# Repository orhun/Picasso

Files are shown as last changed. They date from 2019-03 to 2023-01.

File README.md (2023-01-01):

# Picasso 
PIC16F877A based 5V/20MHz development board and PIC programmer

**[!] This is a discontinued project. [2016]**
_Documents are published in order to help people that want to create similar projects or think of new ideas._

# Idea

Programming Microchip's PIC (_peripheral interface controller_)'s and preparing 
electronic circuit board takes time and also inconvenient in circuit testing process. 
In other words, using the appropriate PIC programmer and creating the proper circuit board according to
desired PIC's datasheet is not practical for situations that needs quick actions like prototyping.
In addition to that there is platforms like [Arduino](https://www.arduino.cc), so PIC is not preferable
except embedded applications.

Therefore, idea behind this project is creating a development board/prototyping platform using PIC.

# How?

[Sprut](https://www.sprut.de) is a project that aims to produce PIC programmer hardware with 
serial, parallel and USB techniques. 
(see [Brenner](http://www.sprut.de/electronic/pic/brenner/index.htm))
_Sprut Brenner_ is a preferred and common programmer board for universal PIC applications.

_Brenner board that I was using:_

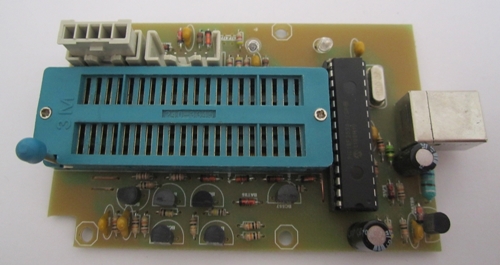
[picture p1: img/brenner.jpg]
sprut brenner


There is a 40 pin programmer on board for supporting most of the PIC's. The board itself uses PIC18F2550
(see [datasheet](http://ww1.microchip.com/downloads/en/DeviceDoc/39632e.pdf)) for communication
with software.

PIC16F877A (see [datasheet](http://ww1.microchip.com/downloads/en/devicedoc/39582b.pdf)) is a 40-pin microcontroller 
which is used frequently on PIC domain. (It has 256 bytes of EEPROM, 2 PWM 10-bit, ICD etc.)
This features of 877A was the main reason for my decision to use this microcontroller in this project.

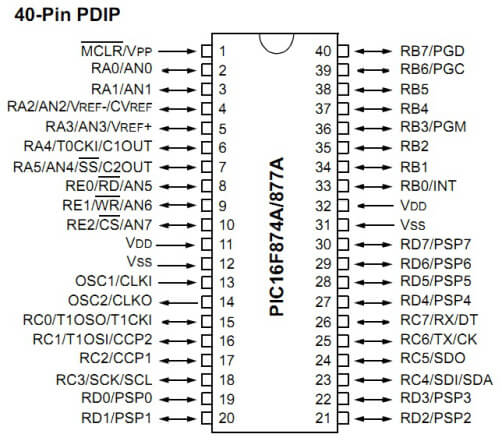
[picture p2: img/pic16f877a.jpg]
pic16f877a


In order to load your program to PIC (which is called _flashing hex file_) you have to use a software called _US-Burn_.
US-Burn also supports various features such as flashing bootloaders, changing PIC configurations and disassembler.
It has Windows and Linux support.

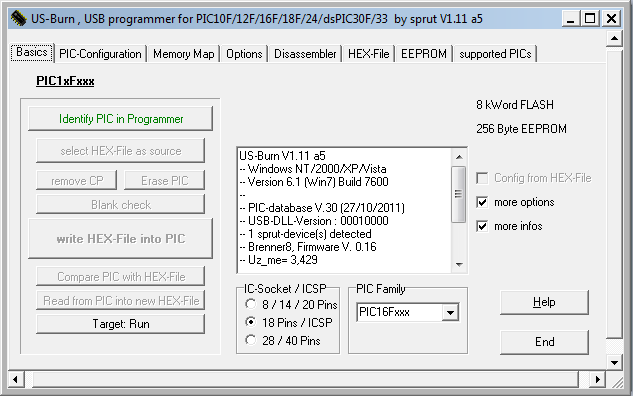
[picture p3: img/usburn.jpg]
usburn

[Get US-Burn here.](https://github.com/orhun/Picasso/raw/master/usburn/usburn.zip)

Basically if we replace the 40 pin programmer with 877A (or another PIC), put pins in order (like Arduino) and 
write a custom IDE with flashing features, we will have a 5V - 20MHz 877A-based development card. I'd like to call
it __PICasso.__

# v0.1

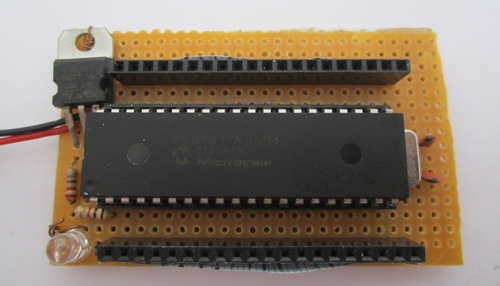
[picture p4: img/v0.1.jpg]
v0.1


Purpose of this version is seeing how easily can I use 877A's pins with the board above.

```
● PIC16F877A
● 7805
● 1K & 220
● LED
● 4MHz crystal osc.
● 2 x 22pF
```

# v0.2

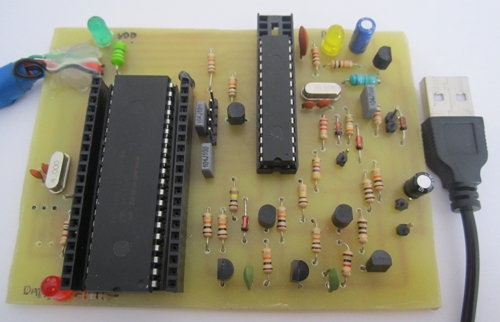
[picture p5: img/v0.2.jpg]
v0.2


This version can be considered as the outline of the Picasso project's main idea. 
18F2550 and 16F877A used together in this board with custom pins next to 877A due to testing our thesis.
Eventually, F2550 which is responsible for USB communication can be used with another microcontroller on the
same board and this version is open to any developments on the electronics (PCB) and the software side.

Here is the steps that followed for preparing this board:

* PCB

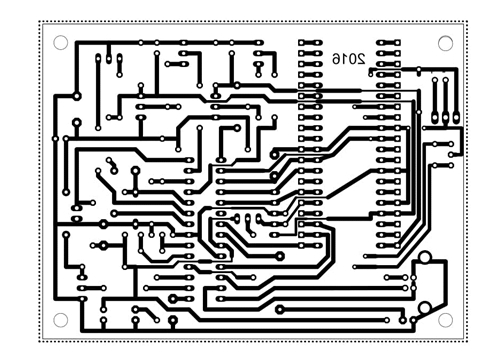
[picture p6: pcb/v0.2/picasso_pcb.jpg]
picasso_pcb_v0.2


[EAGLE Project](https://github.com/orhun/Picasso/blob/master/pcb/v0.2/picasso.brd) | 
[PCB](https://github.com/orhun/Picasso/blob/master/pcb/v0.2/picasso_pcb.pdf) 

* Circuit Part List

_Same as Sprut's Brenner except PIC16F77A, 20MHz osc., 22pF's, pins and couple of LED's. 
So here is the c/p part list:_

```
Part     Value			Reichelt	Conrad
===================================================
C1       220nF                 Z5U-2,5 220n
C2, C3   22p                   Kerko 22p
C4       10µF                  rad10/100
C5       47µF                  rad47/35
C6, C7   10nF                  X7R-2,5 10n
C8       100nF                 Z5U-5 100n
C9, C10  220nF                 Z5U-2,5 220n
D1 D2    BAT43                 BAT 43
D3       BZX97-3,3             ZF 3,3
IC1      PIC18F2550SP          PIC18F2550-I/SP
	 28-polige IC-Fassung  GS 28P-S
IC2      40-poliger Testsockel TEX 40
L1       680µH                 SMCC 680µ
L2       10µH                  SMCC 10µ
LED1     grün                  LED5mm2MAgn
LED2     gelb                  LED5mm2MAge
Q1       20 MHz                20-HC49U-S
Q2,Q3,Q5 BC338-25              BC338-25
Q4,Q6    BC328-25              BC328-25
R1       1k                    1/4W 1K
R2,R3,R6 10 k                  1/4W 10K  
R4       4k7                   1/4W 4,7K
R5       2k2                   1/4W 2,2K
R7,R13   10k                   1/4W 10K
R8,R12   100k                  1/4W 100K
R9..R11  10k                   1/4W 10K
R14      0 (Drahtbrücke)
R15      1 k                   1/4W 1K
R16      330                   1/4W 330
SV1      ICSP                  BL 1X10G 2,54
X2       USB-B-H               USB BW
JP1      Jumper                Jumper 2,54 RT
```
[Brenner Circuit](https://github.com/orhun/Picasso/blob/master/img/b8p5.jpg) and 
[b8p5_partlist.txt](https://github.com/orhun/Picasso/blob/master/doc/b8p5_partlist.txt) might be helpful.

* After preparing the circuit, there is not much left to do. We have to flash the bootloader and firmware to 
PIC18F2550 to use the board with US-Burn software.  
**To achieve this, a PIC programmer is required due to the need of bootloader flashing.**  

* Flash the [boot_0_20mhz.hex](https://github.com/orhun/Picasso/blob/master/bootloader/boot_0_20mhz.hex) to the 18F2550 
after US-Burn detected the PIC.
  
* After flashing the bootloader, put 18F2550 in your circuit and connect it's USB to your computer. Make sure everything is working with USB and circuit. (_Check if any smoke coming out_)  

* Start the US-Burn software. It will redirect you to firmware update section if everything goes right for you.

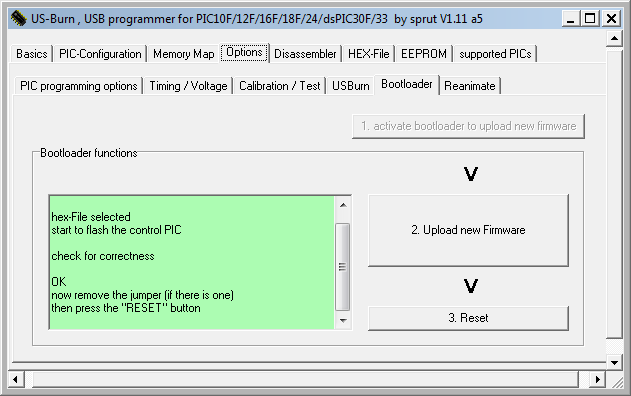
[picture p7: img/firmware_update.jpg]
firmware_update


* Select the [b8_fw16.hex](https://github.com/orhun/Picasso/blob/master/firmware/b8_fw16.hex) and upload new firmware.

* Reset the programmer. In this point you might have to make some calibrations. 
So see [b8_calibration_en.pdf](https://github.com/orhun/Picasso/blob/master/doc/b8_calibration_en.pdf)

* Finally put PIC16F877A in place and you are ready to go. You can flash your program (hex) into PIC and use it's pins
easily just by connecting the USB.

# v0.5

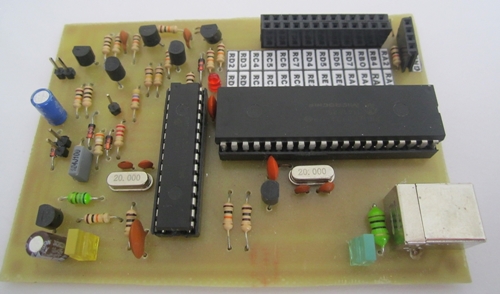
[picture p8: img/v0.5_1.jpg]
v0.5


Some circuit updates were made with this version.
* PIC16F877A placed horizontally.
* All pins gathered in one place. Required labels added.

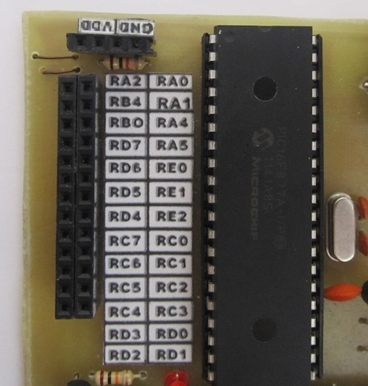
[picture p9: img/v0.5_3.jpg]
v0.5_pins


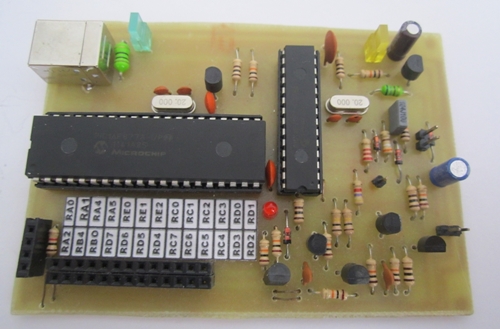
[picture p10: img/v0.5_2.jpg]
v0.5_2


* PCB

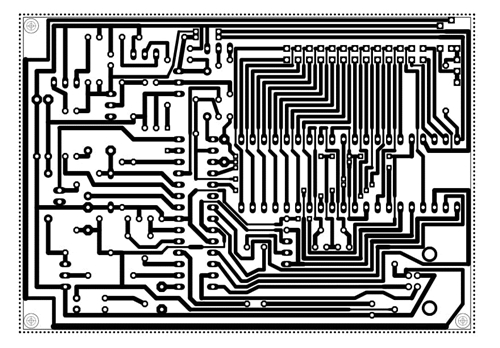
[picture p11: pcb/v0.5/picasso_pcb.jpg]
picasso_pcb_v0.5


[EAGLE Project](https://github.com/orhun/Picasso/blob/master/pcb/v0.5/picasso.brd) | 
[PCB](https://github.com/orhun/Picasso/blob/master/pcb/v0.5/picasso_pcb.pdf) 

* Circuit Part List

_Same components with v0.2_

* Instructions

_Same installation/configuration procedure with v0.2_

# v1.0

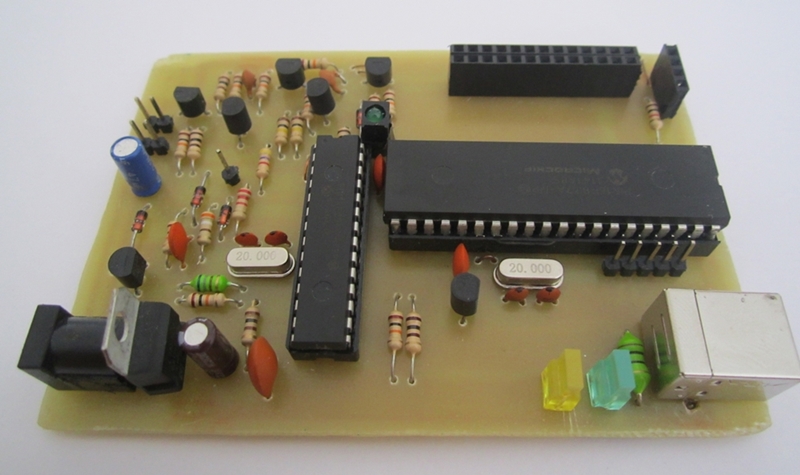
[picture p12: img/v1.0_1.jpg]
v1.0_1


Circuit board improved and new featured added with this version. 

* ICSP (_In-Circuit Serial Programming_) pins added for PIC16F877A.
* 5V input added to circuit with 7805 regulator.
* Some component's including LEDs position changed.

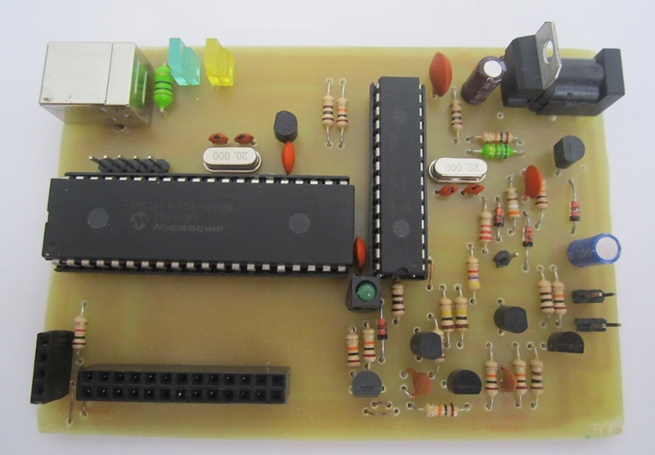
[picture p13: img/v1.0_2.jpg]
v1.0_2


* PCB

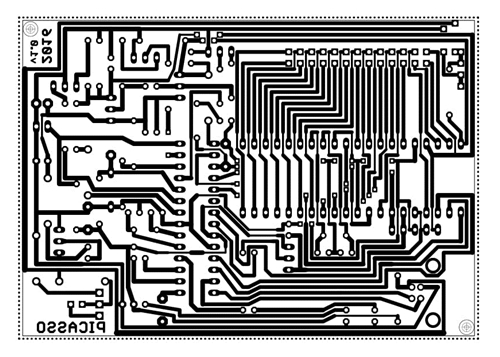
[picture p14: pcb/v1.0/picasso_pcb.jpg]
picasso_pcb_v1.0


[EAGLE Project](https://github.com/orhun/Picasso/blob/master/pcb/v1.0/picasso.brd) | 
[PCB](https://github.com/orhun/Picasso/blob/master/pcb/v1.0/picasso_pcb.pdf) 

_Components and instructions are same with v0.5_

# Missing Features

* There is no custom IDE or flashing software for Picasso. (_yet?_) So you have to use a third-party software
like MikroC to compile your code (create hex) & flash to PIC.

* Picasso uses Sprut Brenner's sources which is an inactive project.

**Demo will be added hopefully.**

## License

GNU General Public License ([v3](https://www.gnu.org/licenses/gpl.txt))

## Copyright

Copyright (c) 2016-2023, [orhun](https://www.github.com/orhun)

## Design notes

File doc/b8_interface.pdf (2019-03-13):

Brenner8 - Softwareinterface

- 1 -

# Das Software-Interface des Brenner8

Firmware V0.8

Autor: sprut (www.sprut.de) Stand: 04.09.2006

- 2 -

## 1 Inhaltsverzeichnis

- 3 -

- 4 -

## 2 NUTZUNGSBEDINGUNGEN:

DIE SOFTWARE DARF OHNE ENTRICHTUNG EINER LIZENZGEBÜHR BENUTZT WERDEN. DAS GILT FÜR DIE PRIVATE UND GEWERBLICHE NUTZUNG.

DIE PUBLIKATION DER SOFTWARE ERFOLGT "AS IS". FÜR DIE EINHALTUNG ZUGESICHERTER EIGENSCHAFTEN ODER FÜR SCHÄDEN, DIE DURCH DEN EINSATZ ENTSTANDEN SEIN KÖNNTEN, ÜBERNIMMT DER AUTOR KEINERLEI HAFTUNG. SIE NUTZEN DIE SOFTWARE AUF EIGENE GEFAHR!

## 3 Einleitung

Dieses Dokument beschreibt das Softwareinterface des Brenner8.

## 4 Das USB-Interface

Der Brenner8 ist ein bus-powered USB-2.0 Gerät.

Interface | | USB2.0 full speed
Stromversorgung | | bus powered
Stromaufnahme | | < 100 mA
VID | | 0x04D8
PID | | 0xFF0B
Anzahl der USB-Konfigurationen | 1
Anzahl der Interfaces | | 1
Anzahl der Endpunkte | 2

Endpunkt1:
Datenrichtung | | OUT
Betriebsart | Bootloader: | BULK
| Firmware: | Interrupt
Puffergröße | | 64 Byte

Endpunkt2:
Datenrichtung | | IN
Betriebsart | Bootloader: | BULK
| Firmware: | Interrupt
Puffergröße | | 64 Byte

USB-Timeouts:
Schreibzugriffe | | 100 ms
Lsezugriffe | | 1000 ms

- 5 -

## 5 Bootloader und Firmware

Der Bootblock des Steuer-PIC (Adressen 0x0000 ... 0x07FF) wird von der Bootloader Software eingenommen. Der restliche Adressbereich des Steuer-PIC-Programmspeichers steht für die Firmware zur Verfügung.

Bootloader und Firmware sind unabhängige und eigenständig lauffähige Programme. Beide initialisieren das USB-Interface auf identische Art und Weise. Unabhängig davon, ob der Bootloader oder die Firmware aktiv ist, identifiziert sich der Brenner8 gegenüber dem PC-Betriebssystem identisch.

Der Bootloader startet nach einem Reset des Steuer-PIC wenn mindestens eine der beiden folgenden Bedingungen erfüllt ist:

1. Das Pin 1 des Steuer-PIC liegt auf low-Pegel
2. Der Inhalt der EEPROM-Zelle ist der Adresse 0xFE ist 0xFF.

Ist keine der beiden Bedingungen erfüllt, startet beim Reset die Firmware des Brenner8.

- 6 -

## 6 Bootloader

### 6.1 Grundlagen

Der Bootloader im Brenner8 basiert auf den Microchip-Bootloader zum „PICDEM USB FS DEMOBOARD“.

Die Kommunikation erfolgt über beide Endpunkte und wird immer vom PC initiiert. Sie läuft immer nach folgendem Schema ab:
1. Der PC schreibt einen Datenblock in den out-Endpunkt.
2. Der Bootloader arbeitet daraufhin eine Aufgabe ab.
3. Der Bootloader schreibt Daten in den in-Endpunkt
4. Der PC list den Datenblock aus dem in-Endpunkt

Auch bei Aufgaben, die eigentlich keinen Datentransport zum PC erfordern, wird wenigstens ein 1 Byte-langer Datenblock als Quittung zum PC zurückgegeben.

Die nachfolgende Tabelle zeigt die Struktur der Datenblöcke, die zwischen PC und Bootloader ausgetauscht werden. Die maximale Länge eines Datenblocks ist auf 64 Byte begrenzt.
Die konkrete Länge hängt vom Kommando ab. Wenn ein Kommando weder eine Adresse noch Nutzdaten benötigt, dann kann ein Datenblock auch aus nur einem Byte (dem Kommando selbst) bestehen.

Wird vom PC ein Datenblock gesendet, der für das konkrete Kommando zu lang ist, dann werden die überflüssigen Bytes am Ende des Datenblocks ignoriert.
War der Datenblock zu kurz, und es fehlen essenzielle Daten am Ende des Datenblocks, dann werden die Daten benutzt, die sich zufällig im USB-Pufferspeicher befinden.

Generelle Datenstruktur :
| Adresse | Bedeutung
Kommando | 0x00 | Beschreibt die Aufgabe
Datenlänge | 0x01 | Anzahl der Datenbytes
Adresse low | 0x02 | Bits 0..7 des Adresse
Adresse high | 0x03 | Bits 8..15 des Adresse
Adresse upper | 0x04 | Bits 16..23 des Adresse
Datenbyte 1 | 0x05
Datenbyte 1 | 0x06
Datenbyte n | 0xFF

Folgende Kommandos werden vom Bootloader unterstützt:

Name des Kommandos | Code im Datenblock
READ_VERSION | 0x00
READ_FLASH | 0x01

- 7 -
WRITE_FLASH | 0x02
ERASE_FLASH | 0x03
READ_EEDATA | 0x04
WRITE_EEDATA | 0x05
READ_CONFIG | 0x06
WRITE_CONFIG | 0x07
RESET | 0xFF

Wird ein Datenblock mit einem anderen (nicht definiertem) Kommando empfangen, so wird der Datenblock vom Bootloader ignoriert. Es erfolgt auch keine Rücksendung eines Antwort-Datenblocks.

### 6.2 Befehle für den Bootloader

### 6.2.1 READ_VERSION

Da ich nur eine feste VID_PID für meine USB-Geräte habe, melden sich alle meine Geräte beim PC mit dieser VID_PID an. Mit dem READ_VERSION-Kommando kann man aus dem Gerät zwei Kennbytes auslesen. Eines identifiziert das Gerät, ein zweites kennzeichnet die Softwareversion/Firmwareversion des Gerätes.

PC -> Bootloader
Adresse | Bedeutung | Inhalt
0x00 | Kommando | 0x00

Der Bootloader sendet den Gerätecode 0x01.

Bootloader -> PC
Adresse | Bedeutung | Inhalt
0x00 | Kommando | 0x00
0x01 | keine | -
0x02 | Version | -
0x03 | Gerät | 0x01

### 6.2.2 READ_FLASH

Mit diesem Befehl kann der Inhalt des Programmspeichers des Steuer-PIC ausgelesen werden. Es können maximal 59 aufeinanderfolgende Bytes auf ein Mal ausgelesen werden. Die Adresse gibt an, ab welcher Adresse im Flash-Programmspeicher mit dem Auslesen begonnen werden soll

PC -> Bootloader
Adresse | Bedeutung | Inhalt
0x00 | Kommando | 0x01
0x01 | Datenlänge | 1 .. 59
0x02 | Adresse low
0x03 | Adresse high
0x04 | Adresse upper

- 8 -

Der Bootloader sendet den gleichen Datenblock zurück, an den aber die gesuchten Bytes angehangen wurden.

PC -> Bootloader
Adresse | Bedeutung | Inhalt
0x00 | Kommando | 0x01
0x01 | Datenlänge | 1 .. 59
0x02 | Adresse low
0x03 | Adresse high
0x04 | Adresse upper
0x05 | Datenbyte 1
0xXX | Datenbyte n

### 6.2.3 WRITE_FLASH

Mit diesem Befehl kann der Programmspeichers des Steuer-PIC beschrieben werden.
Es ist zwingend nötig, vor dem Schreiben den Flash-Speicherbereich mit dem ERASE_FLASH-Kommando zu löschen. Ansonsten werden die neuen Daten mit den alten Speicherinhalten UND-Verknüpft.

Es werden genau 16 aufeinanderfolgende Bytes auf ein Mal geschrieben. Die Adresse gibt an, ab welcher Adresse im Flash-Programmspeicher mit dem Schreiben begonnen werden soll. Die Startadresse muss am Beginn eines 16-Byte-Blocks liegen. Folglich sind die unteren 4 Bits der Adresse „0000“.

Wird eine andere Adresse angegeben, dann schreibt der Bootloader die Daten trotzdem ab dem Block-Anfang in den Flash. Ist die Datenlänge kleiner als 16 Byte, dann wird nichts geschrieben.

PC -> Bootloader
Adresse | Bedeutung | Inhalt
0x00 | Kommando | 0x02
0x01 | Datenlänge | 0x10
0x02 | Adresse low | 0xX0
0x03 | Adresse high
0x04 | Adresse upper
0x05 | Datenbyte 1
0x14 | Datenbyte 16

Der Bootloader sendet als Quittung nur das Kommando zurück.

PC -> Bootloader
Adresse | Bedeutung | Inhalt
0x00 | Kommando | 0x02

- 9 -

### 6.2.4 ERASE_FLASH

Mit diesem Kommando kann Flash-Speicher gelöscht werden. Das Löschen erfolgt immer in 64-Byte großen Speicherblöcken. Es können mit einem Mal mehrere aufeinanderfolgende 64-Byte-Blöcke gelöscht werden.
Der erste gelöschte Block ist derjenige auf den die Adresse verweist. Die niederwertigen 6 Bit der Adresse werden dabei ignoriert.

PC -> Bootloader
Adresse | Bedeutung | Inhalt
0x00 | Kommando | 0x03
0x01 | Anzahl der Blöcke
0x02 | Adresse low
0x03 | Adresse high
0x04 | Adresse upper

Der Bootloader sendet als Quittung nur das Kommando zurück.

PC -> Bootloader
Adresse | Bedeutung | Inhalt
0x00 | Kommando | 0x03

### 6.2.5 RESET

Mit diesem Kommando wird ein Reset des Steuer-PIC ausgelöst. Vorher meldet sich der Bootloader korrekt beim USB-Controller im PC ab.

PC -> Bootloader
Adresse | Bedeutung | Inhalt
0x00 | Kommando | 0xFF

Der Bootloader sendet KEINE Quittung an den PC zurück.

- 10 -

### 6.3 Ein Beispiel für die Nutzung des Bootloaders

Folgender Delphi-Code zeigt die Nutzung des Bootloaders. Sie benutzt die Prozedur Sende_Empfange(NrS, NrE).
Diese Routine sendet NrS Bytes aus dem Byte-Array send_buf zum USB-Device und empfängt anschließend NrE Bytes aus dem USB-Device in das Byte-Array receive_buf.
Beide Byte-Arrays sind je 64 Byte lang.

Der Bootloader wird mit READ_VERSION erkannt.
Anschließend wird der Programmspeicher des Steuer-PIC im Bereich vom 0x0800 bis 0x7FFF mit neuem Code beschrieben. Der neue Code stammt aus dem Array Hexin.Flash.
Danach wird der neu beschriebene Bereich des Steuer-PIC wieder ausgelesen, und mit Hexin.Flash verglichen, um eventuelle Fehler zu erkennen.
War alles fehlerfrei, dann wird die EEPROM-Zelle 0xFE des Steuer-PIC mit 0 beschrieben, und der Steuer-PIC neu „gebootet“.

// ist denn da ein Bootloader ?
send_buf[0]:=READ_VERSION; //0
Sende_Empfange(1, 4);
if (receive_buf[0] <> READ_VERSION) or (receive_buf[3]<>1) then exit;

//brennen
Adresse := $800;
Endadresse :=$7FFF;
while Adresse<Endadresse do begin
//64 byte löschen
send_buf[0]:= ERASE_FLASH;
send_buf[1]:= 1; | // 1 x 64 byte
send_buf[2]:= Adresse and $0000FF; | // low
send_buf[3]:= (Adresse and $00FF00) shr 8; // high send_buf[4]:= (Adresse and $FF0000) shr 16; // upper Sende_Empfange(5,1);
//4 x 16 byte schreiben
for k:=0 to 3 do begin
send_buf[0]:= WRITE_FLASH;
send_buf[1]:= 16; | // länge 16 Byte
send_buf[2]:= Adresse and $0000FF; | // low
send_buf[3]:= (Adresse and $00FF00) shr 8; // high send_buf[4]:= (Adresse and $FF0000) shr 16; // upper
for L:=0 to 15 do send_buf[5+L]:=Hexin.Flash[Adresse+L] and $FF; Sende_Empfange(21,1);
Adresse:=Adresse+16
end;
end;

//prüfen
Fehler:=0;
Adresse := $800;
Endadresse :=$7FFF;
while Adresse<Endadresse do begin

- 11 -

send_buf[0]:= READ_FLASH;

send_buf[1]:= 16; | // länge
send_buf[2]:= Adresse and $0000FF; | // low
send_buf[3]:= (Adresse and $00FF00) shr 8; | // high
send_buf[4]:= (Adresse and $FF0000) shr 16; | // upper
Sende_Empfange(5,send_buf[1]+5);

for k:=0 to receive_buf[1]-1 do begin
if (receive_buf[k+5] and $FF) <> (Hexin.Flash[Adresse+k] and $FF) then begin
inc(Fehler);
end;
end;
Adresse:=Adresse+16
end;

if Fehler=0 then begin
// EEPROM-Zellen 0xFE und 0xFF mit 0 beschreiben send_buf[0]:= WRITE_EEDATA;
send_buf[1]:= 2; | // länge 1 Byte
send_buf[2]:= $FE; | // low
send_buf[3]:= 0; | // high
send_buf[4]:= 0; | // upper
send_buf[5]:= 0;
send_buf[6]:= 0;
Sende_Empfange(7,1);

// neu booten
send_buf[0]:= RESET;
Sende_Empfange(1,0);

end else Memo.lines.add('Flash-Error');

- 12 -

## 7 Firmware

Die Firmware des Brenner8 Nimmt per USB Befehle vom PC entgegen, führ sie aus, und quittiert sie per USB. Sie liegt im Steuer-PIC des Brenner8 ab der Adresse 0x0800.

Die Kommunikation erfolgt über beide Endpunkte und wird immer vom PC initiiert. Sie läuft immer nach folgendem Schema ab:
1. Der PC schreibt einen Datenblock in den out-Endpunkt.
2. Die Firmware arbeitet daraufhin eine Aufgabe ab.
3. Die Firmware schreibt Daten in den in-Endpunkt
4. Der PC list den Datenblock aus dem in-Endpunkt

Auch bei Aufgaben, die eigentlich keinen Datentransport zum PC erfordern, wird wenigstens ein 1 Byte-langer Datenblock als Quittung zum PC zurückgegeben.

In jedem Datenblock ist das erste Byte das Kommando. Es beschreibt die Aufgabe für den Steuer-PIC. Die folgende Tabelle enthält eine Liste aller existierenden Kommandos:

Kommando | Code | Bedeutung
READ_VERSION | 0x00 | Lesen der Gerätekennung und der FW-Version
LED_ONOFF | 0x31 | Ein/Ausschalten von LEDs
RD_ADC | 0x37 | Messen einer Spannung
SET_AN | 0x38 | Auswahl des ADC-Eingangs
SET_PWM | 0x39 | Einstellen eines PWM-Verhältnisses
SET_SOC | 0x3A | Auswahl-PIC-Sockel
SET_SIGNAL | 0x3B | ICSP-Leitungen einzeln ein/aus-Schalten
SET_DIR | 0x3C | ICSP-Datenleitung auf lesen/schreiben schalten
READ_DATA | 0x3D | Lesen der ICSP-Datenleitung
ICSP_WRITE | 0x3E
ICSP_READ | 0x3F
SET_KERN | 0x40 | Auswahl der PIC-Familie
SET_PICTYPE | 0x41 | Alle nötigen Informationen über den PIC liefern
SET_ADRESS | 0x42 | Einstellen eines Adressbereichs
SET_VPP | 0x43 | Einstellen der Vpp-Spannung und der Stabilisierung
READ_EDATA | 0x44 | EEPROM des Steuer-PIC auslesen
WRITE_EDATA | 0x45 | EEPROM des Steuer-PIC beschreiben
READ_CHIPID | 0x50 | Aus dem Target die Chip-ID-Auslesen
READ_FLASH | 0x51 | Programmspeicher des Target lesen
READ_EEPROM | 0x52 | EEPROM des Target lesen
READ_IDDATA | 0x53 | ID-Daten des Target lesen
READ_CONFIG | 0x54 | Configuration des Target lesen

- 13 -
WRITE_FLASH | 0x60 | Programmspeicher des Target beschreiben
WRITE_EEPROM | 0x61 | EEPROM des Target beschreiben
WRITE_IDDATA | 0x62 | ID-Daten des Target beschreiben
WRITE_CONFIG | 0x63 | Konfiguration des Target beschreiben
ERASE | 0x70 | Target löschen
REMOVECP | 0x71 | Codeprotection des Target löschen (Bulk Erase)
RESET | 0xFF | Einen Reset des Steuer-PIC auslösen

### 7.1 Ablauf

Die Brennsoftware geht mit dem Brenner8 wie folgt um:

- Mit READ_VERSION wird überprüft, ob überhaupt ein Brenner8 vorhanden ist.
- Mit SET_AN und READ_ADC wird die Spannung der Z-Diode gemessen, und daraus die Betriebsspannung errechnet, die auch ADC-Referenzspannung ist. Ein ADC Korrekturwert für spätere ADC-Messungen wird errechnet.
- Danach wird mit SET_SOC die elektrische Verbindung zum Target festgelegt.
- Mit SET_KERN wird die PIC-Familie festgelegt.
- Nun wird mit SET_PWM eine Standard-Programmierspannung (12..13V) eingestellt und mit SET_AN und READ_ADC überprüft.
- Mit READ_CHIPID wird der Typ des Target identifiziert.
- Für das identifizierte Target werden alle nötigen Daten aus der PIC-Database ausgelesen, und an den Brenner8 mit SET_PICTYPE übertragen.
- Mit SET_PWM wird die korrekte Programmierspannung eingestellt und mit SET_AN und READ_ADC überprüft.
- Mit ERASE und/oder REMOVECP wird das Target gelöscht.
- Mit SET_ADRESS und vielen WRITE_FLASH wird der Programmspeicher des Target beschrieben.
- Mit SET_ADRESS und vielen READ_FLASH wird der Programmspeicher des Target ausgelesen, und mit dem Sollinhalt verglichen.
- Sinngemäß passiert das gleiche mit EEPROM, ID und CONFIG.
- fertig

### 7.2 Allgemeine Kommandos

### 7.2.1 READ_VERSION

Da ich nur eine feste VID_PID für meine USB-Geräte habe, melden sich alle meine Geräte beim PC mit dieser VID_PID an. Mit dem READ_VERSION-Kommando kann man aus dem Gerät zwei Kennbytes auslesen. Eines identifiziert das Gerät, ein zweites kennzeichnet die Softwareversion/Firmwareversion des Gerätes.

- 14 -

PC -> Brenner8
Adresse | Bedeutung | Inhalt
0x00 | Kommando | 0x00

Der Brenner8 sendet den Gerätecode 0x00. Als Version wird die Firmwareversion gesendet (0x06 entspricht V 0.6).

Brenner8 -> PC
Adresse | Bedeutung | Inhalt
0x00 | Kommando | 0x00
0x01 | keine | -
0x02 | Version | -
0x03 | Gerät | 0x00

### 7.2.2 LED_ONOFF

Mit diesem Kommando können die beiden LED des Brenner8 ein- und ausgeschaltet werden.

PC -> Brenner8
Adresse | Bedeutung | Inhalt
0x00 | Kommando | 0x31
0x01 | Status | 0, 1, 4, oder 5

Für das Status-Byte sind folgende Werte definiert:

Status-Wert | Wirkung
0 | LED1 einschalten
1 | LED2 einschalten
4 | LED1 ausschalten
5 | LED2 ausschalten

Bei einem gültigen Status-Wert liefert der Brenner8 nur das Kommando als Quittung. Ein ungültiger Status-Wert wird nicht quittiert.

Brenner8 -> PC
Adresse | Bedeutung | Inhalt
0x00 | Kommando | 0x31

### 7.2.3 RD_ADC

Es wird die Spannung am gerade selektierten Eingang (siehe SET_AN) des ADC gemessen.

PC -> Brenner8
Adresse | Bedeutung | Inhalt
0x00 | Kommando | 0x37

- 15 -

Der Brenner8 sendet das 10-Bit Resultat des ADC. ADRESL sind die unteren 8 Bit des Ergebnisses und ADRESH die beiden oberen Bits.

Brenner8 -> PC
Adresse | Bedeutung | Inhalt
0x00 | Kommando | 0x37
0x01 | ADRESL | -
0x02 | ADRESH | -

Als positive Referenzspannung für den ADC dient die Betriebsspannung, die bei etwa 4,7V liegt. Ihr präziser Wert lässt sich bestimmen, wenn man zum Vergleich die (bekannte) Z.-Dioden-Spannung misst.
Die Vpp-Spannung wird dem ADC-Pin über einen Spannungsteiler mit einem Teilverhältnis von ca. 3.14:1 zugeführt.
Der genaue Wert der Z-Spannung sowie des Spannungsteilerverhältnisses wird durch Kalibrierung ermittelt, und im EEPROM des Steuer-PIC abgespeichert.

### 7.2.4 SET_AN

Der ADC kann wahlweise benutzt werden die Programmierspannung Vpp oder die Z-Diodenspannung Uz zu messen. Bevor die eigentliche Messung mit RD_ADC vorgenommen wird, muß mit SET_AN der richtige ADC-Eingang ausgewählt werden.

PC -> Brenner8
Adresse | Bedeutung | Inhalt
0x00 | Kommando | 0x38
0x01 | ADC-Eingang | 0 – Vpp 1 - Uz

Ist „ADC-Eingang = 0“, dann wird der Vpp-Eingang (RA1/AN1) ausgewählt. Ansonsten wird der Zu-Eingang (RA3/AN3) selektiert.

Der Brenner8 sendet nur das Kommando als Quittung.

Brenner8 -> PC
Adresse | Bedeutung | Inhalt
0x00 | Kommando | 0x38

### 7.2.5 SET_PWM

Die Programmierspannung wird im Brenner8 mit einem Boost-Konverter erzeugt, der vom PWM-Kanal 1 „gepumpt“ wird.
Die erzeugte Ausgangsspannung hängt vom Taktverhältnis der PWM-Kanals sowie von der Last an der Vpp-Leitung ab. Mit SET_PWM wird das Taktverhältnis eingestellt, wobei gilt DC = 120/pwm_off. Die erzeugte Spannung steigt mit dem pwm_off Wert an.
- bei pwm_off=0 beträgt sie ca. 4,5V.
- bei pwm_off=70 erreicht sie ihr Maximum (25 .. 30V).

- 16 -

pwm_off ist der primär verwendete PWM-Wert. Je nach Betriebsart der Vpp-Erzeugung (siehe SET_VPP) kann beim Zuschalten von Vpp zum Target auf pwm_on umgeschaltet werden:

In der Theorie beträgt die erzeugte Spannung:

Vpp = 4,7V * 120 /(120-pwm_off)

In der Praxis werden die für eine bestimmte Spannung (VppSoll) nötigen pwm-Werte wie folgt ermittelt:

pwm_off:= VppSoll * gain_off - pwm0V_off
pwm_on := VppSoll * gain_on - pwm0V_on;

Die Werte gain_off, gain_on, pwm0V_off und pwm0V_on werden durch Kalibrierung ermittelt, und im EEPROM des Steuer-PIC abgespeichert.

Beim Reset wird ein Default-Wert von pwm_off=12 benutzt, um eine ungefährliche Vpp von deutlich unter 13V zu erzeugen.

PC -> Brenner8
Adresse | Bedeutung | Inhalt
0x00 | Kommando | 0x39
0x01 | pwm_off | 0 70
0x02 | pwm_on | 0..70

Der Brenner8 sendet nur das Kommando als Quittung.

Brenner8 -> PC
Adresse | Bedeutung | Inhalt
0x00 | Kommando | 0x39

### 7.3 Kommandos für Testfunktionen

### 7.3.1 SET_SIGNAL

Zum Programmieren des Target ist dieser Befehl nicht nötig. Er dient nur zum Test der Hardware bei der Fehlersuche, sowie zur Kalibrierung.

Mit diesem Kommando können die 5 Signale des ICSP-Anschlusses am Testsockel bzw. am ICSP-Steckverbinder einzeln ein- und ausgeschaltet werden.

PC -> Brenner8
Adresse | Bedeutung | Inhalt
0x00 | Kommando | 0x3B
0x01 | Befehl | 0x01, 0x02, 0x04, 0x08 0x10, 0x20, 0x40, 0x80

Für das Befehl-Byte sind folgende Werte definiert:

- 17 -
Befehl-Wert | Wirkung
0x01 | Vdd (&Vss) einschalten
0x10 | Vdd (&Vss)ausschalten
0x02 | Vpp einschalten
0x20 | Vpp ausschalten
0x04 | PGD high
0x40 | PGD low
0x08 | PGC high
0x80 | PGC low

Trotz der bitweisen Codierung kann immer nur ein Pin geschaltet werden. Welche Pins genau geschaltet werden hängt von der mit SET_SOC gemachten Einstellung ab. Wurde mit SET_SOC die Einstellung „8/14-Pin“ gemacht, dann wird mit Vdd (+5V) auch Vss (0V) geschaltet.
Bei einem gültigen Befehl-Wert liefert der Brenner8 nur das Kommando als Quittung. Ein ungültiger Befehl-Wert wird nicht quittiert.

Brenner8 -> PC
Adresse | Bedeutung | Inhalt
0x00 | Kommando | 0x3B

### 7.3.2 SET_DIR

Zum Programmieren des Target ist dieser Befehl nicht nötig. Er dient nur zum Test der Hardware bei der Fehlersuche.

Mit diesem Kommando kann die Datenleitung des ICSP-Anschlusses als Eingang oder Ausgang eingestellt werden. Benutzt wird der Befehl ausschließlich zu Test der Datenleitung im Rahmen der Fehlersuche. Soll mit dem READ_DATA Kommando der Pegel des PGD-Pins gelesen werden, dann ist das Pin des Steuer-PIC vorher mit dem Befehl 0x00 zum Eingang zu machen. Soll der Steuer-PIC aber mit
SET_SIGNAL das PGD-Pin auf high oder low setzen, dann muss zuvor z.B. mit dem Befehl 0x01 das PGD-Pin des Steuer-PIC zum Ausgang gemacht werden. Welches Pin das PGD-Pin ist, dass hängt von der mit SET_SOC gemachten Einstellung ab.

PC -> Brenner8
Adresse | Bedeutung | Inhalt
0x00 | Kommando | 0x3C
0x01 | Befehl | 0, other

Für das Befehl-Byte sind folgende Werte definiert:

Befehl-Wert | Wirkung
0x00 | PGD wird Eingang des Steuer-PIC und Ausgang des Target
0x01 .. 0xFF | PGD wird Ausgang des Steuer-PIC und Eingang des Target

- 18 -

Bei einem gültigen Befehl-Wert liefert der Brenner8 nur das Kommando als Quittung. Ein ungültiger Befehl-Wert wird nicht quittiert.

Brenner8 -> PC
Adresse | Bedeutung | Inhalt
0x00 | Kommando | 0x3C

### 7.3.3 READ_DATA

Zum Programmieren des Target ist dieser Befehl nicht nötig. Er dient nur zum Test der Hardware bei der Fehlersuche.

Mit diesem Kommando der Pegel der Datenleitung des ICSP-Anschlusses abgefragt werden:

PC -> Brenner8
Adresse | Bedeutung | Inhalt
0x00 | Kommando | 0x3D

Der Brenner8 antwortet mit dem Kommando gefolgt von einem Byte. Falls am PGD-Pin low-Pegel anliegt ist dieses Byte=0, ansonsten ist es 1.

Brenner8 -> PC
Adresse | Bedeutung | Inhalt
0x00 | Kommando | 0x3B
0x01 | PGD-Wert | 0,1

### 7.4 Kommandos für den Steuer-PIC

### 7.4.1 SET_SOC

Je nach Gehäusebauform des Target muss der Steuer-PIC das ICSP-Protokoll mit anderen Pins erzeugen. Deshalb muss dem Brenner8 vor dem ersten Zugriff auf ein Target die Gehäusegröße des Target im IC-Sockel mitgeteilt werden.

Die für Sockel zulässigen Werte sind 0, 1 und 2. Falls der ICSP-Steckverbinder benutzt werden soll, dann ist Sockel=1 zu wählen.
Beim Reset wird ein Default-Wert von Sockel=1 benutzt.

Wird ein ungültiger Sockel-Wert verwendet, dann erzeugt der Steuer-PIC keine ICSP-Signale. Die Pins 2, 4 und 5 des ICSP-Steckers sind hochohmig. Ab der Brenner-Revision 3 liegt am Pin 1 in diesem Fall 5V (hochohmig).

Falls beim Empfang des Kommandos Vpp zum Target zugeschaltet war, so wird die Spannung deaktiviert.

PC -> Brenner8
Adresse | Bedeutung | Inhalt
0x00 | Kommando | 0x3A

- 19 -
0x01 | Sockel | 0 – 8 / 14 Pin 1 – 18Pin / ICSP 2 – 28 / 40 Pins

Der Brenner8 sendet nur das Kommando als Quittung.

Brenner8 -> PC
Adresse | Bedeutung | Inhalt
0x00 | Kommando | 0x3A

### 7.4.2 SET_KERN

Je nach PIC-Familie müssen völlig unterschiedliche Verfahren bei der Kommunikation mit dem Target verwendet werden. Deshalb muss dem Brenner8 vor dem ersten Zugriff auf ein Target die Befehlsbreite des PIC-Kerns des Target mitgeteilt werden.

Die für Kern zulässigen Werte sind 12, 14 und 16. Die Routinen für Kern=12 sind aber noch nicht vollständig fertig. Zukünftig wird für dsPICs der Kern-Wert 30 eingeführt werden.
Beim Reset wird ein Default-Wert von Kern=14 benutzt.

PC -> Brenner8
Adresse | Bedeutung | Inhalt
0x00 | Kommando | 0x40
0x01 | Kern | 12 – ~PIC12Fxxx 14 – ~PIC16Fxxx 16 – PIC18Fxxxx 30 – dsPIC30Fxxxx

Der Brenner8 sendet nur das Kommando als Quittung.

Brenner8 -> PC
Adresse | Bedeutung | Inhalt
0x00 | Kommando | 0x40

### 7.4.3 SET_PICTYPE

Für das korrekte Flashen des Target benötigt der Brenner8 eine große Anzahl von Informationen. Diese werden dem Brenner8 mit dem Kommando SET_PICTYPE übertragen. Ab dem 2. Byte des Datensatzes (Adresse 0x01) steht eine 34 Byte lange Datenstruktur, deren Definition im grauen Feld unten beschrieben ist.

Die Daten stammen aus der PIC-Database.
Beim Reset werden alle Werte von taktik auf 0 gesetzt, und power mit 40 beschrieben.

PC -> Brenner8
Adresse | Bedeutung | Inhalt

- 20 -
0x00 | Kommando | 0x41
0x01 ... 0x22 | PICtype

Der Brenner8 sendet nur das Kommando als Quittung.

Brenner8 -> PC
Adresse | Bedeutung | Inhalt
0x00 | Kommando | 0x41
typedef struct T_taktik | // 7 Byte
{
byte | flash;
byte | eeprom;
byte | id;
byte | config;
byte | erase;
byte | cp;
byte | read_eeprom;
} T_taktik;
typedef struct T_latches | // Schreibpuffergrößen in Byte
// 5 Byte
{
byte | pgm ;
byte | eedata;
byte | userid;
byte | cfg;
byte | rowerase; | // Löschbereich
| | // in Byte
} T_latches;
typedef struct T_wait | // alle Brenn-Zeiten in Mikrosekunden
// 14 Byte
{
word | pgm;
word | lvpgm;
word | eedata;
word | cfg;
word | userid;
word | erase;
word | lverase;
} T_wait;
typedef struct T_PICtype | // 8 + 7 + 5 + 14 = 34 Byte
{
byte | kommando;
byte | cpu;
byte | power;
unsigned int blocksize;
byte | pins;
byte | vpp;
word | panelsize;

- 21 -
T_taktik | taktik;
T_latches | latches;
T_wait | wait;
} T_PICtype;

### 7.4.4 SET_ADRESS

Mit diesem Befehl wird festgelegt, auf welchen Adressbereich sich die nächsten Schrei- und Leseoperationen zum und vom Target beziehen. Deshalb ist SET_ADRESS vor dem Zugriff auf den Flash-Programmspeicher, EEPROM, ID-Bereich und Config anzuwenden.

Anfang: Adresse der ersten Zelle die gebrannt oder gelesen werden soll
Ende: Adresse der letzten Zelle die gebrannt oder gelesen werden soll

Anfang und Ende sind 24-Bit lange Werte, die in jeweils 3 Byte übertragen werden.

PC -> Brenner8
Adresse | Bedeutung | Inhalt
0x00 | Kommando | 0x42
0x01 | Anfang_low | Bit 0..7
0x02 | Anfang_high | Bit 8..15
0x03 | Anfang_upper | Bit 16..23
0x04 | Ende_low | Bit 0..7
0x05 | Ende_high | Bit 8..15
0x06 | Ende_upper | Bit 16..23

Der Brenner8 sendet nur das Kommando als Quittung.

Brenner8 -> PC
Adresse | Bedeutung | Inhalt
0x00 | Kommando | 0x42

### 7.4.5 SET_VPP

Dieser Befehl steuert die Stabilisierung der Programmierspannung, und ist momentan noch eine Baustelle.
Prinzipiell wird ein 10-Bit-Wert übergeben. Er entspricht Messergebnis, das der ADC beim Messen von Vpp liefern sollte. Die niederwertigen 8 Bit sind VppL und die oberen 2 Bit VppH. Die 6 höherwertigen Bits in VppH stehen für Steuerzwecke zur Verfügung.

Es gibt 4 Modes, von denen aber z.Z. nur 2 Modes zur Verwendung zugelassen sind:
- Mode0: | keine Regelung
- Mode 3: | Begrenzung

Keine Regelung
Wird VppL=VppH=0 übergeben, wird jegliche Regelung und Überwachung von Vpp deaktiviert. Die mit SET_PWM eingestellten Werte werden unverändert benutzt. Das ist z.B. zu Testzwecken oder zur Kalibrierung nötig.

- 22 -

Begrenzung
Die einzige von mir z.Z. zur Nutzung freigegebene und empfohlene Stabilisierungsmethode ist der Begrenzungsbetrieb (Mode 3). Er wird aktiviert, wenn in VppH Das Bit 6 auf 1 gesetzt wird.
Der Brenner8 benutzt nun die bei SET_PWM übergebenen Werte für den Boost-Konverter zur Vpp Erzeugung. Solange Vpp nicht zum Target zugeschaltet ist wird vpp_off verwendet. Wird Vpp zum Target geschaltet wird vpp_on verwendet. Regelmäßig wird die Vpp-Spannung mit dem ADC gemessen, und der Messwert mit VppH_VppL verglichen. Ist die Spannung zu hoch, wird sie durch Verringerung von vpp_on bzw. vpp_off verkleinert. Eine Heraufsetzung der Vpp-Spannung erfolgt dagegen nicht.
Falls Vpp über ca.14V (ADC-Wert>1000) ansteigen sollte, erfolgt eine Notabschaltung von Vpp und die grüne LED wird dauerhaft eingeschaltet.

PC -> Brenner8
Adresse | Bedeutung | Inhalt
0x00 | Kommando | 0x43
0x01 | VppL | 0xXX
0x02 | VppH | 0x4X

Die Verwendung eines nicht zugelassenen Modes kann zur Zerstörung des Target führen!

Mode | Regelverfahren | Aktivieren durch | zugelassen
Mode 0 | Keine Regelung | VppL=VppH=0 | Ja
Mode 1 | Kontinuierliche Regelung | VppH & 0xFC=0 | Nein
Mode 2 | Regelung nur nach Vpp-Schaltung | VppH & 0x80=0x80 | Nein
Mode 3 | Begrenzung | VppH & 0x40=0x40 | ja

Der Brenner8 sendet nur das Kommando als Quittung.

Brenner8 -> PC
Adresse | Bedeutung | Inhalt
0x00 | Kommando | 0x43

### 7.4.6 READ_EDATA

Mit diesem Befehl kann der EEPROM des Steuer-PIC ausgelesen werden. Das ist z.B. nötig, wenn man die im Brenner abgelegten Kalibrierdaten auslesen muss. Übertragen wird mit dem Kommando die Startadresse im EEPROM als 16-Bit-Wert. Da der Steuer-PIC PIC18F2550 nur die EEPROM-Adressen 0x00 bis 0xFF kennt, bleibt in der Praxis der High-Teil der Adresse unbenutzt. Es können mit einem Befehl maximal 59 Bytes ausgelesen werden.

PC -> Brenner8
Adresse | Bedeutung | Inhalt
0x00 | Kommando | 0x44
0x01 | Anfang _low | Bit 0..7
0x02 | Anfang_high | 0x00

- 23 -
0x03 | Zahl der Bytes | 0x01 ..0x3B

Der Brenner8 die vom PC empfangenen 4 Byte, ergänzt um die gewünschten Datenbytes aus dem EEPROM. Der Antwortblock ist im Übrigen immer 63 Bytes lang. In den von den Daten nicht benötigten Zellen stehen Zufallswerte.

Brenner8 -> PC
Adresse | Bedeutung | Inhalt
0x00 | Kommando | 0x44
0x01 | Anfang _low | Bit 0..7
0x02 | Anfang_high | 0x00
0x03 | Zahl der Bytes | 0x01 ..0x3B
0x04 | Datenbyte 1
0xXX | Letztes Datenbyte
0x3E | - | -

### 7.4.7 WRITE_EDATA

Mit diesem Befehl können Daten in den EEPROM des Steuer-PIC geschrieben werden. Das ist z.B. nötig, wenn man Kalibrierdaten im Brenner ablegen möchte, oder um den Bootloader zu aktivieren.
Übertragen wird mit dem Kommando die Startadresse im EEPROM als 16-Bit-Wert. Da der Steuer-PIC PIC18F2550 nur die EEPROM-Adressen 0x00 bis 0xFF kennt, bleibt in der Praxis der High-Teil der Adresse unbenutzt.

Es können mit einem Befehl maximal 59 Bytes geschrieben.

PC -> Brenner8
Adresse | Bedeutung | Inhalt
0x00 | Kommando | 0x45
0x01 | Anfang _low | Bit 0..7
0x02 | Anfang_high | 0x00
0x03 | Zahl der Bytes | 0x01 ..0x3B
0x04 | Datenbyte 1
0xXX | Letztes Datenbyte
0x3E | - | -

Der Brenner8 sendet nur das Kommando als Quittung.

Brenner8 -> PC
Adresse | Bedeutung | Inhalt
0x00 | Kommando | 0x45

- 24 -

### 7.4.8 RESET

Mit diesem Kommando wird ein Reset des Steuer-PIC ausgelöst. Vorher meldet sich der Brenner8 korrekt beim USB-Controller im PC ab.

PC -> Bootloader
Adresse | Bedeutung | Inhalt
0x00 | Kommando | 0xFF

Der Brenner8 sendet KEINE Quittung an den PC zurück.

### 7.5 Kommandos zum Programmieren des Target

### 7.5.1 READ_CHIPID

Jeder moderne Flash-PIC (alle außer PIC16F84/83) besitzt einen Identifizierungscode, den man auslesen kann. Damit lässt sich der PIC-Typ identifizieren.
Die Brennersoftware liest die ChipID aus, und entnimmt auf Grundlage der ChipID aus der PIC-Database alle nötigen Informationen über den PIC. Diese werden dann mit SET_PICTYPE an den Brenner8 übertragen.

Vor diesem Kommando müssen sowohl Sockel (SET_SOC) als auch Kern (SET_KERN) korrekt eingestellt sein.

PC -> Brenner8
Adresse | Bedeutung | Inhalt
0x00 | Kommando | 0x50

Der Brenner8 sendet nur das Kommando als Quittung.

Brenner8 -> PC
Adresse | Bedeutung | Inhalt
0x00 | Kommando | 0x50
0x01 | ChipID_low
0x02 | ChipID_high

### 7.5.2 READ_FLASH

Mit diesem Kommando lässt sich ein beliebiger Teil des Flash-Programmspeicher des Targets in kurzer Zeit auslesen.
Bevor man den Programmspeicher mit READ_FLASH auslesen kann, muss man den interessierenden Speicherbereich mit SET_ADRESS festgelegt haben. Danach startet man die Leseprozedur mit dem Aufruf von READ_FLASH

PC -> Brenner8
Adresse | Bedeutung | Inhalt
0x00 | Kommando | 0x51

- 25 -

Der Brenner8 sendet daraufhin einen Datenblock mit zurück. Er besteht aus einem 3 Bytes langem Kopf und einem angehängten Datenblock. Die Länge des übertragenen Datenblocks (in Byte ) steht an der Adresse 0x01.

Da der Programmspeicher eines 14-Bit-PIC breiter als 1 Byte ist, belegt eine Flash-Zelle mehrere Bytes. Die Übertragung erfolgt little endian (Low-Byte zuerst).

Der Programmspeicher eines 16-Bit-PIC ist im Grunde byteweise aufgebaut, so dass jedes Byte einer Flash-Adresse entspricht, es aber auch ungerade Flash-Adressen gibt.

Die Adresse 0x02 ist nur dann „Null“, wenn der mit dem aktuellen Datenblock das Ende des mit SET_ADRESS festgelegten Adressbereichs erreicht wurde. Ist das Endekennzeichen aber nicht „Null“, dann können mit weiteren READ_FLASH-Befehlen weitere Datenblöcke ausgelesen werden Ein weiteres SET_ADRESS ist nicht nötig.

Brenner8 -> PC
Adresse | Bedeutung | Inhalt
0x00 | Kommando | 0x51
0x01 | Anzahl der Bytes
0x02 | Ende-Kennzeichen | 0 – Ende
0x03 | Byte Nr1
0xXX | letztes Byte

### 7.5.3 READ_EEPROM

Dieser Befehl funktioniert analog zum READ_FLASH-Befehl. Es wird aber der EEPROM des Target ausgelesen. Der EEPROM-Adressbereich beginnt an der Adresse 0x00.

PC -> Brenner8
Adresse | Bedeutung | Inhalt
0x00 | Kommando | 0x52

Brenner8 -> PC
Adresse | Bedeutung | Inhalt
0x00 | Kommando | 0x52
0x01 | Anzahl der Bytes
0x02 | Ende-Kennzeichen | 0 – Ende
0x03 | Byte Nr1
0xXX | letztes Byte

- 26 -

### 7.5.4 READ_IDDATA

Dieser Befehl funktioniert analog zum READ_FLASH-Befehl. Es wird aber der ID-Bereich des Target ausgelesen.
Als Adressen sind die echten ID-Adresssen des PIC zu verwenden (stehen in der Database). Das sind :
- für PIC16Fxxx: | 0x2000 ... 0x2003
- für PIC18Fxxxx: | 0x200000 ... 0x200007

PC -> Brenner8
Adresse | Bedeutung | Inhalt
0x00 | Kommando | 0x53

Da die ID immer in einem Block übertragen werden kann, ist das Endekennzeichen eigentlich überflüssig. Es ist aus Gründen der Vereinheitlichung aber vorhanden.

Wie beim Flash erfolgt für 14-Bit-PICs die Übertragung einer ID-Zelle mit 2 Bytes (low-Byte zuerst), auch wenn von den übertragenen 2 Bytes in Wirklichkeit nur die untersten 4 Bit für die ID nutzbar sind.

Brenner8 -> PC
Adresse | Bedeutung | Inhalt
0x00 | Kommando | 0x53
0x01 | Anzahl der Bytes
0x02 | Ende-Kennzeichen | 0 – Ende
0x03 | Byte Nr1
0xXX | letztes Byte

### 7.5.5 READ_CONFIG

Dieser Befehl funktioniert analog zum READ_FLASH-Befehl. Es wird aber der Config-Bereich des Target ausgelesen.
Als Adressen sind die echten Config-Adresssen des PIC zu verwenden (stehen in der Database). Das sind :
- für PIC16Fxxx: | 0x2007 ... 0x2007
- für PIC18Fxxxx: | 0x300000 ... 0x30000D

PC -> Brenner8
Adresse | Bedeutung | Inhalt
0x00 | Kommando | 0x54

Da die Config immer in einem Block übertragen werden kann, ist das Endekennzeichen eigentlich überflüssig. Es ist aus Gründen der Vereinheitlichung aber vorhanden.

- 27 -

Wie beim Flash erfolgt für 14-Bit-PICs die Übertragung einer Config-Zelle mit 2 Bytes (low-Byte zuerst).

Brenner8 -> PC
Adresse | Bedeutung | Inhalt
0x00 | Kommando | 0x54
0x01 | Anzahl der Bytes
0x02 | Ende-Kennzeichen | 0 – Ende
0x03 | Byte Nr1
0xXX | letztes Byte

### 7.5.6 WRITE_FLASH

Mit diesem Kommando lässt sich ein beliebiger Teil des Flash-Programmspeicher des Targets in kurzer Zeit beschreiben.
Bevor man den Programmspeicher mit WRITE_FLASH beschreiben kann, muss man den interessierenden Speicherbereich mit SET_ADRESS festgelegt haben. Danach startet man die Schreibprozedur mit dem Aufruf von WRITE_FLASH.
Wurde mit SET_ADRESS versehentlich eine Start-Adresse hinter der End-Adresse festgelegt, dann verweigert WRITE_FLASH die Arbeit.
Bei der Festlegung des Adressbereichs muss nicht auf eventuelle Block- oder Flash-Zeilengrenzen Rücksicht genommen werden. (im Gegensatz zum Bootloader)

Das an den Brenner8 übertragene Packet besteht aus einem 3 Byte langem Kopf und angehängtem Datenblock. An der Adresse 0x01 steht die Länge dieses Datenblocks in Byte.
An der Adresse 0x02 steht das Endekennzeichen. Dieses ist nötig, da sich mit einem USB-Transfer nur ein Bruchteil der Flash-Daten übertragen lässt. Solange das Endekennzeichen „1“ ist, beendet der Brenner das Brennen nicht, sondern wartet auf weitere WRITE_FLASH-Befehle mit weiteren Datenblöcken. Ist das Endekennzeichen aber „0“, dann beendet der Brenner nach dem Brennen dieses Datenblocks die Brennfunktion.
Sollte das Ende des mit SET_ADRESS definierten Speicherbereichs erreicht sein, ohne dass das Endekennzeichen gesetzt ist, wird das Brennen ebenfalls abgebrochen.

Die Flash-Worte von 14-Bit-PICs werden immer in 2 Bytes übertragen (low Byte zuerst). Folglich ist dann die Byteanzahl (Adresse 0x01) das Doppelte der Flash-Zellenzahl im Datenblock). US-Burn überträgt pro USB-Transfer jeweils 60 Datenbyte.

PC -> Brenner8
Adresse | Bedeutung | Inhalt
0x00 | Kommando | 0x60
0x01 | Zahl der Bytes
0x02 | Endekennzeichen | 0 – letztes Packet

- 28 -
0x03 | Byte N. 1
0xXX | letztes Byte

Der Brenner8 sendet nach dem Brennen des Blocks nur das Kommando als Quittung.

Brenner8 -> PC
Adresse | Bedeutung | Inhalt
0x00 | Kommando | 0x60

### 7.5.7 WRITE_EEPROM

Dieser Befehl funktioniert analog zum Befehl WRITE_FLASH.

PC -> Brenner8
Adresse | Bedeutung | Inhalt
0x00 | Kommando | 0x61
0x01 | Zahl der Bytes
0x02 | Endekennzeichen | 0 – letztes Packet
0x03 | Byte N. 1
0xXX | letztes Byte

Der Brenner8 sendet nach dem Brennen des Blocks nur das Kommando als Quittung.

Brenner8 -> PC
Adresse | Bedeutung | Inhalt
0x00 | Kommando | 0x61

### 7.5.8 WRITE_IDDATA

Dieser Befehl funktioniert analog zum Befehl WRITE_FLASH.

PC -> Brenner8
Adresse | Bedeutung | Inhalt
0x00 | Kommando | 0x62
0x01 | Zahl der Bytes
0x02 | Endekennzeichen | 0
0x03 | Byte N. 1
0xXX | letztes Byte

Der Brenner8 sendet nach dem Brennen des Blocks nur das Kommando als Quittung.

Brenner8 -> PC

- 29 -
Adresse | Bedeutung | Inhalt
0x00 | Kommando | 0x62

### 7.5.9 WRITE_CONFIG

Dieser Befehl funktioniert analog zum Befehl WRITE_FLASH.

PC -> Brenner8
Adresse | Bedeutung | Inhalt
0x00 | Kommando | 0x63
0x01 | Zahl der Bytes
0x02 | Endekennzeichen | 0
0x03 | Byte N. 1
0xXX | letztes Byte

Der Brenner8 sendet nach dem Brennen des Blocks nur das Kommando als Quittung.

Brenner8 -> PC
Adresse | Bedeutung | Inhalt
0x00 | Kommando | 0x63

### 7.5.10 ERASE

Dieser Befehl löst ein Erase des Target aus. Dabei wird der Programmspeicher und EEPROM (und je nach Typ auch Config und ID) gelöscht.

PC -> Brenner8
Adresse | Bedeutung | Inhalt
0x00 | Kommando | 0x70

Der Brenner8 sendet nur das Kommando als Quittung.

Brenner8 -> PC
Adresse | Bedeutung | Inhalt
0x00 | Kommando | 0x70

### 7.5.11 REMOVECP

Dieser Befehl löst ein Bulk-Erase des Target aus. Dabei wird der Programmspeicher und der EEPROM (je nach Typ auch Config und ID) gelöscht, und ein eventuell aktives Codeprotection aufgehoben.

PC -> Brenner8
Adresse | Bedeutung | Inhalt
0x00 | Kommando | 0x71

- 30 -

Der Brenner8 sendet nur das Kommando als Quittung.

Brenner8 -> PC
Adresse | Bedeutung | Inhalt
0x00 | Kommando | 0x71

- 31 -

## 8 EEPROM des Steuer-PIC

Im EEPROM des Steuer-PIC werden eine Reihe Kalibrierwerte gespeichert.

Außerdem steuert die Zelle 0xFE den Bootloader. Ist ihr Wert 0xFF, das startet beim Reset der Bootloader.

von | bis | Zahl der Bytes | Datentyp | Wert | Standardwerer
0x00 | 0x07 | 8 | Real | Referenzspannung (Z-Diode) | 3,3
0x08 | 0x0F | 8 | Real | VppSpannungsteilerverhältnis | 3,14
0x10 | 0x17 | 8 | Real | gain_off | 2,6
0x18 | 0x1F | 8 | Real | pwm0V_off | 16
0x20 | 0x27 | 8 | Real | gain_on | 5,6
0x28 | 0x2F | 8 | Real | pwm0V_on | 35
0x30 | 0x30 | 1 | Byte | Prüfsumme von 0x00 bis 0x2F | -
0xFE | 0xFE | 1 | Byte | Bootloaderkennzeichen | 0

Die Prüfsumme in Zelle 0x30 sind die unteren 8 Bit der Summe aller Werte aus den Zellen 0x00 bis 0x2F plus die Zahl dieser Zellen (also 0x30).

- 32 -

## 9 Database-Struktur

### 9.1 Aufbau der picdef03.dat

Die für den Brenner8 relevanten Daten stehen im File picdef03.dat der PIC-Database. Diese File besteht aus Datenblöcken vom Typ TPicDef. Die Struktur dieses Typs ist nachfolgend aufgelistet.:

TPicDef = record
name | : string[20]; // z.B. 'PIC18F8722A '
cpu | : byte; | // 12, 14, 16, 24 Bit
power | : byte; | // vdd-vpp-Einschaltreihenfolge
config | : integer; | // eintrag in der config-Datei für erste Config
software : byte; | // 1-Flashover, 2-PBrenner, 4-P18, 5-dsProg
blocksize : integer; | // größe der CP-Blöcke im flash
pins | : byte; | //Zahl der Anschluß-Pins
ExtraStr : string[16];
ExtraInt : integer;
Extrabool : boolean;
interfaces : record
io | : byte;
adc | : byte;
adctyp | : byte;
uart | : byte;
spi | : byte;
i2c | : byte;
can | : byte;
usb | : byte;
timer | : byte;
compare : byte;
capture : byte;
pwm | : byte;
ccp | : byte;
eccp | : byte;
ssp | : byte;
ex2 | : byte;
end;
vpp : record | // Programmierspannung in Volt
min | : real;
max | : real;
deflt : real;
end;
vdd : record | // Betriebsspannung in Volt
min | : real;
max | : real;
dfltmin : real;
dfltmax : real;
nominal : real;
end;
pgming : record
memtech : byte; | // ee=1 oder eprom=2
ovrpgm : byte; | // nur für Eprom ansonsten Pin-Zahl
tries | : byte; | // Zyklenzahl für eine Zelle (bei Flash=1)
lvpthresh : real;
panelsize : word; // panel size of zero means single panel

- 33 -

end;

wait : record | // alle Brenn-Zeiten in Mikrosekunden
pgm | : word;
lvpgm | : word;
eedata : word;
cfg : word;
userid : word;
erase : word;
lverase : word;
end;
latches : record | // Schreibpuffergrößen in Byte
pgm | : byte;
eedata | : byte;
userid | : byte;
cfg | : byte;
rowerase : byte; | // Löschbereich in Byte
end;
pgmmem : record | // Flash-Adressen
min : longint;
max : longint;
end;
eedata : record | // EEPROM-Adressen
min : longint;
max : longint;
end;
extpgm : record | // externer Speicherschaltkreis
min : longint;
max : longint;
modeaddr : longint;
end;
cfgmem : record
min : longint;
max : longint;
end;
calmem : record
min : longint;
max : longint;
end;
userid : record
min : longint;
max : longint;
end;
devid : record
min | : longint;
max | : longint;
idmask : word;
id : word;
end;
taktik : record
flash : byte;
eeprom : byte;
id : byte;
config : byte;
erase : byte;
cp : byte;
read_eeprom : byte;
end;
end;

- 34 -

### 9.2 Auswahl des richtigen Datensatzes

Für jeden unterstützten PIC gibt es in der Database genau einen solchen Datensatz. Der für das Target relevante Datensatz kann auf zwei Wegen in der Database gefunden werden.

- Der Name des PICs ist im String name abgelegt. Im name-String werden generell Großbuchstaben verwendet.
- Die Chip-ID des PIC steht in jedem Datensatz im Record devid:

Hier noch einmal die Struktur von devid aus TPicDef.

devid : record
min | : longint;
max | : longint;
idmask : word;
id : word;
end;
- devid.min und devid.max geben den Adressbereich im PIC an, in dem die ID steht.
- devid.idmask gibt an, welche Bits der ID für die Identifikation relevant sind Unwichtige Bits stehen in devid.idmask auf „0“.
- devid.id ist der identifikatioscode.

Beispiel: PIC18F2220
- Devid.min : | 0x3FFFFE
- Devid.max: | 0x3FFFFF
- Devid.idmask | 0xFFE0
- Devid.id | 0x0580)

Man liest den relevanten Speicherbereich aus:
- 0x3FFFFE = 0x83
- 0x3FFFFF = 0x05
Und erhält als ID
- ID = 0x0583
Diese Arbeit wird vom Befehl READ_CHIPID erledigt.

Der ermittelte Wert muss nun mit der devid.mask UND-Verknüpft werden. Das Ergebnis ist identisch mit devid.id. Folglich ist der PIC ein PIC18F220.

- 35 -

### 9.3 Datenauswahl

Nicht alle Werte aus der TPicDef-Struktur sind für die Firmware des Brenner8 relevant, und so müssen die wichtigen Werte in die typedef-Struktur des
Kommandos 0x41 kopiert werden. Im folgenden Codebeispiel werden die Daten aus einer Variablen mit Namen PICdata vom Typ TPicDEF in eine Variable vom Typ PICdata2 vom Typ typedef übertragen. Letztere wird dann mit Kommando 0x41 der Firmware des Brenner8 übermittelt.:

with PICdata2 do begin
kommando := SET_PICTYPE;
cpu | := PICdata.cpu;
power | := PICdata.power;
blocksize := PICdata.blocksize;
pins | := PICdata.pins;
vpp | := round(PICdata.vpp.deflt*10); // 130; | //13,0V
if (PICdata.pgming.panelsize<PICdata.pgmmem.max)
then panelsize := PICdata.pgming.panelsize | //multipanel ?
else panelsize := 0; | //singelpanel!!

with taktik do begin
flash := PICdata.taktik.flash;
eeprom := PICdata.taktik.eeprom;
id := PICdata.taktik.id;
config := PICdata.taktik.config;
erase := PICdata.taktik.erase;
cp := PICdata.taktik.cp;
read_eeprom :=PICdata.taktik.read_eeprom;
end;
with latches do begin | // Schreibpuffergrößen in Byte
pgm | := PICdata.latches.pgm;
eedata | := PICdata.latches.eedata;
userid | := PICdata.latches.userid;
cfg | := PICdata.latches.cfg;
rowerase := PICdata.latches.rowerase
end;
with wait do begin | // alle Brenn-Zeiten in Mikrosekunden
pgm | := PICdata.wait.pgm;
lvpgm | := PICdata.wait.lvpgm;
eedata := PICdata.wait.eedata;
cfg := PICdata.wait.cfg;
userid := PICdata.wait.userid; erase := PICdata.wait.erase; lverase := PICdata.wait.lverase; end;
end;
// PATCH für DB10
if PICdata.name='PIC18F1320' then PICdata2.wait.eedata:=6000;
if PICdata.name='PIC18F1220' then PICdata2.wait.eedata:=6000;

Die letzten beiden Zeilen dienen nur der Korrektur zweier Fehler in der Database 10 und sind zukünftig nicht mehr relevant.

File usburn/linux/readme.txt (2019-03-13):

usburn (fuer USB-Portbrenner Brenner8/9) V0.4 (16.05.2010)
=========================================================

Das ist die vierte Version von usburn fuer Linux.
Sie unterstuetzt den Brenner8 und den Brenner9.

Allgemeines
===========

Dies ist ein Linuxprogramms zur Ansteuerung meines Brenners8/9.

Mit einem Brenner 8 werden 14- und 16-Bit-Kern-PICs sowie einige 24-Bit Signalcontroller unterstuetzt.
Das sind die Serien PIC18Fxxxx, PIC16Fxxx, dsPIC30Fxxxx und viele PIC12Fxxx. Die PIC18FxxKxx werden mit dem Brenner8 und einem speziellen Adapter unterstuetzt.
Das Programm benoetigt dafuer einen Brenner8 mit Firmware 0.15 und die Database 24 oder neuer. All das befindet sich in dieser TAR-Datei

Mit einem Brenner 9 werden 3,3V-PICs der Serien PIC24F, PIC24H, dsPIC33 sowie PIC18FxxJxx unterstuetzt.
Das Programm benoetigt dafuer einen Brenner9 mit Firmware 3.12 und der Database 19 oder neuer. All das befindet sich in dieser TAR-Datei

Das Programm ist noch recht frisch, und wird noch viele Bugs enthalten. Ausserdem stellt es meinen ersten Gehversuch unter Linux und mit C++ dar.
Grosse Teile des Codes entstanden durch Umschreiben des Pascal-Codes meiner Windowssoftware, die ueber Jahre gewachsen ist.

Installation:
=============
Libusb installieren (z.B. mit dem Paketmanager der jeweiligen Linuxdistribution)
Das TAR-File in einen Ordner entpacken.
Eventuell das make-File anpassen.
make ausfuehren.

Nutzung:
========
Da der Zugriff auf den Brenner8&9 nicht über Kernelmodule, sondern direkt über libusb erfolgt,
sind eigentlich root-Rechte erforderlich. Damit alle User Zugriff bekommen, legt man eine
Datei "/etc/udev/rules.d/99-sprutbrenner" an und schreibt in diese Datei:

SUBSYSTEM=="usb", SYSFS{idProduct}=="ff0b", SYSFS{idVendor}=="04d8",
GROUP = "plugdev"

Damit sollte der Brenner ab dem nächsten Einstecken für alle User der plugdev-Gruppe (in der man
ja grundsätzlich sein muss, wenn man usb-Geräte benutzen möchte) verfügbar sein. Getested unter
Gentoo und Debian 4.0 & 5.0. (Danke Marcel)

Aenderungen zur Version 0.3
===========================
- Unterstuetzung der PIC18FxxKxx und PIX18LFxxKxx mit Brenner8+Adapter
- Unterstuetzung fuer PIC16LF7xx, PIC16LF1xxx (alles 3,3V-Typen) mit Brenner8+Adapter

Aenderungen zur Version 0.2
===========================
- automatische Umschaltung auf ICSP-Anschluss bei Nutzung der dsPIC30, dsPIC33, PIC24, PIC18FxxJxx, PIC10F und PIC1xF5xx
- fuer PIC24 gilt nun die Familie "24"
- BG (bandgap) -Einstellung des Herstellers bleiben erhalten
- OSCCAL bleibt erhalten
- OSCCAL kann auch manuell gesetzt werden (Option "-L" )

Aenderungen zur Version 0.1
===========================
- Problem mit der Falschen Erkennung einiger Typen behoben
- Optionen "-I" und "-O" ergänzt

Bekannte Probleme:
==================
- ich rate noch davon ab, PICs zu brennen, die einen OSCCAL-Wert im Flash oder in der Config enthalten. (ungetestet)
- ich rate dringend davon ab, PICs zu brennen, die einen BG (Bandgap)-Wert in der Config enthalten. (geht verloren!!)

- 16F639 wird als 16F636 behandelt (kein wirkliches Problem)
- 16F83 muss als 16F84 gebrannt werden
- 60- & 80-polige PICs muessen ueber die ICSP-Verbindung gebrannt werden.
- dsPIC30F-Typen muessen ueber die ICSP-Verbindung gebrannt werden.
- alle 3,3V-Typen muessen ueber die ICSP-Verbindung gebrannt werden.

Weitere Informationen und ein ausfuehrlichjes Handbuch findet man auf www.sprut.de

www.sprut.de/electronic/soft/usburn/linux/usburn_linux.htm

Ueber positive und negative Erfahrungen berichtet bitte an:
mailto: sprut@sprut.de

sprut 16.05.2010
http://www.sprut.de

//////////////////////////////////////////////////////////////////////////////////////////

Informationen fuer das Compilieren:
==================================

Folgende Biblitheken werden benoetigt:
-------------------------------------

LSB 3.2				(standardmaessig vorhanden)
libnsl.so.1
libusb-0.1.so.4			(libusb)

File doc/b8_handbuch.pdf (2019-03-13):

Brenner8 Handbuch

- 1 -

# Handbuch für den Brenner8

Autor: sprut
Stand: 05.03.2008

- 2 -

## 1 Inhaltsverzeichnis

- 3 -

10.12.5 Was bewirken alle diese Einstellungen im PIC-Setup-Bereich des

- 4 -

- 5 -

## 2 Abbildungsverzeichnis

Abbildung 31 grafische Speicheranzeige - Programm und EEPROM-Daten zu groß

- 6 -

Abbildung 46 Layout der Brenner8P-Platine, 75mm x 100mm (nicht

Abbildung 48 Bestückungsplan des Brenner8mini-P (Silviu)......Error! Bookmark not defined.
Abbildung 49 Layout des Brenner8mini-P, 83mm x 43mm (nicht maßstabsgetreu)72

- 7 -

## 3 Tabellenverzeichnis

- 8 -

## 4 NUTZUNGSBEDINGUNGEN:

DIE SOFTWARE DARF OHNE ENTRICHTUNG EINER LIZENZGEBÜHR BENUTZT WERDEN. DAS GILT FÜR DIE PRIVATE UND GEWERBLICHE NUTZUNG.

DIE PUBLIKATION DER SOFTWARE ERFOLGT "AS IS". FÜR DIE EINHALTUNG ZUGESICHERTER EIGENSCHAFTEN ODER FÜR SCHÄDEN, DIE DURCH DEN EINSATZ ENTSTANDEN SEIN KÖNNTEN, ÜBERNIMMT DER AUTOR KEINERLEI HAFTUNG. SIE NUTZEN DIE SOFTWARE AUF EIGENE GEFAHR!

## 5 Einleitung

Der Brenner8 dient zum komfortablen Programmieren von PIC-Microchip-Prozessoren mit Flash-Programmspeicher.

Es liest Intel-Hex-Dateien wie sie z.B. vom Programm MPLAB erzeugt werden, und brennt diese in den Flash-Speicher des PICs. Im Hex-File enthaltene EEPROM-Daten und Konfigurationseinstellungen werden ebenfalls in den PIC gebrannt.

Zum Betrieb des Brenner8 benötigt man:
- den Brenner8 selbst
- die Firmware für den Steuer-PIC im Brenner8
- einen PC mit USB-Anschluss und USB-Kabel
- das Windows-Programm: US-Burn

Der Brenner8 und die dazugehörige Siftware werden ständig weiterenwickelt. Dieses Handbuch basiert auf:
- Brenner8 Rev.5
- Firmware Fw 0.11
- USBurn V1.8
- Database16

### 5.1 Unterstützte PIC-Typen

Der Brenner8 wurde entworfen, um alle PIC-Microcontroller mit Flash-Programmspeicher und 5V Betriebsspannung programmieren zu können. Das sind:
- alle PIC18Fxxx und PIC18Fxxxx (keine PIC18FxxJxx)
- alle PIC16Fxx und PIC16Fxxx
- alle PIC12Fxxx
- alle PIC10Fxxx
- alle dsPIC30Fxxxx

Im Folgenden sind alle Typen aufgelistet:

- 9 -

supported members of PIC/dsPIC -series
-- PIC-database V.15 (11/01/2008)
Name | Pins Prog EEPRM TMR ECCP PWM UART SSP CAN USB ADC IO-
[kB] | [B] | /CCP mot /SPI I2C | Pins
10F200 | 6 | - | - 1 -/- | - -/- -/- | - | - | - | 4
10F202 | 6 | - | - 1 -/- | - -/- -/- | - | - | - | 4
10F204 | 6 | - | - 1 -/- | - -/- -/- | - | - | - | 4
10F206 | 6 | - | - 1 -/- | - -/- -/- | - | - | - | 4
10F220 | 6 | - | - 1 -/- | - -/- -/- | - | - | 2 | 4
10F222 | 6 | - | - 1 -/- | - -/- -/- | - | - | 2 | 4
12F508 | 8 | - | - 1 -/- | - -/- -/- | - | - | - | 6
12F509 | 8 | 1 | - 1 -/- | - -/- -/- | - | - | - | 6
12F510 | 8 | 1 | - 1 -/- | - -/- -/- | - | - | 3 | 6
12F519 | 8 | 1 | 64 1 -/- | - -/- -/- | - | - | - | 6
12F609 | 8 | 1 | - 2 -/- | - -/- -/- | - | - | - | 6
12F615 | 8 | 1 | - 3 1/- | - -/- -/- | - | - | 4 | 6
12F629 | 8 | 1 | 128 2 -/- | - -/- -/- | - | - | - | 6
12F635 | 8 | 1 | 128 2 -/- | - -/- -/- | - | - | - | 6
12F675 | 8 | 1 | 128 2 -/- | - -/- -/- | - | - | 4 | 6
12F683 | 8 | 3 | 256 3 -/1 | - -/- -/- | - | - | 4 | 6
16F54 | 18 | - | - 1 -/- | - -/- -/- | - | - | - | 13
16F57 | 28 | 2 | - 1 -/- | - -/- -/- | - | - | - | 21
16F59 | 40 | 2 | - 1 -/- | - -/- -/- | - | - | - | 33
16F72 | 28 | 3 | - 3 -/1 | - -/- -/1 | - | - | 5 | 22
16F73 | 28 | 6 | - 3 -/2 | - 1/- -/1 | - | - | 5 | 22
16F74 | 40 | 6 | - 3 -/2 | - 1/- -/1 | - | - | 5 | 33
16F76 | 28 | 11 | - 3 -/2 | - 1/- -/1 | - | - | 5 | 22
16F77 | 40 | 11 | - 3 -/2 | - 1/- -/1 | - | - | 5 | 33
16F84 | 18 | 1 | 64 1 -/- | - -/- -/- | - | - | - | 13
16F87 | 18 | 6 | 256 3 -/1 | - 1/- -/1 | - | - | - | 16
16F88 | 18 | 6 | 256 3 -/1 | - 1/- -/1 | - | - | 7 | 16
16F505 | 14 | 1 | - 1 -/- | - -/- -/- | - | - | - | 12
16F506 | 14 | 1 | - 1 -/- | - -/- -/- | - | - | 3 | 12
16F526 | 14 | 1 | 64 1 -/- | - -/- -/- | - | - | 3 | 12
16F610 | 14 | 1 | - 2 -/- | - -/- -/- | - | - | - | 12
16F616 | 14 | 3 | - 3 1/- | - -/- -/- | - | - | 8 | 12
16F627 | 18 | 1 | 128 3 -/1 | - 1/- -/- | - | - | - | 16
16F628 | 18 | 3 | 128 3 -/1 | - 1/- -/- | - | - | - | 16
16F630 | 14 | 1 | 128 2 -/- | - -/- -/- | - | - | - | 12
16F631 | 20 | 1 | 128 2 -/- | - -/- -/- | - | - | - | 18
16F636 | 14 | 3 | 256 2 -/- | - -/- -/- | - | - | - | 12
16F676 | 14 | 1 | 128 2 -/- | - -/- -/- | - | - | 8 | 12
16F677 | 20 | 3 | 256 2 -/- | - -/- -/- | - | - 12 | 18
16F684 | 14 | 3 | 256 3 1/- | - -/- -/- | - | - | 8 | 12
16F685 | 20 | 6 | 256 3 1/- | - -/- -/- | - | - 12 | 18
16F687 | 20 | 3 | 256 2 -/- | - 1/- -/- | - | - 12 | 18
16F688 | 14 | 6 | 256 2 -/- | - 1/- -/- | - | - | 8 | 12
16F689 | 20 | 6 | 256 2 -/- | - 1/- -/- | - | - 12 | 18
16F690 | 20 | 6 | 256 3 1/- | - 1/- -/- | - | - 12 | 18
16F716 | 18 | 3 | - 3 1/- | - -/- -/- | - | - | 4 | 13
16F737 | 28 | 6 | - 3 -/3 | - 1/- -/1 | - | - 11 | 25
16F747 | 40 | 6 | - 3 -/3 | - 1/- -/1 | - | - 11 | 36
16F767 | 28 | 11 | - 3 -/3 | - 1/- -/1 | - | - 11 | 25

- 10 -
16F777 | 40 | 11 | - 3 -/3 | - 1/- -/1 | - | - 11 | 36
16F785 | 20 | 3 | 256 3 -/1 | - -/- -/- | - | - 12 | 18
16F818 | 18 | 1 | 128 3 -/1 | - -/- -/1 | - | - | 5 | 16
16F819 | 18 | 3 | 256 3 -/1 | - -/- -/1 | - | - | 5 | 16
16F870 | 28 | 3 | 64 3 -/1 | - 1/- -/- | - | - | 5 | 22
16F871 | 40 | 3 | 64 3 -/1 | - 1/- -/- | - | - | 8 | 33
16F872 | 28 | 3 | 64 3 -/1 | - -/- -/1 | - | - | 5 | 22
16F873 | 28 | 6 | 128 3 -/2 | - 1/- -/1 | - | - | 5 | 22
16F874 | 40 | 6 | 128 3 -/2 | - 1/- -/1 | - | - | 8 | 33
16F876 | 28 | 11 | 256 3 -/2 | - 1/- -/1 | - | - | 5 | 22
16F877 | 40 | 11 | 256 3 -/2 | - 1/- -/1 | - | - | 8 | 33
16F882 | 28 | 3 | 128 3 1/1 | - 1/- -/1 | - | - 11 | 25
16F883 | 28 | 6 | 256 3 1/1 | - 1/- -/1 | - | - 11 | 25
16F884 | 40 | 6 | 256 3 1/1 | - 1/- -/1 | - | - 14 | 36
16F886 | 28 | 11 | 256 3 1/1 | - 1/- -/1 | - | - 11 | 25
16F887 | 40 | 11 | 256 3 1/1 | - 1/- -/1 | - | - 14 | 36
16F913 | 28 | 6 | 256 3 -/1 | - 1/- -/1 | - | - | 5 | 25
16F914 | 40 | 6 | 256 3 -/2 | - 1/- -/1 | - | - | 8 | 36
16F916 | 28 | 11 | 256 3 -/1 | - 1/- -/1 | - | - | 5 | 25
16F917 | 40 | 11 | 256 3 -/2 | - 1/- -/1 | - | - | 8 | 36
16F946 | 64 | 11 | 256 3 -/2 | - 1/- -/1 | - | - | 8 | 54
16F84A | 18 | 1 | 64 1 -/- | - -/- -/- | - | - | - | 13
16F627A | 18 | 1 | 128 3 -/1 | - 1/- -/- | - | - | - | 16
16F628A | 18 | 3 | 128 3 -/1 | - 1/- -/- | - | - | - | 16
16F648A | 18 | 6 | 256 3 -/1 | - 1/- -/- | - | - | - | 16
16F873A | 28 | 6 | 128 3 -/2 | - 1/- -/1 | - | - | 5 | 22
16F874A | 40 | 6 | 128 3 -/2 | - 1/- -/1 | - | - | 8 | 33
16F876A | 28 | 11 | 256 3 -/2 | - 1/- -/1 | - | - | 5 | 22
16F877A | 40 | 11 | 256 3 -/2 | - 1/- -/1 | - | - | 8 | 33
18F242 | 28 | 16 | 256 4 -/2 | - 1/- 1/- | - | - | 5 | 23
18F248 | 28 | 16 | 256 4 -/1 | - 1/- 1/- | 1 | - | 5 | 23
18F252 | 28 | 32 | 256 4 -/2 | - 1/- 1/- | - | - | 5 | 23
18F258 | 28 | 32 | 256 4 -/1 | - 1/- 1/- | 1 | - | 5 | 23
18F442 | 40 | 16 | 256 4 -/2 | - 1/- 1/- | - | - | 8 | 34
18F448 | 40 | 16 | 256 4 1/1 | - 1/- 1/- | 1 | - | 8 | 34
18F452 | 40 | 32 | 256 4 -/2 | - 1/- 1/- | - | - | 8 | 34
18F458 | 40 | 32 | 256 4 1/1 | - 1/- 1/- | 1 | - | 8 | 34
18F1220 | 18 | 4 | 256 4 1/- | - 1/- -/- | - | - | 7 | 16
18F1230 | 18 | 4 | 128 2 -/- | 1 1/- -/- | - | - | 4 | 16
18F1320 | 18 | 8 | 256 4 1/- | - 1/- -/- | - | - | 7 | 16
18F1330 | 18 | 8 | 128 2 -/- | 1 1/- -/- | - | - | 4 | 16
18F2220 | 28 | 4 | 256 4 -/2 | - 1/- 1/- | - | - 10 | 24
18F2221 | 28 | 4 | 256 4 -/1 | - 1/- -/- | - | - 10 | 24
18F2320 | 28 | 8 | 256 4 -/2 | - 1/- 1/- | - | - 10 | 24
18F2321 | 28 | 8 | 256 4 -/1 | - 1/- -/- | - | - 10 | 24
18F2331 | 28 | 8 | 256 4 -/2 | 1 1/- 1/- | - | - | 5 | 24
18F2410 | 28 | 16 | - 4 -/1 | - 1/- 1/- | - | - 10 | 25
18F2420 | 28 | 16 | 256 4 -/1 | - 1/- 1/- | - | - 10 | 25
18F2423 | 28 | 16 | 256 4 -/1 | - 1/- 1/- | - | - 10 | 25
18F2431 | 28 | 16 | 256 4 -/2 | 1 1/- 1/- | - | - | 5 | 24
18F2450 | 28 | 16 | - 3 -/1 | - 1/- -/- | - | - 10 | 22
18F2455 | 28 | 24 | 256 4 -/2 | - 1/- 1/- | - | 1 10 | 23
18F2458 | 28 | 24 | 256 4 -/2 | - 1/- 1/- | - | 1 10 | 24
18F2480 | 28 | 16 | 256 4 -/1 | - 1/- 1/- | 1 | - | 8 | 24
18F2510 | 28 | 32 | - 4 -/1 | - 1/- 1/- | - | - 10 | 25
18F2515 | 28 | 48 | - 4 -/2 | - 1/- 1/- | - | - 10 | 25

- 11 -
18F2520 | 28 | 32 | 256 4 -/1 | - 1/- 1/- | - | - 10 | 25
18F2523 | 28 | 32 | 256 4 -/1 | - 1/- 1/- | - | - 10 | 25
18F2525 | 28 | 48 1024 4 -/2 | - 1/- 1/- | - | - 10 | 25
18F2550 | 28 | 32 | 256 4 -/1 | - 1/- 1/- | - | 1 10 | 23
18F2553 | 28 | 32 | 256 4 -/1 | - 1/- 1/- | - | 1 10 | 23
18F2580 | 28 | 32 | 256 4 -/1 | - 1/- 1/- | 1 | - | 8 | 24
18F2585 | 28 | 48 1024 4 -/1 | - 1/- 1/- | 1 | - | 8 | 25
18F2610 | 28 | 64 | - 4 -/2 | - 1/- 1/- | - | - 10 | 25
18F2620 | 28 | 64 1024 4 -/2 | - 1/- 1/- | - | - 10 | 25
18F2680 | 28 | 64 1024 4 -/1 | - 1/- 1/- | 1 | - | 8 | 25
18F2682 | 28 | 80 1024 4 -/1 | - 1/- 1/- | 1 | - | 8 | 25
18F2685 | 28 | 96 1024 4 -/1 | - 1/- 1/- | 1 | - | 8 | 25
18F4220 | 40 | 4 | 256 4 1/1 | - 1/- 1/- | - | - 13 | 36
18F4221 | 40 | 4 | 256 4 -/1 | - 1/- 1/- | - | - 13 | 36
18F4320 | 40 | 8 | 256 4 1/1 | - 1/- 1/- | - | - 13 | 36
18F4321 | 40 | 8 | 256 4 1/1 | - 1/- 1/- | - | - 13 | 36
18F4331 | 40 | 8 | 256 4 -/2 | 1 1/- 1/- | - | - | 9 | 36
18F4410 | 40 | 16 | - 4 1/1 | - 1/- 1/- | - | - 13 | 36
18F4420 | 40 | 16 | 256 4 1/1 | - 1/- 1/- | - | - 13 | 36
18F4423 | 40 | 16 | 256 4 1/1 | - 1/- 1/- | - | - 13 | 36
18F4431 | 40 | 16 | 256 4 -/2 | 1 1/- 1/- | - | - | 9 | 36
18F4450 | 40 | 16 | - 3 -/1 | - 1/- -/- | - | - 13 | 34
18F4455 | 40 | 24 | 256 4 -/1 | - 1/- 1/- | - | 1 13 | 34
18F4458 | 40 | 24 | 256 4 -/1 | - 1/- 1/- | - | 1 13 | 34
18F4480 | 40 | 16 | 256 4 1/1 | - 1/- 1/- | 1 | - 11 | 36
18F4510 | 40 | 32 | - 4 1/1 | - 1/- 1/- | - | - 13 | 36
18F4515 | 40 | 48 | - 4 1/1 | - 1/- 1/- | - | - 13 | 36
18F4520 | 40 | 32 | 256 4 1/1 | - 1/- 1/- | - | - 13 | 36
18F4523 | 40 | 32 | 256 4 1/1 | - 1/- 1/- | - | - 13 | 36
18F4525 | 40 | 48 1024 4 1/1 | - 1/- 1/- | - | - 13 | 35
18F4550 | 40 | 32 | 256 4 1/1 | - 1/- 1/- | - | 1 13 | 34
18F4553 | 40 | 32 | 256 4 1/1 | - 1/- 1/- | - | 1 13 | 34
18F4580 | 40 | 32 | 256 4 1/1 | - 1/- 1/- | 1 | - 11 | 36
18F4585 | 40 | 48 1024 4 1/1 | - 1/- 1/- | 1 | - 11 | 36
18F4610 | 40 | 64 | - 4 -/1 | - 1/- 1/- | - | - 13 | 36
18F4620 | 40 | 64 1024 4 1/1 | - 1/- 1/- | - | - 13 | 36
18F4680 | 40 | 64 1024 4 1/1 | - 1/- 1/- | 1 | - 11 | 36
18F4682 | 40 | 80 1024 4 1/1 | - 1/- 1/- | 1 | - 11 | 36
18F4685 | 40 | 96 1024 4 1/1 | - 1/- 1/- | 1 | - 11 | 36
18F6310 | 64 | 8 | - 4 -/3 | - 2/- 1/- | - | - 12 | 54
18F6390 | 64 | 8 | - 4 -/2 | - 2/- 1/- | - | - 12 | 54
18F6393 | 64 | 8 | - 4 -/2 | - 2/- 1/- | - | - 12 | 50
18F6410 | 64 | 16 | - 4 -/3 | - 2/- 1/- | - | - 12 | 54
18F6490 | 64 | 16 | - 4 -/2 | - 2/- 1/- | - | - 12 | 54
18F6493 | 64 | 16 | - 4 -/2 | - 2/- 1/- | - | - 12 | 50
18F6520 | 64 | 32 1024 5 -/5 | - 2/- 1/- | - | - 12 | 52
18F6525 | 64 | 48 1024 5 3/2 | - 2/- 1/- | - | - 12 | 53
18F6527 | 64 | 48 1024 5 3/2 | - 2/- 2/- | - | - 12 | 54
18F6585 | 64 | 48 1024 4 1/1 | - 1/- 1/- | 1 | - 12 | 53
18F6620 | 64 | 64 1024 5 -/5 | - 2/- 1/- | - | - 12 | 52
18F6621 | 64 | 64 1024 5 3/2 | - 2/- 1/- | - | - 12 | 53
18F6622 | 64 | 64 1024 5 3/2 | - 2/- 2/- | - | - 12 | 54
18F6627 | 64 | 96 1024 5 3/2 | - 2/- 2/- | - | - 12 | 54
18F6680 | 64 | 64 1024 4 1/1 | - 1/- 1/- | 1 | - 12 | 53
18F6720 | 64 128 1024 5 -/5 | - 2/- 1/- | - | - 12 | 52
18F6722 | 64 128 1024 5 3/2 | - 2/- 2/- | - | - 12 | 54
18F8310 | 80 | 8 | - 4 -/3 | - 2/- 1/- | - | - 12 | 70

- 12 -
18F8390 | 80 | 8 | - 4 -/2 | - 2/- 1/- | - | - 12 | 70
18F8393 | 80 | 8 | - 4 -/2 | - 2/- 1/- | - | - 12 | 66
18F8410 | 80 | 16 | - 4 -/3 | - 2/- 1/- | - | - 12 | 70
18F8490 | 80 | 16 | - 4 -/2 | - 2/- 1/- | - | - 12 | 70
18F8493 | 80 | 16 | - 4 -/2 | - 2/- 1/- | - | - 12 | 66
18F8520 | 80 | 32 1024 5 -/5 | - 2/- 1/- | - | - 16 | 68
18F8525 | 80 | 48 1024 5 3/2 | - 2/- 1/- | - | - 16 | 69
18F8527 | 80 | 48 1024 5 3/2 | - 2/- 2/- | - | - 16 | 70
18F8585 | 80 | 48 1024 4 1/1 | - 1/- 1/- | 1 | - 16 | 69
18F8620 | 80 | 64 1024 5 -/5 | - 2/- 1/- | - | - 16 | 68
18F8621 | 80 | 64 1024 5 3/2 | - 2/- 1/- | - | - 16 | 69
18F8622 | 80 | 64 1024 5 3/2 | - 2/- 2/- | - | - 16 | 70
18F8627 | 80 | 96 1024 5 3/2 | - 2/- 2/- | - | - 16 | 70
18F8680 | 80 | 64 1024 4 1/1 | - 1/- 1/- | 1 | - 16 | 69
18F8720 | 80 128 1024 5 -/5 | - 2/- 1/- | - | - 16 | 68
18F8722 | 80 128 1024 5 3/2 | - 2/- 2/- | - | - 16 | 70
30F2010 | 28 | 12 1024 3 -/2 | 1 1/1 -/1 | - | - | 6 | 20
30F2011 | 14 | 12 | - 3 -/2 | - 1/1 -/1 | - | - | 8 | 12
30F2012 | 28 | 12 | - 3 -/2 | - 1/1 -/1 | - | - 10 | 20
30F3010 | 28 | 24 1024 5 -/2 | 1 1/1 -/1 | - | - | 6 | 20
30F3011 | 40 | 24 1024 5 -/4 | 1 2/1 -/1 | - | - | 9 | 30
30F3012 | 14 | 24 1024 3 -/2 | - 1/1 -/1 | - | - | 8 | 12
30F3013 | 28 | 24 1024 3 -/2 | - 2/1 -/1 | - | - 10 | 20
30F3014 | 40 | 24 1024 3 -/2 | - 2/1 -/1 | - | - 13 | 30
30F4011 | 40 | 48 1024 5 -/4 | 1 2/1 -/1 | 1 | - | 9 | 30
30F4012 | 28 | 48 1024 5 -/2 | 1 1/1 -/1 | 1 | - | 6 | 20
30F4013 | 40 | 48 1024 5 -/4 | - 2/1 -/1 | 1 | - 13 | 30
30F5011 | 64 | 66 1024 5 -/8 | - 2/2 -/1 | 2 | - 16 | 52
30F5013 | 80 | 66 1024 5 -/8 | - 2/2 -/1 | 2 | - 16 | 68
30F5015 | 64 | 66 1024 5 -/4 | 1 1/2 -/1 | 1 | - 16 | 52
30F5016 | 80 | 66 1024 5 -/4 | 1 1/2 -/1 | 1 | - 16 | 68
30F6010 | 80 144 4096 5 -/8 | 1 2/2 -/1 | 2 | - 16 | 68
30F6011 | 64 132 2048 5 -/8 | - 2/2 -/1 | 2 | - 16 | 52
30F6012 | 64 144 4096 5 -/8 | - 2/2 -/1 | 2 | - 16 | 52
30F6013 | 80 132 2048 5 -/8 | - 2/2 -/1 | 2 | - 16 | 68
30F6014 | 80 144 4096 5 -/8 | - 2/2 -/1 | 2 | - 16 | 68
30F6015 | 64 144 4096 5 -/8 | 1 2/2 -/1 | 1 | - 16 | 52
30F6010A | 80 144 4096 5 -/8 | 1 2/2 -/1 | 2 | - 16 | 66
30F6011A | 64 132 2048 5 -/8 | - 2/2 -/1 | 2 | - 16 | 52
30F6012A | 64 144 4096 5 -/8 | - 2/2 -/1 | 2 | - 16 | 52
30F6013A | 80 132 2048 5 -/8 | - 2/2 -/1 | 2 | - 16 | 68
30F6014A | 80 144 4096 5 -/8 | - 2/2 -/1 | 2 | - 16 | 68
30F2011es | 14 | 12 | - 3 -/2 | - 1/1 -/1 | - | - | 8 | 12
30F2012es | 28 | 12 | - 3 -/2 | - 1/1 -/1 | - | - 10 | 20
30F6010es | - 144 4096 - -/- | - -/- -/- | - | - | - | -
207 PIC-Types

Durch Aktualisierung der Firmware und der Windows-Software kann die vom Brenner8 unterstützte Typenpalette immer aktuell gehalten werden.

Durch einen Adapter und kleinere Hardwaremodifikationen kann der Brenner8 zum Brenner9 umgebaut werden, der 3,3V-PICs folgender Serien brennen kann:
- PIC18FxxJxx
- PIC24xxxx
- dsPIC33Fxxxx

- 13 -

Alle 14&16-Bit-Kern-PICs (PIC16Fxxxx/PIC18Fxxxx) mit DIL-Gehäuse (8 / 14 / 18 / 28 / 40 Pin-DIL-Gehäuse) können im 40-poligen Testsockel des Brenner8 programmiert werden. Alle anderen Typen sind mit einem geeigneten Adapter am ICSP-Steckverbinder anzuschließen.

Alle dsPIC30Fxxxx, PIC1xF5x, PIC1xF5xx und PIC10Fxxx müssen auch am ICSP-Steckverbinder adaptiert werden. Sie passen elektrisch nicht in den Testsockel des Brenner8.
Die dsPIC30F-Typen können nur vom Brenner8P/Brenner8miniP programmiert werden.

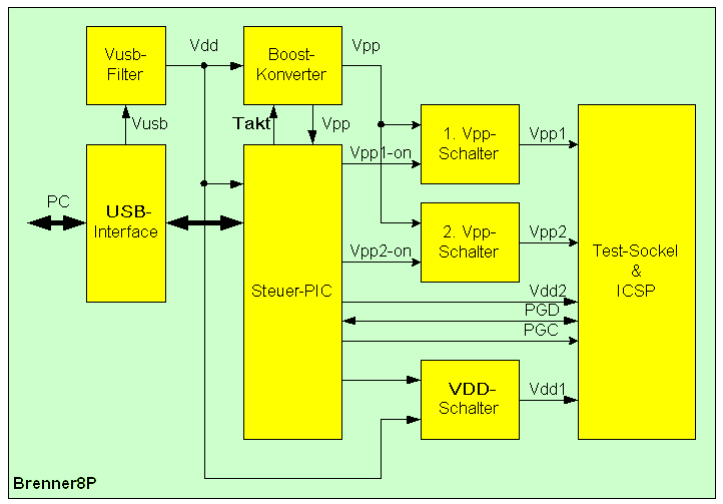
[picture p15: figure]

- 14 -

## 6 Aufbau der Hardware

### 6.1 Die Hardware des Brenner8

Dieser Abschnitt ist nur für interessierte Nutzer des Brenner8. alle anderen Leser können zum nächste Punkt dieses dokuments übergehen.

Es folgt eine kurze Beschreibung der Brenner8-Hardware:

Der Brenner8 besteht aus folgenden Baugruppen:
- USB-Interface
- Takterzeugung
- Referenzspannungsquelle
- Programmierspannungserzeugung
- 2 Programmierspannungsschaltern
- Testsockel

Abbildung 1 Blockschaltbild des Brenner8

### 6.1.1 USB-Interface

Das USB-Interface dient der Kommunikation mit dem PC wie auch der Stromversorgung des Brenners. Die USB-Buchse dient dem Anschluß an den PC. Der Kondensator am Vusb-Pin des Steuer-PIC ist Bestandteil der 3,3V-Erzeugung im PIC18F2550. Diese 3,3V werden als Signalpegel auf den USB-Leitungen verwendet.

- 15 -

Mit einer Spule und zwei Kondensatoren wird die VBUS-Spannung des USB-Interfaces gefiltert, und steht dann als Betriebsspannung des Brenners zur Verfügung (4.5 .. 5 V)

### 6.1.2 Takterzeugung

Mit einem Rsonator bzw. Einem quarz und 2 Kondensatoren wird ein 20 MHz-Takt erzeugt, aus dem im PIC18F2550 sowohl der Arbeitstakt des PIC-Kerns wie auch der USB-Takt abgeleitet werden.

### 6.1.3 Referenzspannung

Eine 3,3V-Z-Diode mit einem Vorwiderstand erzeugen eine stabile Spannung (ca. 3,3V) die vom Betriebsspannungspegel (und damit vom VBUS-Pegel) unabhängig ist. Sie dient als Referenz für die Messung (und damit für die korrekte Einstellung) der Programmierspannung.

### 6.1.4 Programmierspannungserzeugung

Die PICs benötigen zur Programmierung eine Programmierspannung von 10 .. 13V (je nach Typ). Sie wird aus der Betriebsspannung durch einen Boost-Konverter erzeugt. Der PIC18F2550 gibt am Pin 13 ein 100kHz-Rechtecksignal aus, dessen Pulsweitenverhältnis einstellbar ist.
Die an mit dem Boost-Converter erzeugte Spannung beträgt theoretisch

Vpp = 4,7V * Periode / off-zeit

wobei "Periode" die Dauer eine Rechteckschwingung ist, wärend "off-zeit" der low-Teil dieser Periode ist. Durch Änderung von "off-zeit" kann die Vpp-Spannung eingestellt werden.
In der Praxis gibt einige Seiteneffekte, die durch eine Kalibrierung kompensiert werden müssen.

Zwei widerstände bilden einen Spannungsteiler über den der PIC18F2550 die erzeugte Vpp-Spannung messen kann (Pin 3).

6.1.5 2 Programmierspannungsschalter
Es gibt 2 Schalter, die Vpp zum Testsockel zuschalten können. (Der Brenner8mini(P) hat nur einen Vp-Schalter.) Da verschiedene PICs die Programmierspannung an verschiedenen Pins erwarten, muß je nach PIC-Typ der eine oder der andere Schalter aktiviert werden.
Jeder Schalter besteht aus einem npn- und einem pnp-Transistor.

### 6.1.6 Testsockel

Am Testsockel bzw. am ICSP-Verbinder müssen die 5 Signale Vpp, Vdd, Vss, Data, Clk angelegt werden. Mit Ausnahme von Vpp werden alle Signale direkt von Port-Pins des 18F2550 erzeugt. Je nach Gehäuse des Target-PICs werden die Signale an andere Pins gelegt.
Eine Diode ist nötig, da Pin 1 des Testsockels manchmal Vpp und manchmal Vss ist (je nach PIC). RB7 erzeugt bei Bedarf Vss-Pegel.

- 16 -

### 6.1.7 Rest

Ein pull-up-Widerstand und ein Jumper erzeugen am Pin 1 des 18F2550 high- oder low-Pegel. Erkennt der 18F2550 beim Einschalten dort low-Pegel, dann startet er den Bootloader, ansonsen startet er die Brenner8-Firmware.

- 17 -

### 6.2 Varianten

Es existieren mehrere Varianten des Brenner8, die aber alle mit der gleichen Software/Firmware betrieben werden.
Je nach Brennertyp eignet sich der Brenner für verschiedene Aufgaben:

Tabelle 1 Brenner8-Versionen
Typ \ brennt | PIC im Testsockel | PICs via ICSP-Adapter | PICs via ICSP in der Schaltung | dsPIC30F
Brenner8 | X | X | - | -
Brenner8-P | X | X | X | X
Brenner8mini | - | X | - | -
Brenner8mini-P | - | X | X | X

Der Brenner8P und der Brenner8miniP (Silviu-Layout) lassen sich mit einem zusätzlichen Adapter zum Brennen von 3,3V-PICs verwenden (Brenner9).

Wenn nicht ausdrücklich erwähnt, dann beziehe ich mich im Text immer auf den Brenner8.

### 6.2.1 Brenner8

Der klassische Brenner8 hat einen 40-poligen Testfassung und einen 5-poligen ICSP-Verbinder. Er ist in erster Linie dafür gedacht PICs im Testsockel zu Brennen Am ICSP-Anschluss können über Adapter auch PICs angeschlossen und gebrannt werden.

Der klassische Brenner8 ist nicht dafür ausgelegt, PICs in einer fertig aufgebauten Schaltung via ICSP-Kabel zu brennen. Sein Vdd-Ausgang (im ICSP-Anschluss) ist nicht in der Lage, neben dem zu brennenden PIC noch weitere Baugruppen mit Spannung zu versorgen. Lediglich Kondensatoren von bis zu 100µF dürfen am zu brennenden PIC angeschlossen sein.

### 6.2.2 Brenner8-P

Der Brenner8-P weist alle positiven Eigenschaften des Brenner8 auf. Er hat aber einen Treibertransistor für die Vdd-Leitung im ICSP-Verbinder. Deshalb kann er auch PICs in der fertig aufgebauten Schaltung problemlos brennen, sofern die Schaltung für ICSP ausgelegt wurde.

### 6.2.3 Brenner8mini

Der Brenner8mini ist ein auf die ICSP-Funktion reduzierter Brenner8. Er hat keinen Testsockel. Nur am ICSP-Anschluss können über Adapter PICs angeschlossen und gebrannt werden.

Wie der klassische Brenner8 ist auch der Brenner8mini nicht dafür ausgelegt, PICs in einer fertig aufgebauten Schaltung via ICSP-Kabel zu brennen. Sein Vdd-Ausgang (im ICSP-Anschluss) ist nicht in der Lage, neben dem zu brennenden PIC noch

- 18 -

weitere Baugruppen mit Spannung zu versorgen. Lediglich Kondensatoren von bis zu 100µF dürfen am zu brennenden PIC angeschlossen sein.

### 6.2.4 Brenner8mini-P

Der Brenner8mini-P ist ein Brenner8mini mit Vdd-Treibertransistor. Deshalb kann er auch PICs in der fertig aufgebauten Schaltung problemlos brennen, sofern die Schaltung für ICSP ausgelegt wurde.

### 6.3 Revisionen

Der Brenner8 wird kontinuierlich weiterentwickelt, um seine Eigenschaften zu verbessern. Bei jeder Hardwareänderung, vergebe ich eine neue Revisionsnummer. Neue Revisionen benötigen zur Nutzung der verbesserten Fähigkeiten manchmal auch eine neuere Firmware. Aber umgekehrt funktioniert auch eine neue Firmware stets in einer alten Hardware-Revision.

### 6.3.1 Revision 0

Das war die Urversion des Brenner8. Er hatte noch einige ernsthafte Probleme. So war der Betrieb von 8/14-Pin-PICs im Testsockel nicht möglich, die Vpp-Spannung war manchmal zu niedrig, die Z-Diodenspannung hatte große Toleranzen und die Vpp-Spannungsmessung hatte einen zu eingeschränkten Messbereich. Eine Rev. 0 lässt sich einfach auf eine Rev. 1 umbauen, und das sollte man auch tun.

### 6.3.2 Revision 1

In der Rev. 1 wurden die wesentlichen Mängel der Rev. 0 beseitigt.
- Durch den Tausch von D2 gegen eine Shottky-Diode wurde der Betrieb von 8/14-Pin-PICs im Testsockel möglich.
- Durch Änderung von R16 wird die Z-Spannung verbessert.
- Durch Änderung von R5 wird der Vpp-Messbereich erweitert
- Durch den Tausch von D1 gegen eine Shottky-Diode wird die Vpp-Erzeugung leistungsfähiger.
Der Brenner8-P, Brenner8mini und Brenner8mini-P wurden zu dieser Zeit aus der Taufe gehoben. Sie trugen also gleich die Revisionsnummer 1.
Die Revision 1benötigte mindestens die Firmware 0.5. Die beiden P-Versionen benötigen wenigstens die Firmware V. 0.5a.

### 6.3.3 Revision 2

Mit der Einführung des Bootloaders kam auch die Revision 2.
Die einzige Hardwareänderung ist ein Jumper, mit dem sich der Bootloader aktivieren lässt. Da diese Aktivierung normalerweise auch via Software erfolgen kann, und im Notfall ein Stück Draht den Jumper ersetzen kann, ist ein Umbau von Rev. 1 auf Rev. 2 nicht nötig. Beim Brenner8mini und Brenner8mini-P verzichtete ich gleich auf die Revision 2.
Zur Revision 2 gehört eine Firmware ab V. 0.6 und der Bootloader 1, die aber auch für die Rev. 1 zu empfehlen sind.

- 19 -

### 6.3.4 Revision 3

Diese Revision soll vor allem dem Brenner8P eine vollwertige ICSP-Unterstützung bescheren. Dafür waren eine zusätzlicher Reset-Transistor (Q8) und eine MCLR pullup-Diode (D4) nötig. Der normale Brenner8 erhält nur die Diode D4.
Mit dem Reset-Transistor können PICs auch in Schaltungen gebrannt werden, in denen ein niederohmiger (wenige Kiloohm) pull-up-Widerstand am MCLR-Pin sitzt. Die Diode D4 ermöglicht es einen PIC in einer Testplatine oder in einer fertigen Schaltung „laufen“ zu lassen. Das erleichtert deutlich die Softwareentwicklung, da der Brenner zum Test der Software nicht mehr von der Testplatine getrennt werden muss.
Für das Brennen von PICs im Testsockel oder einem einfachen ICSP-Adapter bringt die Revision 3 keine Veränderungen.
Die Revision 3 benötigt die Firmware V 0.8.

### 6.3.5 Revision 4

Es gab einige Probleme beim Löschen von einigen wenigen PIC-Typen mit großem Flash-Speicher wie z.B. PIC18F4682. Als Ursache stellte sich heraus, dass diese PICs während des Brennens/Löschens kurzfristig deutlich mehr als die spezifizierten 10 mA aus der Versorgungsspannung Vdd aufnahmen. Pufferkondensatoren an allen unverstärkten Vdd-Ausgängen beheben dieses Problem. Der Brenner8 erhält zwei Pufferkondensatoren, während der Brenner8P und der Brenner8mini jeweils einen Kondensator erhalten. Der Brenner8miniP benötigt keine Modifikation.

Brenner der Revisionen 2 und 3 lassen sich mit den Kondensatoren leicht nachrüsten. Ich empfehle Keramikkondensatoren von 47 .. 220 nF, die sich leicht auf der Unterseite der Platine anlöten lassen. (Meistens genügen 47 nF) Der Brenner8 und der Brenner8P erhalten einen Kondensator zwischen den Pins 31 und 32 der 40-poligen Testfassung. Der Brenner8 und der Brenner8mini erhalten einen Kondensator zwischen den Pins 2 und 3 der 5-poligen ICSP-Buchse.
Das Bild zeigt einen entsprechend modifizierten Brenner8.

Abbildung 2 Leiterseite eines entsprechend Rev. 4 modifizierten Brenner8
Brenner8 der Revision 4 benötigen die Firmware 0.8a, um alle PIC im on-board-Sockel problemlos erkennen zu können. Wird nur ICSP verwendet (Brenner8mini) kann weiterhin die Firmware 0.8 verwendet werden.

- 20 -

### 6.3.6 Revision 5

Es stellte sich heraus, dass auch der Brenner8P/Brenner8miniP von einem Vpp-Kondensator zwischen Pin2 und Pin 3 der ICSP-Buchse profitieren kann, also bekommt er ihn in der Revision 5. Die Einrüstung dieses Kondensators empfehle ich dringend.

Weitere Änderungen zielen lediglich auf eine leichte Umrüstbarkeit des Brenner8P/Brenner8miniP-Silviu zum Brenner9.

Der Brenner8P rev4 (und der Brenner8miniP-Silviu) hat einen Resettransistor Q8, der im Original ein BC338 war. Dieser Typ ist durch einen Transistor mit kleiner Basis-Kollector-Kapazität zu ersetzen. Gut geeignet ist der HF-Typ BF959. Beim Tausch des Transistors ist darauf zu achten, dass der BF959 (B-E-C) eine andere Anschlussbelegung hat als der BC338 (E-B-C) !

Der Brenner8P rev4 hat einen Widerstand R19 mit dem Wert von 330 Ohm (beim Brenner8miniP-Silviu ist das R13). Dieser Widerstand ist durch einen 100-Ohm-Widerstand zu ersetzen.

Die 10nF-Kondensatoren C6 und C7 des Brenner8P sind durch 1nF-Typen zu ersetzen. (Beim Brenner8miniP-Silviu betrifft das nur C6.)

### 6.4 Platine

Obwohl es sicherlich möglich ist, den Brenner8 auf einer Lochrasterplatine aufzubauen, empfehle ich doch die fotochemische Herstellung einer Leiterplatte. Das von mir bereitgestellte Layout (siehe Anlage) stellt keine allzu hohen Anforderungen. Das Layout ist nicht sehr filigran, und es wird nur eine einseitige Platine benötigt.

Das Layout ist etwa 75mm x 100mm groß. Platinenmaterial dieser Größe ist handelsüblich. Damit entfällt das lästige Zuschneiden des Leiterplattenmaterials.

Das Layout des Brenner8mini-P ist auch einseitig, aber etwas filigraner. Das Platinenmaß ist 83mm x 43mm.

Für den Notfall liegt auf der Brenner8-Homepage auch ein Layoutvorschlag für einen Brenner8 auf einer Lochrasterplatine.

### 6.5 Bestückung

Nach dem Ätzen und Bohren wird die Platine wie üblich bestückt. Dabei startet man mit den Drahtbrücken, es folgen die flachen Bauteile (Widerstände, Dioden), dann die 28-polige Fassung, und zum Schluss alles „sperrige“.

Die Werte der Widerstände und Kondensatoren sind unkritisch. Die Werte dürfen um 25% von den im Stromlaufplan angegebenen Werten abweichen. Eine Ausnahme bilden die Vpp-Spannungsteilerwiderstände R4 & R5. Um die spätere Kalibrierung des Brenners zu vereinfachen, sollte hier nicht von den Werten des Stromlaufplans abgewichen werden.

- 21 -

Beim Einlöten der Testfassung sollte der Arretierheben der Fassung auf „offen“ stehen, um ein Verkannten der Fassungskontakte zu vermeiden.

Wer andere Transistortypen einsetzt, muss auf die Pinbelegung dieser Typen achten. Alle von mir vorgesehenen Typen mit Ausnahme des BF959 haben die Anschlussreihenfolge E-B-C. Beim BF959 lautet sie dagegen B-E-C.

Als Dioden eignen sich alle Shottky-Dioden mit einer Spannungsfestigkeit von mindestens 30V und einer Strombelastbarkeit von mindestens 100 mA. Ich empfehle die BAT43.

### 6.6 Firmware & Bootloader brennen

Im Brenner8 arbeitet ein Steuer-PIC vom Typ PIC18F2550. Der benötigt für seine Arbeit natürlich Software. Die besteht aus
- einem Bootloader und
- der eigentlichen Firmware.

Im Normalfall wird beim Einschalten des Brenner8 die Firmware aktiviert. Sie ist für alle Brennaufgeben des Brenner8 zuständig. Der Bootloader hat nur eine Aufgabe: Er kann bei Bedarf einen neue Firmware in den Brenner8 laden. Das ist natürlich bei der Erstinbetriebnahme nötig, kann aber auch nötig sein, wenn eine verbesserte Firmware für den Brenner8 veröffentlicht wird.

Um zunächst den Bootloader in den Steuer-PIC zu bekommen wird ein Brenner benötigt, der den PIC18F2550 brennen kann. Das kann z.B. ein Brenner5 sein, oder irgendein anderer PIC-Brenner, der den PIC18F2550 unterstützt.

Der Bootloader ermöglicht es später unproblematisch die Firmware zu aktualisieren, und er übernimmt auch die Kontrolle über den Taktgenerator des Steuer-PIC. Der Bootloader liegt in verschiedenen Varianten für verschiedene Quarzfrequenzen vor (4, 8, 20 MHz). Man wählt einfach den passenden Bootloader aus, und brennt ihn mit einem Programmiergerät in den PIC.

Damit wird automatisch auch die Taktfrequenz für die Firmware festgelegt. Wenn man z.B. einen 8-MHz-Resonator verwenden will, dann brennt man einen 8-MHz-Bootloader in den PIC. Wird dann später die (eigentlich für 20 MHz ausgelegte) Firmware mit Hilfe des Bootloaders in den PIC geladen, dann funktioniert diese auch mit dem 8 MHz-Resonator.
Da der Bootloader sehr klein ist, kann er auch mit weniger zuverlässigen Programmiergeräten in den PIC18F2550 gebrannt werden.

Der PIC18F2550, der bisher nur den Bootloader enthält, wird nun als Steuer-PIC in den Brenner8 eingesetzt. Nun kann die eigentliche Firmware mit Hilfe des Bootloaders in den PIC nachgeladen werden. Die Details sind im Kapitel „Bootloader“ beschrieben.

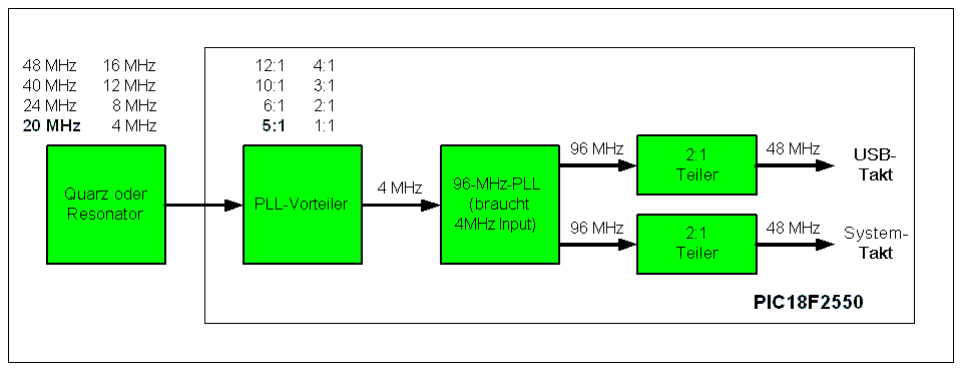
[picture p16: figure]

- 22 -

### 6.7 Taktquelle

Der Brenner kann sowohl mit einem Keramikresonator wie auch mit einem Quarz betrieben werden. Wird ein Quarz verwendet, dann sind auch die beiden Lastkondensatoren für den Quarz (C2 & C3) einzusetzen. Wird dagegen ein Keramikresonator eingesetzt, dann entfallen die beiden Kondensatoren. Der Resonator wird in der Platine am Einbauort der beiden Kondensatoren eingebaut.

Im Brenner8 passt der Mittelanschluss des Resonators in den zusätzlichen Masseanschluss zwischen den Kondensatoreinbauorten.
Im Brenner8mini-Simon-Layout wird der Resonator in die beiden Lötaugen für C2 und das untere Lötauge von C3 eingesetzt. Das Brenner8miniP-Silviu-Layout sieht keinen Resonator vor, der Bastler ist hier etwas mehr gefordert.

Als Frequenz für den Resonator/Quarz ist 20 MHz vorgesehen. Leider sind 20MHz-Resonatoren nicht leicht zu beschaffen. Weiter oben wurde beschrieben, wie man mit Hilfe des Bootloaders einen anderen Takt verwenden kann. Es gibt aber auch noch einen zweiten Weg, den Brenner8 mit einem anderen Takt als 20MHz zu betreiben. Der Einsatz anderer Resonator/Quarz-Typen ist möglich, wenn folgendes beachtet wird:

Abbildung 3 Takterzeugung im Steuer-PIC
Standardmäßig wird die Quarzfrequenz im PIC zunächst mit einem 5:1 Frequenzteiler auf 4 MHz heruntergeteilt. Aus diesen 4 MHz werden anschließend mit einer PLL 96 MHz erzeugt. Diese wiederum dient als Basis für den USB-Takt (2:1 Teilung) und den PIC-Takt (ebenfalls 2:1 Teilung).

Die 4 MHz für die PLL lassen sich natürlich nicht nur aus 20 MHz erzeugen. Da der Eingangsteiler neben dem Teilverhältnis 5:1 auch die Teilverhältnisse 12:1, 10:1, 6:1, 4:1, 3:2, 2:1 und 1:1 beherrscht, kommen auch Resonatoren/Quarze mit 48 MHz, 40 MHz, 24 MHz, 16 MHz, 12 MHz, 8 MHz und 4 MHz in Frage. Man muss nur die Vorteilereinstellung ändern.

- 23 -

Abbildung 4 Resonator/Quarz-Einstellung für den Steuer-PIC
Die Vorteilereinstellung ist in der PIC-Konfiguration festgelegt, die im Firmware-HEX-File abgelegt ist. Mit einer geeigneten Brennsoftware, wie P18 oder US-Burn, lässt sich diese Konfigurationseinstellung vor dem Brennen des Steuer-PICs manipulieren. Dazu wird nach dem Laden des HEX-Files in der „Basics“ -Karteikarte von P18 oder US-Burn die Option „Config from HEX-File“ deaktiviert. Danach wechselt man auf die Karteikarte „PIC Configuration“. Dort wählt man die Unterkarteikarte „CONFIG1L“.
Hier nun findet man alle Takteinstellungen des PIC. Wichtig ist die Option „96 MHz PLL Prescaler“, die standardmäßig auf „Divide by 5 (20MHz input)“ steht. Diese Option passt man einfach der gewünschten Resonator/Quarz-Frequenz an. Die Einstellung „Divide by 2 (8MHz input)“ erlaubt z.B. den Einsatz eines 8 MHz Keramikresonators.

- 24 -

### 6.8 Funktionstest

Nach dem Zusammenbau des Brenners und dem Einsetzen des Steuer-PICs wird er im laufenden Betrieb an einen PC angeschlossen. Unmittelbar darauf leuchtet die grüne LED auf, gefolgt von der gelben LED. In der gleichen Reihenfolge verlöschen beide LEDs auch wieder nach jeweils 0,5 Sekunden Leuchtzeit.
An der Kathode der Diode D1 kann man eine Spannung zwischen 10 V und 20 V messen. Fehlt das Aufblinken der LEDs und ist die Spannung an der Kathode von D1 < 6V, dann ist die Firmware nicht korrekt in den Steuer-PIC gebrannt, oder der Quarz schwingt nicht.

Ist der USB-Treiber noch nicht installiert, dann meldet sich Windows, und verlangt die Installation des Treibers, die in einem anderen Kapitel beschrieben ist. Sollte
Windows melden, dass sich ein USB-Device nicht korrekt angemeldet hat, und deshalb nicht benutzt werden kann, so könnte z.B. ein Quarz mit falscher Frequenz eingesetzt worden sein.

In der Brennersoftware US-Burn gibt es die Möglichkeit, zu Testzwecken die Betriebsspannung Vdd, die Programmierspannung Vpp sowie die Daten- und die Takt-Leitung einzeln ein- und auszuschalten („Options – Hardware“). Zur besseren Orientierung wird dabei die grüne LED zusammen mit Vdd und die gelbe LED zusammen mit Vpp geschaltet.
Je nach gewähltem IC-Sockel („Basic“) werden die Spannungen auf andere Pins des 40-poligen IC-Sockels geschaltet:

Tabelle 2 Signale am Testsockel

Signal | Vdd (5V) | Vpp (13V) | SCLK (5V) | SDATA (5V)
8-/ 14-Pin | 1 | 4 | 38 | 39
18-Pin / ICSP | 36 | 4 | 34 | 35
28- /40-Pin | 11&32 | 1 | 39 | 40

Bei ausgewähltem 8-/14-Pin-Sockel, liegt am Pin 40 eine Spannung von unter 0,25V an.
Am 5-poligen ICSP-Anschluss liegen die Spannungen gemäß meinem Standard an, wenn als IC-Sockel „18 Pins / ICSP“ gewählt wurde:

Tabelle 3 Signale am ICSP-Anschluss

Signal | Vdd (5V) | Vpp (13V) | SCLK (5V) | SDATA (5V) | Vss (0V)
ICSP-Pin | 2 | 1 | 5 | 4 | 3

Vdd sollte einen Pegel von mindestens 4,5 V erreichen, SDATA und SCLK sollten über 4V liegen. Diese Pegel hängen von der Spannung im USB-Bus ab.

Der Pegel von Vpp liegt zwischen 10V und 20V. Er wird später noch durch eine Kalibrierung auf einen bestimmten Sollwert justiert. Diese Kalibrierung ist in einem späteren Kapitel beschrieben, und sollte unbedingt vor den ersten Brennversuchen durchgeführt werden.

- 25 -

Bevor die Kalibrierung abgeschlossen ist, darf kein PIC in den Testsockel oder an den ICSP-Verbinder angeschlossen werden. Er könnte durch Überspannung zerstört werden.

### 6.9 ICSP-Adapter

Alle 14-Bit- und 16-Bit-Kern PICs (PIC12F6xx, PIC16Fxxx, PIC18Fxxxx) mit DIL-Gehäuse lassen sich im Testsockel des Brenner8 programmieren. 8-/14-/18-/28- und 40-Pin DIL-Typen sind dabei so in den Testsockel einzusetzen, dass Pin 1 des Chips in Pin 1 der Fassung steckt.

PICs in anderen Gehäusebauformen wie auch dsPIC30Fxxx-, PIC1xF5x und PIC10Fxxx-Typen müssen über einen Adapter an den 5-poligen ICSP-Steckverbinder angeschlossen werden.
Der Brenner8mini hat keinen Testsockel. Somit werden für ihn auch bei DIL-PICs ICSP-Adapter benötigt.

Auch wenn der PIC beim Brennen mit allen Pins in der Fassung des Brenners steckt, elektrisch sind mit dem Brenner nur 5 Leitungen verbunden. Das ist möglich, da der PIC mit Hilfe einer seriellen Datenübertragung programmiert wird - dem In Circuit Serial Programming (ICSP).

Dazu benötigt man:

1. eine Leitung für die ca. +12V-Programmierspannung
2. eine Leitung für die +5V-Betriebsspannung
3. eine Masseleitung
4. eine Datenleitung
5. eine Taktleitung

Diese 5 Leitungen des Brenners werden an folgende Pins des PIC angeschlossen:

Tabelle 4 Der ICSP-Anschluss
Nr. | Leitung des Brenners | Signalbezeichnung | Pin des PIC
1 | Leitung für die +12V-Programmierspannung | Vpp | MCLR/Vpp (der Reset-Anschluss)
2 | Leitung für die +5V-Betriebsspannung | Vdd | Vdd
3 | Masseleitung | Vss | Vss
4 | Datenleitung | Data | PGD (meist RB7)
5 | Taktleitung | Clk | PGC (meist RB6)

Größere PICs haben mehrere Pins für Vdd und Vss. Der Hersteller empfiehlt, alle Pins zusammen zu verwenden. Oft (aber leider nicht immer) genügt aber auch die Verwendung von jeweils einem Vss und einem Vdd-Pin.

An der ICPS-Buchse stehen also alle Signale zur Verfügung, um einen PIC zum Programmieren an den Brenner anzuschließen. Ein Beispiel für die Nutzung der ICSP-Buchse sind Adapter, mit dem eine zusätzliche Schaltkreis-Fassung an einen

- 26 -

beliebigen Brenner angeschlossen werden kann, wenn dieser über die ICPS-Buchse verfügt.

### 6.9.1 Grundregeln für ICSP-Adapter

Ist es wirklich nötig, über ein einfaches Kabel Worte zu verlieren? JA ES IST NÖTIG.

CLK-Schirmung
In der Belegung des Kabels gibt es eine Schwachstelle. Die für störende Einstreuungen sehr empfängliche Takt-Leitung (CLK, PGC) muss dringend von den anderen Leitungen abgeschirmt werden. Dazu ist nun keine komplette Schirmung nötig, aber eine separate Masseleitung zwischen CLK und DATA ist wenigstens erforderlich. Aus diesem Grunde verwende ich stets 6-poliges Hosenträgerkabel mit 2 Masseleitungen: eine zwischen Vdd und DATA und eine weitere zwischen DATA und CLK. Das ist in den untenstehenden Stromlaufplänen deutlich zu sehen.

Natürlich gibt es auch andere Lösungen, um ein Übersprechen auf die CLK-Leitung zu vermeiden, z.B. kann man die CLK-Leitung vom restlichen Kabel getrennt verlegen. Man kann auf die Masseleitung zwischen Vdd und DATA auch verzichten, ihre Funktion erfüllt ja auch die Masse zwischen DATA und CLK.
Da will ich keine weiteren Vorschriften machen. Hauptsache CLK ist vor Einstreuungen geschützt.

Wer diese einfache Regel missachtet, wird feststellen, dass schon die Autodetect-Funktion der Brennersoftware nicht funktioniert. Vom Brennen ganz zu schweigen.

Wie lang darf ein ICSP-Kabel eigentlich sein?
Es sollte so lang wie nötig und so kurz wie möglich sein. Wer nur einen zusätzlichen Sockel adaptieren will, kommt mit 10 cm aus. Für das programmieren eines PIC in der fertig aufgebauten Anwendungsschaltung sollten 20 cm auch genügen. Wenn CLK ordentlich geschirmt ist, sollte aber auch 1/2 Meter kein Problem sein. Zu lange Kabel und Kabel ohne jede CLK-Schirmung führen immer wieder zu Brennproblemen.

Nachfolgend einige Beispiele für ICSP-Adapter.

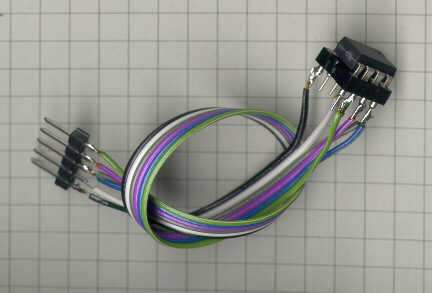
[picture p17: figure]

- 27 -

### 6.9.2 ICSP-Adapter für PIC12F6xx

Abbildung 5 ICSP-Adapter für PIC12F6xx
Das obige Foto zeigt einen ICSP-Adapter für PIC12F6xx wie er für den Brenner8mini benötigt wird. (Der Brenner8 kann den PIC12F6xx im Testsockel brennen.) Er besteht nur aus einer 5-poligen Stiftleiste, die in die ICSP-Buchse des Brenners gesteckt wird, einer DIL-Fassung für den PIC und einem 6-adrigen Flachbandkabel. Die nachfolgende Abbildung zeigt den Stromlaufplan:

Abbildung 6 ICSP-Adapter für PIC12F6xx - Stromlaufplan
Es wird ein 6-adriges Kabel verwendet, da ich im Kabel zwei Masseleitungen (Vss) vorgesehen habe. Wichtig ist dabei vor allem die blaue Leitung. Sie schirmt die Taktleitung (Clk, PGC) von den anderen Leitungen. Das ist kein Luxus, sondern für die sichere Arbeit des Brenners nötig.

Dieser Adapter eignet sich NICHT für PIC10F2xx im 8-poligen DIL-Gehäuse, da diese eine andere Pinbelegung haben.

- 28 -

### 6.9.3 ICSP-Adapter für PIC im PLCC-Gehäuse

Abbildung 7 Adapter für PLCC-44
Das obige Foto zeigt einen ICSP-Adapter für PICs im PLCC-44-Gehäuse. Im konkreten Fall ist es ein PIC16F87xA-Typ.
Der Adapter besteht nur aus einer 5-poligen Stiftleiste, die in die ICSP-Buchse des Brenners gesteckt wird, einer Lochrasterplatine mit einer PLCC-44-Fassung für den PIC und einem 6-adrigen Flachbandkabel. Die nachfolgende Abbildung zeigt den Stromlaufplan:

Abbildung 8 Adapter für PLCC-44 - Stromlaufplan
Die zum PIC12F6xx-Adapter gemachten Aussagen gelten auch hier.

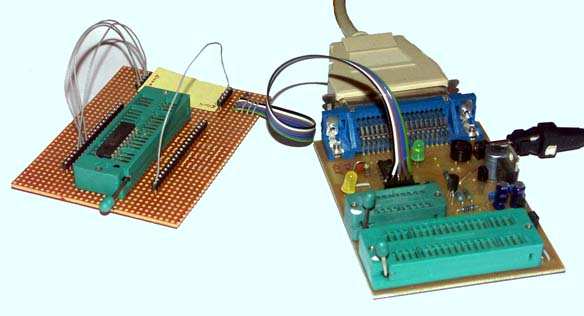
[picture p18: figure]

- 29 -

Microchip empfiehlt generell alle Vss-Pins und alle Vdd-Pins anzuschließen. Bei vielen (aber nicht bei allen) PICs geht es auch mit nur je einem Pin. Wer aber einen Adapter neu baut, kann es ja gleich richtig machen, und der Microchip-Empfehlung folgen.

### 6.9.4 Universeller Programmieradapter für DIL-PICs

Dieser Adapter dient zum Programmieren beliebiger PIC-Controller im DIL-Gehäuse. Um einen PIC im Adapter zu programmieren, müssen zunächst 5 bis 7 Drahtbrücken in den Adapter eingesetzt werden. Dabei ist sorgfältig vorzugehen, da eine falsch gesetzte Brücke zur Beschädigung des Target-PICs führen kann. Wie die Drahtbrückern einzusetzen sind ist detailliert im Handbuch des Adapters beschieben.
Näheres findet sich auf http://www.sprut.de/electronic/pic/icsp/icsp.htm#universell

Abbildung 9 Universeller Programmieradapter (hier am Brenner5)

### 6.10 ICSP- Brennen in der fertigen Schaltung

Zum Brennen eines PIC in der fertig aufgebauten Schaltung eignen sich nur der Brenner8-P und der Brenner8mini-P.

Eine weitere Anwendung der ICPS-Verbindung ist das Brennen eines PIC, der bereits in seine Anwendungsschaltung eingebaut ist.

Dazu verfügt die Leiterplatte der Anwendungsschaltung des PIC auch über eine ICPS-Buchse. Brenner und Anwenderschaltung werden über ein 5-poliges Kabel miteinander verbunden, und der PIC wird "zuhause" gebrannt. Das lästige Umstecken des PIC zwischen Anwendungsschaltung und Brenner entfällt, und das komfortable Brennen von PICs im SMD-Gehäuse wird überhaupt erst möglich.

Microchip verwendet auf seiner Test-Platinen einen 6-polige Westernbuchse, die mit ICD oder ICSP beschriftet ist. Die ersten 5 Pins dieses Anschlusses entsprechen den 5-Pins meines ICSP-Anschlusses, der 6. Pin der Western-Buchse ist reserviert.

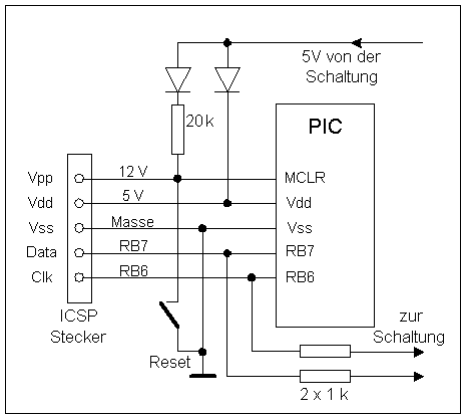
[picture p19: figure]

- 30 -

### 6.10.1 Entwurf einer ICSP-tauglichen Schaltung

Abbildung 10 ICSP-taugliche Schaltung
Die 5 Pins, die zum ICSP an den Brenner angeschlossen werden müssen, dienen ja nicht exklusiv zum Brennen, sie werden meist auch in der Anwendungsschaltung verwendet.
Um zu verhindern, dass sich Brenner und Anwendungsschaltung gegenseitig in ihrer Funktion stören, sind einige Dinge beim Entwurf der Anwendungsschaltung zu beachten:

### 6.10.1.1 Programmierspannung MCLR/Vpp

Dieser Anschluss ist am schwierigsten.

Meine Brenner8 (bis Rev. 2) ziehen dieses Pin über einen 10k-Widerstand auf Masse, oder über einen Schalttransistor auf +12V.
In der Anwenderschaltung wird dieses Pin mit einem Hochziehwiderstand auf 5V gehalten, oder mit einem Resettaster kurzfristig auf Masse gelegt. Dass der Reset-Taster beim Brennen keinesfalls gedrückt werden darf ist damit klar!!

Schwierig ist aber auch der Hochziehwiderstand. Beim Brennen trennt nur dieser Widerstand die 5-V-Versorgung der Anwendungsschaltung von den 12V des Brenners. Hier muss deshalb eine Diode vor Schäden durch Überspannung schützen.

Der 5V-Hochziehwiderstand muss deutlich größer sein (mindestens 20 X) als der Widerstand, der im Brenner das MCLR-Pin mit Masse verbindet. Ansonsten kann der Brenner MCLR nicht sauber auf Masse ziehen. Wird ein Brenner8 (bis Rev. 2)

- 31 -

verwendet, sollte der Hochziehwiderstand etwa 200kOhm betragen. Microchip empfiehlt aber einen Wert von 40 kOhm.

Eine Alternative ist die in der Abbildung gezeigte Trennung von ICSP-Vdd von der 5V-Versorgung der Schaltung mit Dioden. Sie erlaubt die Nutzung deutlich kleinerer Hochziehwiderstände.

Ab der Revision 3 kann die P-Version des Brenner8 das MCLR-Pin mit einem Transistor aktiv nach Vss ziehen. Damit entfällt dieses Problem.

### 6.10.1.2 Betriebsspannung Vdd

Beim Brennen speist der Brenner den PIC mit der nötigen Betriebsspannung. Ist der PIC der einzige Spannungsverbraucher in der Anwenderschaltung, kann die +5V-Leitung des Brenners direkt mit dem Vdd-Pin des PIC verbunden werden. Vor dem Anschluss des Brenners muss dann unbedingt die normale Betriebsspannung des PIC abgeschaltet werden.

Sind neben dem PIC noch andere Bauelemente mit der 5-V-Versorgung der Anwendungsschaltung verbunden, würde der Brenner bei Brennen die gesamte Anwendungsschaltung in Betrieb nehmen. Bei größeren Schaltungen könnte das den Brenner überlasten. Eine Entkopplung mit Shottky-Dioden oder ein Jumper in der +5V-Leitung trennen dann besser die beiden potentiellen 5-V-Quellen.
Wird mit einer Shottky-Diode entkoppelt, dann ist die Vdd des PICs im Normalbetrieb ca. 0,2V kleiner als Vdd der restlichen Schaltung. Meist ist das unkritisch, aber wenn Vdd z.B. als positive Referenzspannung des ADC verwendet wird, kann es zu Messwertverfälschungen des ADC kommen. In diesem Fall ist ein Jumper der Diode vorzuziehen.

Größere PICs besitzen mehrere Vdd-Pins. Zum Programmieren sind alle diese Pins untereinander zu verbinden, was in der Anwenderschaltung in der Regel ohnehin gegeben ist.

### 6.10.1.3 Masseverbindung Vss

Das ist die einzige unkritische Verbindung. Normalerweise wird die Masse des Brenners direkt mit der Masse des PIC und damit auch mit der Masse der Anwenderschaltung verbunden.
Größere PICs besitzen mehrere Vss-Pins. Zum Programmieren sind alle diese Pins untereinander zu verbinden, was in der Anwenderschaltung in der Regel ohnehin gegeben ist.

### 6.10.1.4 Takt- und Datenleitung (PGC und PGD)

PGD und PGC sind bei den meisten PICs gleichzeitig die Port-Pins RB6 und RB7.

Wer in der Anwendungsschaltung auf diese beiden Pins verzichten kann, sollte sie exklusiv der ICSP-Schnittstelle zur Verfügung stellen. Werden die beiden Pins aber benötigt, sollten sie mit der ICSP-Buchse direkt, aber mit dem Rest der Schaltung über Widerstände von wenigstens 1 kOhm verbunden werden. Ist so ein 1 kOhm Widerstand für die Applikationsschaltung zu groß, helfen nur noch Jumper, die vor dem Brennen geöffnet werden müssen, um den PIC von der restlichen Schaltung zu trennen.

- 32 -

## 7 Treiberinstallation

Nachdem der Brenner8 fertig aufgebaut wurde, und der Steuer-PIC die korrekte Firmware eingebrannt bekam, muss er nun noch unter Windows eingerichtet werden.

Der Brenner8 benötigt den Microchip Custom Driver (mpusbapi.dll). Den findet man auf der Microchip Homepage, oder im Softwarepaket US-Burn auf meiner Homepage. Da US-Burn ohnehin für den Brenner8 benötigt wird, lädt man sich das US-Burn-Zip-File von meiner Homepage,

http://www.sprut.de/electronic/soft/usburn/usburn.htm - download

und entpackt es in einen Ordner auf der lokalen Festplatte.
Der Treiber liegt dann im Unterordner driver .

Nun kann der Brenner8 an den Windows-PC angesteckt werden. Windows findet automatisch das ihm noch unbekannte USB-Gerät PIC-Brenner8 (sprut 2006) ausgibt.

Abbildung 11 Neue Hardware gefunden
Anschließend fordert Windows zur Treiberinstallation auf.

Abbildung 12 Hardware Assistent 1

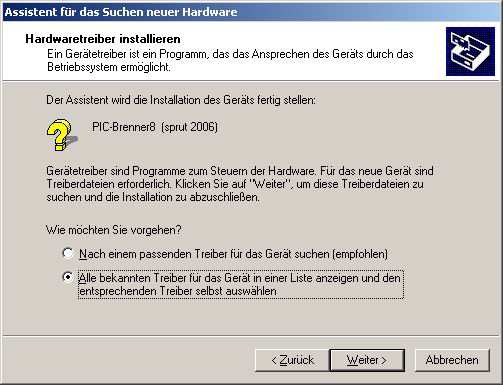
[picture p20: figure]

- 33 -

Nach einem Klick auf Weiter ist man im Assistenten für die Hardwareinstallation.

Abbildung 13 Hardware Assistent 2
Hier wählt man die untere der beiden möglichen Optionen aus, um den Treiber manuell auswählen zu können. Danach klickt man auf Weiter.

Nun muss man den Brenner in eine Geräteklasse einordnen. Da er nicht so richtig in eine der üblichen Gruppen passt, wählt man Andere Geräte, und klickt auf Weiter.

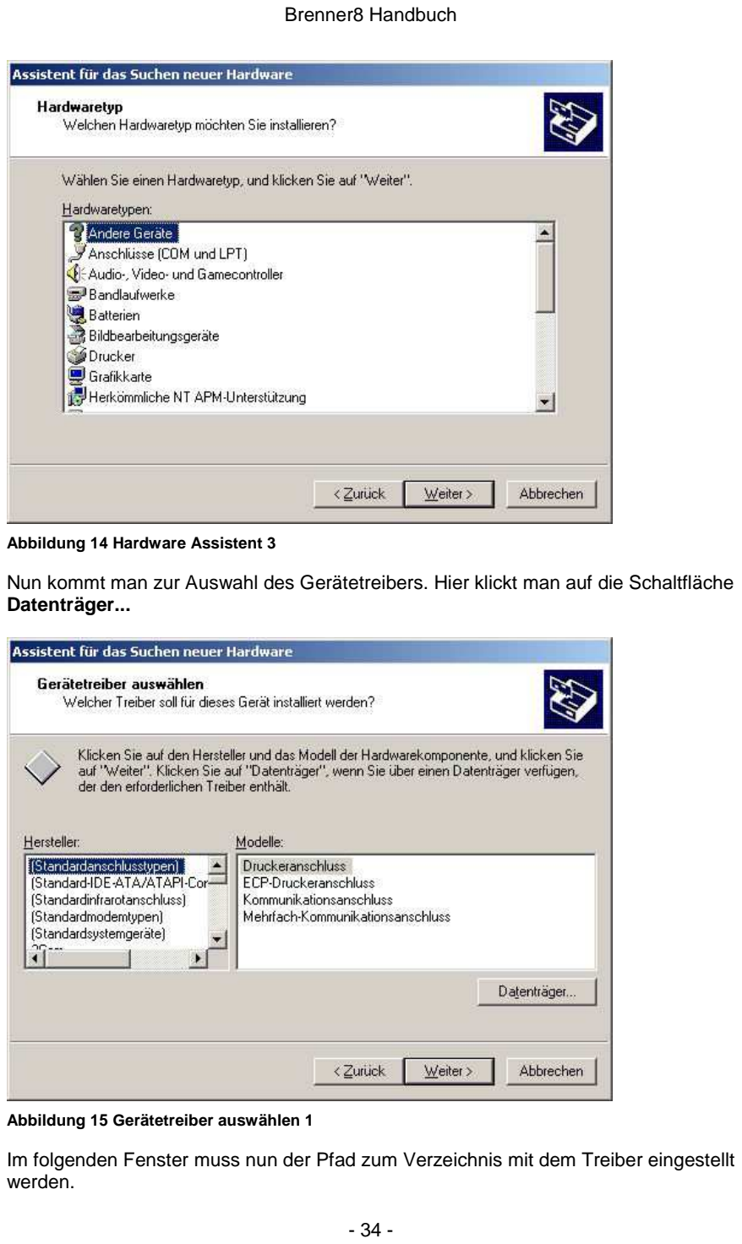
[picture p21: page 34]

- 34 -

Abbildung 14 Hardware Assistent 3
Nun kommt man zur Auswahl des Gerätetreibers. Hier klickt man auf die Schaltfläche Datenträger...

Abbildung 15 Gerätetreiber auswählen 1
Im folgenden Fenster muss nun der Pfad zum Verzeichnis mit dem Treiber eingestellt werden.

- 35 -

Abbildung 16 Pfad zum Treiber einstellen
Windows schaut in diesem Verzeichnis nach, und finden einen passenden Treiber für ein PIC-Brenner8 (sprut).

Abbildung 17 Gerätetreiber auswählen 2
Im folgenden Fenster wird die Auswahl mit Weiter bestätigt.

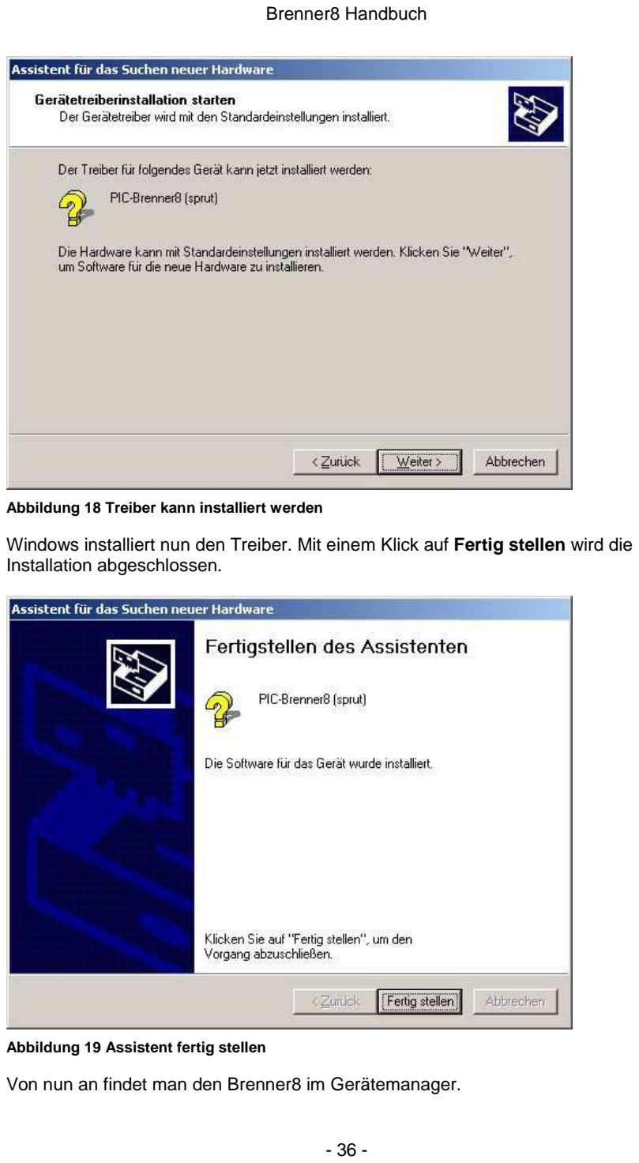
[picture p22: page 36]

- 36 -

Abbildung 18 Treiber kann installiert werden
Windows installiert nun den Treiber. Mit einem Klick auf Fertig stellen wird die Installation abgeschlossen.

Abbildung 19 Assistent fertig stellen
Von nun an findet man den Brenner8 im Gerätemanager.

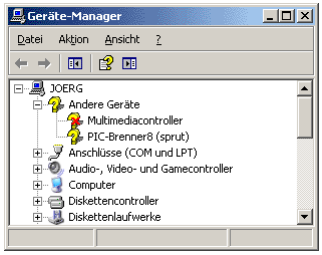
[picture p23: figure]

- 37 -

Abbildung 20 Gerätemanager
Im Gerätemanager sollte dem Betriebssystem verboten werden, den Brenner8 abzuschalten um Energie zu sparen. Ansonsten kann es passieren, dass der Brenner8 extrem langsam arbeitet.

Abbildung 21 Gerätemanager - Energiesparoption
Damit ist der Brenner8 einsatzbereit.

- 38 -

## 8 Kalibrierung

Nachdem der Brenner8 fertig aufgebaut wurde, der Steuer-PIC die korrekte Firmware eingebrannt bekam und der USB-Treiber eingerichtet wurde, muss die Programmierspannungserzeugung des Brenners noch kalibriert werden.

Ein unkalibrierter Brenner8 ist in der Lage jeden PIC innerhalb kürzester Zeit zu zerstören! Insbesondere wenn als Diode D1 ein Shottky-Typ eingesetzt wurde, kann problemlos eine Programmierspannung von Vpp=25V erzeugt werden. Das überlebt kein PIC!!

Der Brenner8 erzeugt die Programmierspannung Vpp mit Hilfe eines kleinen Schaltreglers. Per Software kann die Höhe der Spannung variiert werden. Damit ist garantiert, dass jeder PIC die für ihn optimale Programmierspannung bekommt.

Das funktioniert aber nur optimal, wenn der Steuer-PIC des Brenners die Höhe der Programmierspannung auch genau messen kann.

Die Spannung wird im Brenner8 über einen Spannungsteiler gemessen, und mit einer Referenzspannung (von einer Z-Diode) verglichen.
Bei der Kalibrierung werden die Z-Spannung und das Spannungsteilerverhältnis ermittelt.

Benötigt werden:
- Brenner8
- US-Burn-Software
- Voltmeter

### 8.1 Vorbereitung

Den Brenner8 am PC anschließen.
US-Burn im PC starten
In US-Burn auf die Registerkarte Options – Hardware wechseln.

Die nötigen Einstellungen werden in der „Box“ programming voltage Vpp calibration vorgenommen, und erfolgen in drei Schritten

1. Einstellung der Z-Spannung
2. Einstellung des Spannungsteilerverhältnisses
3. Automatische Reglereinstellung

### 8.2 Schritt Nr. 1: Z-Spannung

Im Stromlaufplan ist eine 3,3V-Z-Diode vorgesehen, aber typische Z-Dioden haben eine Toleranz von 10%. Man kann sich auf die Spannungsangabe also nicht verlassen.
Die Spannung über der Z-Diode D3 wird mit dem Voltmeter gemessen. (Am Brenner8P z.B. zwischen den Lötstiften LSP2 und LSP3.) Der Spannungswert wird dann im Feld Z-voltage eingestellt. Mit den beiden Pfeil-Schaltflächen kann die Spannung zwischen 2V und 4V in 0,01V-Schritten angepasst werden.

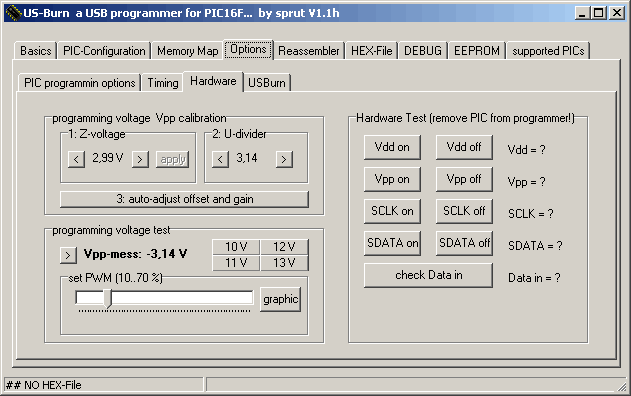
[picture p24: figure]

- 39 -

Damit der neu eingetragene Wert wirksam wird, wird abschließend auf die Schaltfläche apply geklickt. Im Textfenster der BASIC –Registerkarte erscheint daraufhin ein Kalibrierwert, der in der Regel etwas kleiner als 1 ist.

Abbildung 22 USBurn - Options-Hardware

### 8.3 Schritt Nr. 2: Spannungsteiler

Der Spannungsteiler zum Messen der Vpp-Spannung besteht aus den Widerständen R4 und R5. Sein Spannungsteilerverhältnis ist theoretisch 3,14. In der Praxis kann der Wert aber abweichen. Die Einstellung erfolgt im Feld U-divider.

Zur Vorbereitung schließt man das Voltmeter zwischen der Kathode von D1 und Vss an (alternativ über C5). (Am Brenner8P z.B. zwischen den Lötstiften LSP1 und LSP3.) Mit dem Schieberegler set PWM stellt man eine Spannung von etwa 13V (auf dem Multimeter) ein. (Die Spannung sollte möglichst hoch sein, darf aber 14V auf keinen Fall überschreiten! ) In einigen USBurn-Versionen läßt sich der Schieberegler nicht bedienen, dann ist die vorhandene Spannung so zu nutzen wie sie ist.

Der Brenner8 misst die Spannung auch, und zeigt seinen Messwert als Vpp-mess an. Durch Ändern von U-divider wird nun der vom Brenner8 gemessene Spannungswert dem Messwert des Multimeters möglichst gut angenähert.
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

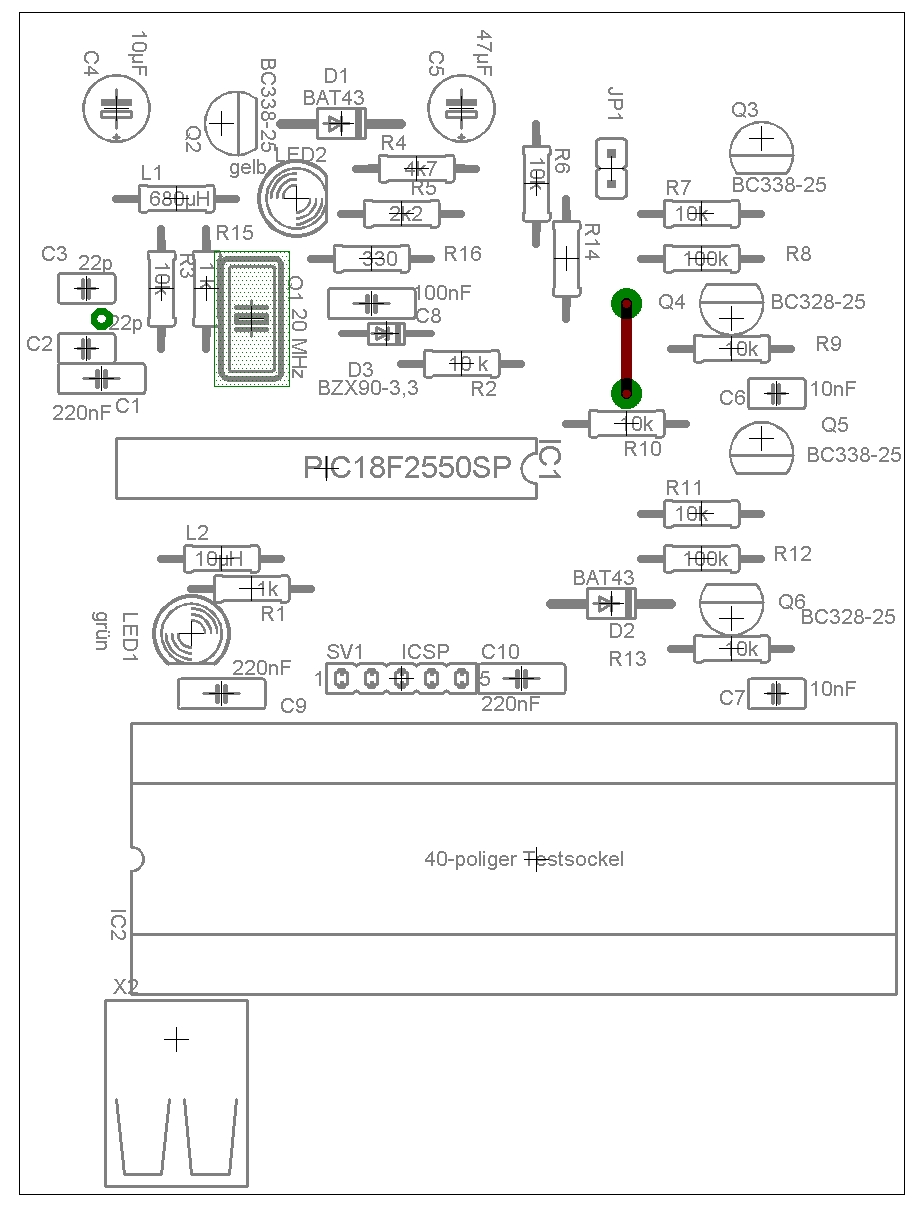
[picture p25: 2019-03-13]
img/b8p5.jpg

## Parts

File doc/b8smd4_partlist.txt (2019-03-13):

Bestückungsliste zum Brenner8smd R4

Part			      |	St. | Value	        | Reichelt	      | Conrad      Conrad				
			      |	    |			| Artikel-Nr	      | Artikel-Nr  Name
==============================|=====|===================|=====================|=================================================
C1, C10, C11		      |	3   | 220nF		| - not available -   | 445222	    KERKO CHIP 0805 X7R 0,22µF 10% 16V G		
C2, C3			      |	2   | 22p		| NPO-G0805 22P	      | 445432	    KERKO CHIP 0805 NP0 22pF 5% 50V G		
C4, C5			      |	2   | 47µF		| RAD 47/35	      | 472506	    Elko 47uF/35V RM 2,5		
C6, C7			      |	2   | 10nF		| X7R-G0805 10N	      | 445403	    KERKO CHIP 0805 X7R 0,01µF 10% 50V G		
C8, C9			      |	2   | 100nF		| X7R-G0805 100N      | 445210	    KERKO CHIP 0805 X7R 0,1µF 10% 50V G 		
D4, D5			      |	2   | BAT43		| BAT 43 SMD	      | 140902	    SMD-Diode LL4148		
D6			      |	1   | BZX97-3,3	  	| SMD ZF 3,3	      | 141763	    SMD-Zehner Diode 0,5 BZV W 3,3V		
IC1			      |	1   | PIC18F2550SP	| PIC 18F2550-I/SO    | --	    - not available -
IC2			      |	1   | 40-pl.Testsockel  | TEX 40	      | 189324	    PRÄZISIONS TESTSOCKEL 40 POLIG		
L1			      |	1   | 680µH		| SMCC 680µ	      | 536342	    Miniatur-Festinduktivität 680µH		
L2			      |	1   | 10µH		| SMCC 10µ	      | 535729	    Miniatur-Festinduktivität 10µH 		
LED1			      |	1   | grün		| LED 3MM 2MA GN      | 145971	    LowCurrent-LED, 3mm grün 		
LED2			      |	1   | gelb		| LED 3MM 2MA GE      | 145980	    LowCurrent-LED, 3mm gelb 		
Q1			      |	1   | 20 MHz		| 20,0-HC49U-S	      | 445206	    SMD-Quarz  HC-49/US-SMD		
Q4, Q6, Q9		      |	3   | BC338-25	  	| BCX 70H SMD	      | 152896	    BCX 70H 		
Q7, Q8			      |	2   | BC328-25	  	| BCX 71H SMD	      | 152950	    BCX 71H		
R1, R15			      |	2   | 1k		| SMD 1/4W 1,0K	      | 402540	    SMD-Widerstand in Chipausführung 1207		
R2, R3, R6, R9, R10, R11, R13 |	7   | 10k		| SMD 1/4W 10K	      | 402664	    SMD-Widerstand in Chipausführung 1207 		
R4			      |	1   | 4k7		| SMD 1/4W 4,7K	      | 402621	    SMD-Widerstand in Chipausführung 1207		
R5			      |	1   | 2k2		| SMD 1/4W 2,2K	      | 402583	    SMD-Widerstand in Chipausführung 1207		
R7			      |	1   | 10k		| SMD-0805 10,0K      | 406376	    SMD-Widerstand in Chipausführung 0805		
R8			      |	1   | 100k		| SMD-0805 100K	      | 406490	    SMD-Widerstand in Chipausführung 0805		
R12			      |	1   | 100k		| SMD 1/4W 100K	      | 402788	    SMD-Widerstand in Chipausführung 1207		
R14, R17, R18, R19, R20, R21  |	6   | 0		  	| SMD 1/4W 0,0	      | 402222	    SMD-Widerstand in Chipausführung 1206 		
R16			      |	1   | 330		| SMD 1/4W 330	      | 402486	    SMD-Widerstand in Chipausführung 1207		
SV1			      |	1   | ICSP		| BL 1X10G 2,54	      | 736350	    Buchsenleiste 20-polig		
X2			      |	1   | USB-B-H		| USB AWF	      | 747085	    USB-Buchse ultra-flach 90°		
JP1			      |	1   | Stiftleiste	| SL 1X36G 2,54	      | 744000	    Stiftleiste 10polig RM 2,54		
zu JP1			      |	1   | Jumper		| JUMPER 2,54	      | 734152	    Codierbrücke schwarz			

Sowie drei Drahtbrücken laut Bestückungsplan

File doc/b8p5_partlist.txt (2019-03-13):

Partlist für Brenner8P R5

Part     Value			Reichelt	Conrad
======================================================

C1       220nF                 Z5U-5 220n
C2, C3   22p                   Kerko 22p
C4       10µF                  rad10/100
C5       47µF                  rad47/35
C6, C7   1nF                   X7R-2,5 1,0n
C8       100nF                 Z5U-5 100n
C9       100nF                 Z5U-5 100n
C10      100nF                 Z5U-2,5 100n
D1, D2   BAT43                 BAT 43
D3       BZX97-3,3             ZF 3,3
D4       BAT43                 BAT 43
IC1      PIC18F2550SP          PIC18F2550-I/SP
	 28-polige IC-Fassung  GS 28P-S
IC2      40-poliger Testsockel TEX 40
JP1      Jumper                Jumper 2,54 RT
L1       680µH                 SMCC 680µ
L2       10µH                  SMCC 10µ
LED1     grün                  LED5mm2MAgn
LED2     gelb                  LED5mm2MAge
LSP1     Lötstift                 
LSP2     Lötstift                 
LSP3     Lötstift                 
Q1       20 MHz                20,0000-HC49U-S
Q2, Q3   BC338-25              BC338-25
Q4       BC328-25              BC328-25
Q5       BC338-25              BC338-25
Q6, Q7   BC328-25              BC328-25
Q8       BF959                 BF959
R1       1k                    1/4W 1K
R2, R3   10k                   1/4W 10K  
R4       4k7                   1/4W 4,7K
R5       2k2                   1/4W 2,2K
R6, R7   10k                   1/4W 10K
R8       100k                  1/4W 100K
R9..R11  10k                   1/4W 10K
R12      100k                  1/4W 100K
R13      10k                   1/4W 10K
R14      100                   1/4W 100
R15      1 k                   1/4W 1K
R16      330                   1/4W 330
R17, R18 10k                   1/4W 10K  
R19      100                   1/4W 100
SV1      ICSP                  BL 1X10G 2,54
X2       USB-B-H               USB BW

Die Buchse SV1 ist auf 5 Pins zu kürzen. Ein 2-Pin langes Stück vom Rest ist für JP1 zu verwenden.

Alle Widerstands- und Kapazitätswerte sind unkritisch (25%) außer R4, R5.

Es muß mindestens eine Firmware V 0.5 verwendet werden.

Anstelle von Q1+C2+C3 kann auch ein 20 MHz Keramikresonator verwendet werden:

Part     Value			Reichelt	Conrad
======================================================
Q1a      20 MHz                 -

Im Dokument 
http://www.sprut.de/electronic/pic/projekte/brenner8/brenner8.pdf
beschreibe ich auch die Nutzung von Resonatoren mit z.B. 8 oder 12 MHz.

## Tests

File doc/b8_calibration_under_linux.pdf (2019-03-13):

### 1.1 Calibration of Brenner8 under Linux

After the assembly of the Brenner8, the programming of the control PIC and the installation of the USB-driver the Vpp-generation of the Brenner8 has to be calibrated.

A non-calibrated Brenner8 can destroy every target-PIC in shortest time! It can produce Vpp-voltages of 25V and above. No PIC survives this!

A small boost-converter is used in the Brenner8 to generate the programming voltage Vpp. The voltage level can be controlled by software. Such every target-PIC gets its ideal programming voltage.
This can function only if the control PIC of the Brenner8 can measure the Vpp level precisely.

The programming voltage is measured by the control PIC via a voltage-divider and compared with a reference voltage (from a zener-diode). During calibration Z-voltage and voltage-divider-ratio are determined.

To calibrate the programmer you need:
- Brenner8
- usburn-software
- Voltmeter

### 1.1.1 Preparation

Connect the Brenner8 to the PC.

The calibration is done in 3 steps

1. manual adjustment of the zener-voltage
2. manual adjustment of the voltage divider (Div)
3. automatic regulator adjustment

### 1.1.2 Step No. 1: Z-Voltage

The Brenner8 contains a 3,3V-Zener-Diode, but typical Z-diodes have up to 10% voltage error. Thus we have to measure the real voltage of our individual Z-diode.
The voltage over the Z-Diode D3 has to be measured by a voltmeter. (At the Brenner8P e.g. between contacts LSP2 und LSP3.)

Start now usburn with the option -k or --calibration. In the terminal usburn shows now the internally stored value of the Z-diode-voltage.

By typing in „+“ and „-“ (the „“-symbol stands for the Enter-key) the value can be changed in small increments, until it is identical to the value measured by the voltmeter.
(One can type in e.g. „++++++++++++“ to save time :-)

By typing in „=“ this calibration step is finished, and the new Z-voltage is stored in the Brenner8.

### 1.1.3 Step No. 2: Voltage-Divider

The resistors R4 and R5 build up a voltage divider to measure the Vpp-voltage. Their default divider-ratio is 3.14, but the real value may differ a little bit because of tolerances.

Connect the voltmeter between the cathode of D1 and Vss (or between both terminals of C5). At the Brenner8 you can connect the voltmeter between the contacts LSP1 and LSP3.

The Brenner8 measures the Vpp-voltage and shows the result in the terminal as Vpp-mess.

By typing in „+“ und „-“ ( the arrow is the ENTER-key again) the DIV-value will be changed and the indicated voltage at the terminal will be changed consequently. Adjust the indicated value until it is as close as possible to the value at your voltmeter.

By typing in „=“ this calibration step will be finished and the new divider-ratio is stored in the Brenner8.

### 1.1.4 Step No. 3: Regulator-Adjustment

Finally usburn has to determine the individual reaction of the Vpp-source of you Brenner8.
This is done automatically and needs some seconds (6 seconds).

During this process voltage of up to 30 volts can be applied to the Testsocket and the ICSP-connector of the Brenner8. No target-PIC should be in the testsocket or connected to the ICSP-Connector during calibration, or it may be destroyed!

After this some values are presented in the terminal. They may be helpful in the case of an malfunction-analysis

To check out the function the Brenner8 generates now Vpp-levels of 10V, 11V, 12V and 13V after you press the Enter-key. The acceptable voltage error is about 0.3V.

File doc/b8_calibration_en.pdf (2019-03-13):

Brenner8 Manual

- 34 -

## 8 Calibration

After the assembly of the Brenner8, the programming of the control PIC and the installation of the USB-driver the Vpp-generation of the Brenner8 has to be calibrated.

A non-calibrated Brenner8 can destroy every target-PIC in shortest time! It can produce Vpp-voltages of 25V and above. No PIC survives this!

A small boost-converter is used in the Brenner8 to generate the programming voltage Vpp. The voltage level can be controlled by software. Such every target-PIC gets its ideal programming voltage.
This can function only if the control PIC of the Brenner8 can measure the Vpp level precisely.

The programming voltage is measured by the control PIC via a voltage-divider and compared with a reference voltage (from a zener-diode). During calibration Z-voltage and voltage-divider-ratio are determined.

For the calibration is needed:
- Brenner8
- US-Burn-software
- voltmeter

### 8.1 Preparation

Connect the Brenner8 with the PC.
Start the US-Burn software on the PC.
In US-Burn select Options – Hardware.

The following adjustments are done in the „Box“ programming voltage Vpp calibration in 3 steps:

1. setting the Z-voltage
2. setting the voltage-divider-ratio
3. automatic adjustment of offset and gain

### 8.2 Step No. 1: Z-Voltage

The Brenner8 contains a 3,3V-Z-diode. Because typical Z-diodes have tolerances of up to 10%, the real Z-voltage has to be measured.
A voltmeter has to be connected between GND/Vss and Pin 5 of the control-PIC. The latest Brenner8-revisions have a test-point LSP2 for the Z-voltage determination. The measured voltage is entered into the Z-voltage Z-voltage field of US-Burn. The both arrow-buttons can be used to adjust the value between 2V and 4V in 0,01V-steps.
To apply the modified Z-voltage setting, the apply–button has to be used.
(In the BASIC–page of US-Burn is now a calibration value indicated, that should be a little bit smaller than 1.)


- 35 -

Figure 23 US-Burn - Options-Hardware

### 8.3 Step No. 2: Voltage divider

The Vpp-voltage-divider is made from the both resistors R4 and R5. There default divider ratio is 3.14. The real value may differ a bit and has to be determined now. The setting is done in the U-divider-field.

The voltmeter has to be connected between the cathode of D1 and Vss (alternative via C5). The latest Brenner8-revisions have a test-point LSP1 for the voltage determination.
The sliding control set PWM is used to adjust the voltage to about 13V (check with voltmeter). (The voltage should be high but has not to exceed 14V!)

The Brenner8 measures the voltage too, and indicates its result as Vpp-mess. By adjusting the U-divider -ratio (use the arrow-buttons) the Brenner8-measure-result is approximated to the voltmeter-result as close as possible.

### 8.4 Step No. 3: regulator set-up

The final step doesn’t require a voltmeter anymore. Simply click on auto-adjust offset and gain. The Brenner8 starts an autocalibration process, which takes about 6 seconds to be completed.

During this autocalibration high Vpp-voltages are generated. Because of that no target-PIC has to be in an on-board test socked or connected to the ICSP-connector.

(On the BASIC –page US-Burn indicates some numbers with could be helpful in case of fault analysis.)

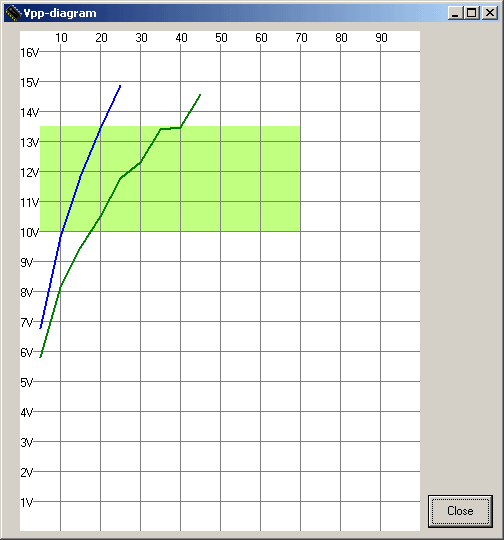
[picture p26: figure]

- 36 -

To test the calibration now the buttons 10V, 11V, 12V and 13V can be used to set Vpp to the desired values. The typical acceptable error is about 0.3V.

### 8.5 Ready

Calibration data is stored in the Brenner8. A backup copy of this data is stored in the usburn.ini .

### 8.6 Error diagnostic

Figure 24 Vpp-diagram - normal
In the field programming voltage test is the button graphic. If one clicks on this button, then a drawing of the Vpp output voltage levels us generated (needs some seconds). The figure shows the voltages Vpp-on (green line) and Vpp-off (blue line) for different duty cycles of the boost converter.

During the drawing process high Vpp-voltages are generated. Because of that no target-PIC has to be in an on-board test socked or connected to the ICSP-connector.

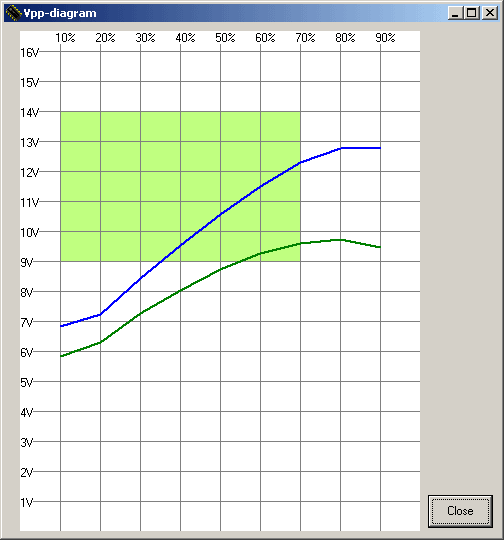
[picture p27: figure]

- 37 -

Only voltages up to 15V can be measured by the Brenner8 and are shown in the diagram. The light green area is the normal working area of the boost converter. The both voltage-lines have to cross this area from bottom to top, like seen in the figure above.

The following diagram shows a bad boost converter. The voltages are to low. This is probably a hardware error, e.g. a wrong type of the diode D1.

Figure 25 Vpp-diagram - undervoltage

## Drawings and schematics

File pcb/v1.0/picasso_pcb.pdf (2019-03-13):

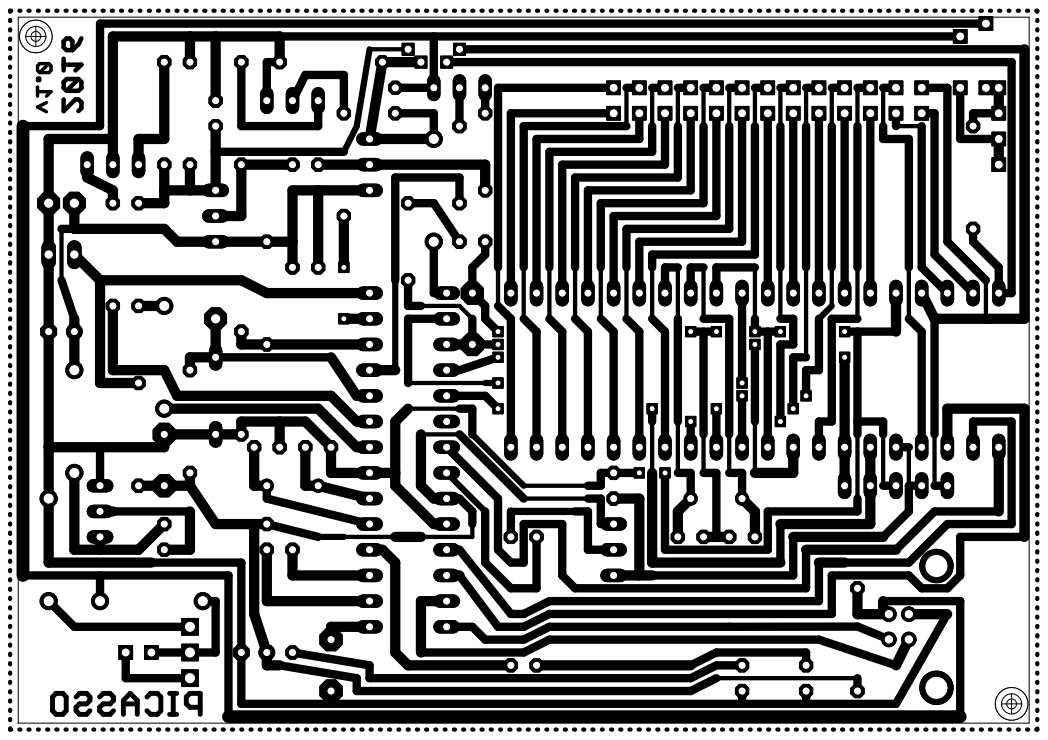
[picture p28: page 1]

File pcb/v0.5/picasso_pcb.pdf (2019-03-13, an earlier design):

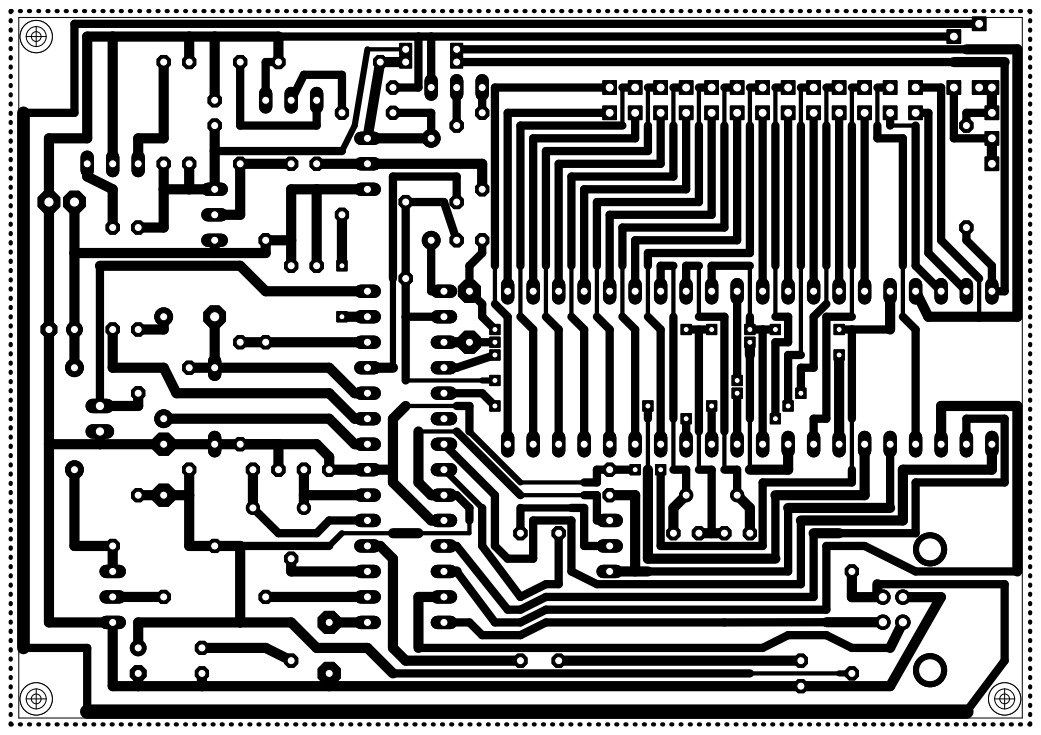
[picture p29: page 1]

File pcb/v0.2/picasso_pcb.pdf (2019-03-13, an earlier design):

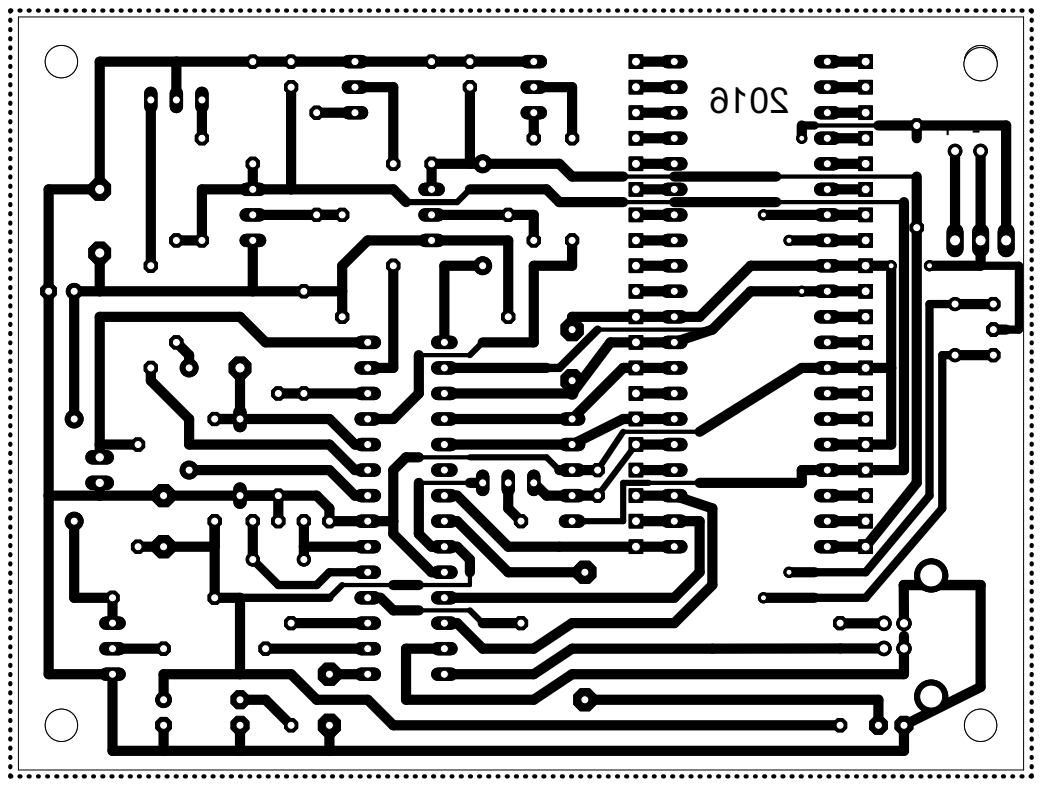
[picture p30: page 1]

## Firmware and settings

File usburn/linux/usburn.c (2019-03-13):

/***************************************************************************
 *            usburn.c
 *
 *  Sund Aug 31 18:57:43 2008
 *  Copyright  2008..2010  Joerg Bredendiek (sprut)
 *
 ****************************************************************************/

/*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
 *  You should have received a copy of the GNU General Public License
 *  along with this program; if not, write to the Free Software
 *  Foundation, Inc., 59 Temple Place - Suite 330, Boston, MA 02111-1307, USA.
 */

/*
 * this is the main-function of usburn
 */


//********************************************************************************************************************
// includes
//********************************************************************************************************************
#include <stdio.h>
#include <stdlib.h>
#include <errno.h>
#include <string.h>

#include "b8.h"



int main(int argc, char* argv[])
{
	int  areg_int;
	word areg_word;

	init_system();

	// flags resetten
	f_r = 0;	// read
	f_w = 0;	// write
	f_c = 0;	// compare
	f_e = 0;	// erase
	f_p = 0;	// remove cp
	f_i = 0;	// info
	f_d = 0;	// reanimation
	f_l = 0;	// list supportet PICs

	f_a = 0;	// autodetect 
	f_b = 0;	// blank check
	f_o = 0;	// activate bootloader
	f_u = 0;	// run mode afer programming
	f_s = 0;	// Vpp before Vdd
	f_h = 0;	// show help information
	f_S = 0;	// change SOCKET
	f_F = 0;	// change Family

	f_n = 0;	// normal-Mode, nicht Bootloader
	f_f = 0;	// load firmware
	f_k = 0;	// calibrate Brenner8
	f_t = 0;	// hardware-test


	/* Flag set by `--verbose'. */
	static int verbose_flag;
     
	int c;
     
	while (1)
	{
		static struct option long_options[] =
		{
 			/* These options set a flag. */
			//{"verbose", no_argument,       &verbose_flag, 1},
			//{"brief",   no_argument,       &verbose_flag, 0},
			/* These options don't set a flag.
			We distinguish them by their indices. */
			{"read",	no_argument,	0, 'r'},
			{"write",	no_argument,	0, 'w'},
			{"compare",	no_argument,	0, 'c'},
			{"erase",	no_argument,	0, 'e'},
			{"remove",	no_argument,	0, 'p'},
			{"info",	no_argument,	0, 'i'},
			{"reanimate",	no_argument,	0, 'd'},
			{"list",	no_argument,	0, 'l'},
			{"auto",	no_argument,	0, 'a'},
			{"blank",	no_argument,	0, 'b'},
			{"firmware",	no_argument,	0, 'f'},
			{"boot",	no_argument,	0, 'o'},
			{"normal",	no_argument,	0, 'n'},
			{"run",		no_argument,	0, 'u'},
			{"swap",	no_argument,	0, 's'},
			{"help",	no_argument,	0, 'h'},
			{"calibrate",	no_argument,	0, 'k'},
			{"test",	no_argument,	0, 't'},

			{"PIC",		required_argument, 0, 'P'},
			{"SOCKET",	required_argument, 0, 'S'},
			{"FAMILY",	required_argument, 0, 'F'},
			{"HEX",		required_argument, 0, 'H'},
			{"TIMING",	required_argument, 0, 'T'},
			{"VPP",		required_argument, 0, 'V'},
			{"OSCCAL",	required_argument, 0, 'L'},
			{"BG",		required_argument, 0, 'B'},
			{"IN",		required_argument, 0, 'I'},
			{"OUT",		required_argument, 0, 'O'},
			 {0, 0, 0, 0}
		};
		/* getopt_long stores the option index here. */
		int option_index = 0;
     
		c = getopt_long (argc, argv, "rwcepidlabfonushktP:S:F:H:T:V:L:B:I:O:",
			long_options, &option_index);
     
		/* Detect the end of the options. */
		if (c == -1)
			break;

		// optarg ist pointer auf char:  "extern char *optarg;"
     
		switch (c)
		{
		case 0:
			/* If this option set a flag, do nothing else now. */
			if (long_options[option_index].flag != 0) break;
			if (f_i)
			{
				printf ("option %s", long_options[option_index].name);
				if (optarg) printf (" with arg %s", optarg);
				printf ("\n");
			}
		break;
     
		case 'r':
			f_r = 1;
			if (f_i) puts ("option -r");
		break;
     		case 'w':
			f_w = 1;
			if (f_i) puts ("option -w");
		break;
     		case 'c':
			f_c = 1;
			if (f_i) puts ("option -c");
		break;
		case 'e':
			f_e = 1;
			if (f_i) puts ("option -e");
		break;
		case 'p':
			f_p = 1;
			if (f_i) puts ("option -p");
		break;
		case 'i':
			f_i = 1;
			if (f_i) puts ("option -i");
		break;
		case 'd':
			f_d = 1;
			if (f_i) puts ("option -d");
		break;
		case 'l':
			f_l = 1;
			if (f_i) puts ("option -l");
		break;
		case 'a':
			f_a = 1;
			if (f_i) puts ("option -a");
		break;
		case 'b':
			f_b = 1;
			if (f_i) puts ("option -b");
		break;
		case 'f':
			f_f = 1;
			if (f_i) puts ("option -f");
		break;
		case 'o':
			f_o = 1;
			if (f_i) puts ("option -o");
		break;
		case 'n':
			f_n = 1;
			if (f_i) puts ("option -n");
		break;
		case 'u':
			f_u = 1;
			if (f_i) puts ("option -u");
		break;
		case 's':
			f_s = 1;
			if (f_i) puts ("option -s");
		break;
		case 'h':
			f_h = 1;
			if (f_i) puts ("option -h");
		break;
		case 'k':
			f_k = 1;
			if (f_i) puts ("option -k");
		break;
		case 't':
			f_t = 1;
			if (f_i) puts ("option -t");
		break;

     
		case 'P':	// PIC
			if (f_i) printf ("option -P with value `%s'\n", optarg);
			strcpy(prog.picname, optarg);
		break;
     		case 'S':	//SOCKET
			f_S = 1;
			if (f_i) printf ("option -S with value `%s'\n", optarg);
			if      (!strcmp(optarg,  "8"))  prog.socket = SOC_8_14;
			else if (!strcmp(optarg, "14"))  prog.socket = SOC_8_14;
			else if (!strcmp(optarg, "20"))  prog.socket = SOC_8_14;
			else if (!strcmp(optarg, "18"))  prog.socket = SOC_18_ICSP;
			else if (!strcmp(optarg, "28"))  prog.socket = SOC_28_40;
			else if (!strcmp(optarg, "40"))  prog.socket = SOC_28_40;
			else if (!strcmp(optarg, "ICSP"))  prog.socket = SOC_18_ICSP;
			else 
			{ fprintf(stderr, "wrong SOCKET-argument %s \n", optarg); f_S = 0;}
			//printf ("socket `%d'\n", prog.socket);
		break;
		case 'F':	//Family
			f_F = 1;
			if (f_i) printf ("option -F with value `%s'\n", optarg);
			if      (!strcmp(optarg, "10"))  prog.core = CORE_12;		// pic10F...
			else if (!strcmp(optarg, "16"))  prog.core = CORE_14;		// pic 16F
			else if (!strcmp(optarg, "18"))  prog.core = CORE_16;		// pic18F
			else if (!strcmp(optarg, "18j")) prog.core = CORE_18;		// pic18J
			else if (!strcmp(optarg, "18J")) prog.core = CORE_18;
			else if (!strcmp(optarg, "18k")) prog.core = CORE_17;		// pic18K
			else if (!strcmp(optarg, "18K")) prog.core = CORE_17;
			else if (!strcmp(optarg, "24"))  prog.core = CORE_33;		// pic24f
			else if (!strcmp(optarg, "30"))  prog.core = CORE_30;		// dspic30F
			else if (!strcmp(optarg, "33"))  prog.core = CORE_33;		// dspic33F
			else 
			{ fprintf(stderr, "wrong Family-argument %s \n", optarg); f_F = 0;}
		break;
     		case 'H':	//HEX-Filename
			if (f_i) printf ("option -H with value `%s'\n", optarg);
			strcpy(prog.InHexfilename, optarg);
			strcpy(prog.OutHexfilename, optarg);
		break;
     		case 'I':	//HexIn-Filename
			if (f_i) printf ("option -I with value `%s'\n", optarg);
			strcpy(prog.InHexfilename, optarg);
		break;
     		case 'O':	//HexOut-Filename
			if (f_i) printf ("option -O with value `%s'\n", optarg);
			strcpy(prog.OutHexfilename, optarg);
		break;
		case 'T':
			if (f_i) printf ("option -T with value `%s'\n", optarg);
		break;
     		case 'V':
			if (f_i) printf ("option -V with value `%s'\n", optarg);
		break;
     		case 'L':
			if (f_i) printf ("option -L with value `%s'\n", optarg);
			strcpy(prog.OsccalString, optarg);
			prog.OsccalPar = atoi(prog.OsccalString);
			// diffrent PIC-families have different OSCCAL-ranges
			// PIC10F: -64 .. 63
			// PIC12F:  00 .. 63
			if (f_i) fprintf(stdout, "OSCCAL %d in parameter \n", prog.OsccalPar);
			/*
			areg_word = ((prog.OsccalPar<<1) & 0x00FF) | MOVLW_12; 
			fprintf(stdout, "fuer 12bit: %5.4x \n", areg_word);
			areg_word = ((prog.OsccalPar<<2) &0x00FF) | RETLW_14; 
			fprintf(stdout, "fuer 14bit: %5.4x \n", areg_word);
			*/
		break;
     
     		case 'B':
			prog.BGnewvalue = 0x0000;
			if (f_i) printf ("option -B with value `%s'\n", optarg);
			strcpy(prog.BGString, optarg);
			prog.BGnewvalue = atoi(prog.BGString);
			if (f_i) fprintf(stdout, "BG %5.4x in parameter \n", prog.BGnewvalue);
		break;
     
		case '?':
			/*getopt_long already printed an error message. */
		break;
     
		default:
			abort ();
             }
         }
     
	/* Instead of reporting `--verbose'
	and `--brief' as they are encountered,
	we report the final status resulting from them. */
	if (verbose_flag) puts ("verbose flag is set");
     
	/* Print any remaining command line arguments (not options). */
	if (optind < argc)
	{
		printf ("non-option ARGV-elements: ");
		while (optind < argc) printf ("%s ", argv[optind++]);
		putchar ('\n');
	}
     


	//help
	if (f_h)
	{
		puts(tietel);
		puts("\nBackend-tool for USB-PIC-programmer Brenner8 & Brenner9 (www.sprut.de)");
		puts("");
		puts("usburn <options>");
		puts("");
		puts("Options without parameters:");
		puts("-h --help        schow this help-screen");
		puts("-r --read        read PIC-content into HEX-file");
		puts("-w --write       write HEX-file into PIC");
		puts("-c --compare     compare PIC-content with HEX-file");
		puts("-e --erase       erase PIC");
		puts("-p --remove      remove codeprotection from PIC");
		puts("-i --info        show a lot of nonnecessary information");
		puts("-d --reanimate   reanimate a PIC, that dont reacts anymore");
		puts("-l --list        list all supported PIC-types");
		puts("-a --auto        autodetect PIC-type");
		puts("-b --blank       check if the PIC is blank");
		puts("-f --firmware    load new firmware");
		puts("-o --boot        switch programmer into bootloader-mode");
		puts("-n --normal      deactivate bootloader-mode");
		puts("-u --run         activate Vdd for target-PIC");		
		puts("-t --test        interactive test of the hardware");
		puts("");
		puts("");
		puts("Options with parameters:");
		puts("-S --SOCKET        PIC-Socket(Brenner8 only) or ICSP-connector");
		puts("           -S8    --SOCKET 8      8-pin-DIL-socket");
		puts("           -S14   --SOCKET 14    14-pin-DIL-socket");
		puts("           -S18   --SOCKET 18    18-pin-DIL-socket");
		puts("           -S20   --SOCKET 20    20-pin-DIL-socket");
		puts("           -S28   --SOCKET 28    28-pin-DIL-socket");
		puts("           -S40   --SOCKET 40    40-pin-DIL-socket");
		puts("           -SICSP --SOCKET ICSP  ICSP-connector");
		puts("");
		puts("-F --FAMILY      PIC-family (core architecture)");
		puts("           -F10   --FAMILY 10    PIC10F..., PIC1xF5...");
		puts("           -F16   --FAMILY 16    PIC16F...");
		puts("           -F18   --FAMILY 18    PIC18F...");
		puts("           -F18J  --FAMILY 18J   PIC18FxxJxx");
		puts("           -F18K  --FAMILY 18K   PIC18FxxKxx");
		puts("           -F24   --FAMILY 24    PIC24...");
		puts("           -F30   --FAMILY 30    dsPIC30F...");
		puts("           -F33   --FAMILY 33    dsPIC33F...");
		puts("");
		puts("-L --OSCCALL     Osccal-Value, only for some PICs");
		puts("           -Onn   --OSCCAL nn    nn is a number from -64 to 63 ");
		puts("");
		puts("-B --BG     BG-value, only for some PICs");
		puts("           -Bnn   --BG nn    nn is a number from 0 to 65535 ");
		puts("");
		puts("-H --HEX         name of HEX-file");
		puts("           -Hname.hex  --HEX name.hex  ");
		puts("-I --IN          name of output HEX-file (for read)");
		puts("           -Iname.hex  --IN name.hex  ");
		puts("-O --OUT         name of input HEX-file (for write & compare)");
		puts("           -Oname.hex  --OUT name.hex  ");

		puts("");
	}



	puts(tietel);	//"usburn V 0.4 (16.05.2010) by sprut (www.sprut.de)"

//***** B R E N N E R   F I N D E N ********************

	prog.fw = 0;
	fprintf(stdout, "search for Brenner8/9:  ");
	if (search_brenner8() == 0) fprintf(stdout, "detected, Fw: %d\n", prog.fw );
	else
	{
		fprintf(stderr,"## no Brenner8/9 detected - end program");
		cleanup_system();
		return(0);
	}

	if (prog.fw >= 14) prog.WRITE_EDATA_KEY = prog.fw; else prog.WRITE_EDATA_KEY = 0;



//***** F I R M W A R E   V A L I D I E R E N ************

	if (prog.fw > 14) prog_check_firmware();
	

	

//***** H A R D W A R E   T E S T  ***********************

	//test the hardware
	if (f_t)
	{
		if (prog.device == DEVICE_BOOT) 
		{
			fprintf(stderr, "## device in Bootloader-mode, test not possible  --  end program\n");
			cleanup_system();
			return(0);
		}
		
		test_hardware();
		cleanup_system();
		return(0);
	}


//***** B O O T L O A D E R ***********************

	// activate Bootloader	
	if (f_o || f_f)
	{
		if (prog.device != DEVICE_BOOT)
		{
			fprintf(stdout, ">> switch into  bootloader-mode \n");
			firm_boot_on();
			cleanup_system();
			sleep(3);
	
			fprintf(stdout, "search for Bootloader:  ");
			if (search_brenner8() == 0) fprintf(stdout, "detected, Fw: %d\n", prog.fw );
		}

		if (prog.device != DEVICE_BOOT)
		{
			fprintf(stderr, "## could not switch into bootloader-mode - end program\n");
 			cleanup_system();
			return -1;
		}
		
		if (f_f)
			//flash firmware into control-PIC
			if (!firm_upload()) firm_boot_off();

		cleanup_system();
		return 0;
	}


	//deactivate Bootloader (normally not needed)
	if ((f_n) && (prog.device == DEVICE_BOOT))
	{
		firm_boot_off();
		return 0;
	}
	// if still in Bootloader-Mode, then quit
	if (prog.device == DEVICE_BOOT) return 0;



//***** C A L I B R A T I O N ***********************

	// read control-PIC-EEPROM , i need this data only for Brenner8
	if (prog.device == DEVICE_B8)
	{
		cal_read_data();

		prog_set_an(1); // Uz
		float Uz = (float)prog_read_adc()/1024*5;
		prog_set_an(0); // vpp
		prog.d_korr =  	Uz / prog.d_Uz;
		if (f_i)
		{
			fprintf(stdout, "Uz %f V \n", Uz);
			fprintf(stdout, "Vpp %f V \n", (float)prog_read_adc()/1024*5*prog.d_DIV);
			fprintf(stdout, "korr %f V \n", prog.d_korr);
		}

		float VppSoll = 13;
		unsigned char pwm_off = d2c(VppSoll * prog.d_gain_off - prog.d_pwm0v_off);
		unsigned char pwm_on  = d2c(VppSoll * prog.d_gain_on  - prog.d_pwm0v_on);
		prog_set_pwm( pwm_off,  pwm_on);
	}



	// Korrekturwert für aktuelle Betriebsspannung ermitteln
	prog.d_Vusb_cal = cal_Kalibrierespannung();	// liefert aktuelle USB-Spannung
	//cal_Kalibrierespannung();


	
	//calibration of the Brenner8
	if ((f_k) && (prog.device == DEVICE_B8))
	{
		char taste;
		fprintf(stdout, "\n>> Programmer calibration \n\n  ");
		puts("+++ W A R N I G  / W A R N U N G +++");
		puts("Remove PIC from testsocket and ICSP-connector! ");
		puts("PIC aus Testfassung und ICSP-Verbinder entfernen! ");
		puts(" press ENTER to continue ");
		puts(" ");
		taste = getc (stdin);

		//Uz einstellen
		fprintf(stdout, "\n>> Programmer calibration\n  1. Step: adjust Uz, use + and - , press = if ready \n");
		do
		{
			fprintf(stdout, "Uz %f V \n", prog.d_Uz);
			taste = getc (stdin);
			if (taste == '+') prog.d_Uz += 0.01;
			if (taste == '-') prog.d_Uz -= 0.01;
		} while (taste != '=');	// ((taste == '+') || (taste == '-'));

		//Div einstellen
		fprintf(stdout, "\n>> Programmer calibration\n  2. Step: adjust Div, use + and - , press = if ready \n");
		do
		{
			fprintf(stdout, "Div %f ,  ", prog.d_DIV);
			float Vpp_div = vpp_getVpp();
			fprintf(stdout, "Vpp-mess %f V \n", Vpp_div );
			taste = getc (stdin);
			if (taste == '+') prog.d_DIV += 0.01;
			if (taste == '-') prog.d_DIV -= 0.01;
		} while (taste != '=');	// ((taste == '+') || (taste == '-'));

		//Regelsteilheit ermitteln
		fprintf(stdout, "\n>> Programmer calibration\n  3. Step: \n");
		cal_step3();

		// 10V
		fprintf(stdout, "press ENTER to generate Vpp = 10V \n");
		taste = getc (stdin);
		vpp_setVpp(10);
		fprintf(stdout, ">> now generating %f V \n\n", vpp_getVpp() );

		// 11V
		fprintf(stdout, "press ENTER to generate Vpp = 11V \n");
		taste = getc (stdin);
		vpp_setVpp(11);
		fprintf(stdout, ">> now generating %f V \n\n", vpp_getVpp() );

		// 12V
		fprintf(stdout, "press ENTER to generate Vpp = 12V \n");
		taste = getc (stdin);
		vpp_setVpp(12);
		fprintf(stdout, ">> now generating %f V \n\n", vpp_getVpp() );

		// 13V
		fprintf(stdout, "press ENTER to generate Vpp = 13V \n");
		taste = getc (stdin);
		vpp_setVpp(13);
		fprintf(stdout, ">> now generating %f V \n\n", vpp_getVpp() );

		fprintf(stdout, "press ENTER to quit program\n");
		taste = getc (stdin);

		cleanup_system();
		return 0;
	}



//***** N O R M A L   W O R K ***********************


	// von der Firmware unterstuetzte Familien herausbekommen
	prog_get_supported();

	// list of all supported pics
	if (f_l) db_listpics(0);

	// load Database into memory
	db_load_db();

	// Familie einstellen
	if (f_F) 
	{
		prog_set_core(prog.core);
		// zwangsweise ICSP bei PIC24, dsPIC30/33, PIC10F, PIC18FJ
		if (((prog.core >= CORE_30) || (prog.core == CORE_18) || (prog.core ==CORE_12)) && (prog.socket != SOC_18_ICSP))
		{
			prog.socket = SOC_18_ICSP;
			f_S = 1;
			fprintf(stderr,"## selected ICSP-Connector\n");
		}
	}


	// Sockel einstellen
	if (f_S) prog_set_socket(prog.socket);


	// Familie einstellen
	if (f_F) prog_set_core(prog.core);

	puts(" ");

	//Typ manuell einstellen für PIC10F... und reanimation
	// ansonsten Autodetect
	int chip_id = 0;
	if (f_d || (prog.core == CORE_12))
	{
		if ( !db_findpicname(prog.pic) )
		{
			fprintf(stdout, "selected Type: %s  \n", prog.pic.name);
			prog.chipid = prog.pic.devid.id & prog.pic.devid.idmask;
			prog.revision = 0;
			chip_id = prog.chipid;
		}
		else
		{
			fprintf(stdout, "## no match for: %s  -- end program \n", prog.picname);
			cleanup_system();
			return(-1);
		}
	}
	else
	{
		// Autodetect
		// many modern PICs can handle not more then Vpp=9V
		vpp_setVpp(8.5);
		chip_id = prog_read_chipid();
		if (f_i) fprintf(stdout, "Vpp=8,5V -> Chip-ID: %d Revision %d  ", chip_id, prog.revision);
		// other PICs need a higher Vpp, 12V is a good value
		// but i dont try this with PIC18FxxKxx, they all are limited to 9V
		if ( ((chip_id <= 0) || (chip_id == 0xFFFF)) && (prog.core != CORE_17) )
		{
			vpp_setVpp(12);
			chip_id = prog_read_chipid();
			if (f_i) fprintf(stdout, "Vpp=12V -> Chip-ID: %d Revision %d  ", chip_id, prog.revision);
		}
	}
	if (f_i) fprintf(stdout, "Chip-ID: %d Revision %d  ", chip_id, prog.revision);
	if (db_findpicid(chip_id, prog.pic) >= 0)  
	{
		//PIC exists in database
		fprintf(stdout, "detected Type: %s  Revision: %d \n", prog.pic.name, prog.revision);
		//Flash
		prog.max_flash = prog.pic.pgmmem.max;
		if (prog.core == 18) prog.max_flash = prog.pic.cfgmem.max;
		//EEPROM
		prog.max_ee = prog.pic.eedata.max;  // kein EEPROM  = -1
		if (prog.pic.eedata.max == -1) prog.max_ee = -1;
		// PIC-Typ einstellen
		prog_set_pictype(prog.pic);
		//Vpp einstellen
		fprintf(stdout, "Vpp = %f V \n", prog.pic.vpp.deflt);
		vpp_setVpp(prog.pic.vpp.deflt);
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

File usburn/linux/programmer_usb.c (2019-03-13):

/***************************************************************************
 *            programmer_usb.c
 *
 *  Mon Aug 21 18:54:33 2006
 *  Copyright  2006  Florian Demski
 *  Copyright  2008  Joerg Bredendiek (sprut)
 *
 ****************************************************************************/

/*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
 *  You should have received a copy of the GNU General Public License
 *  along with this program; if not, write to the Free Software
 *  Foundation, Inc., 59 Temple Place - Suite 330, Boston, MA 02111-1307, USA.
 */

/*
 * this file contains all functions for programmer-eccess for normal opperation
 */


//********************************************************************************************************************
// includes
//********************************************************************************************************************
#include <stdio.h>
#include <stdlib.h>
#include <usb.h>
#include <iostream>
#include <time.h>
#include "b8.h"

using namespace std;

//#define DEBUG

struct programmer prog;

 

// warteschleife fuer Millisekunden
void sleepms(unsigned int mseconds)
{
    clock_t goal = mseconds*CLOCKS_PER_SEC/1000 + clock();
    while (goal > clock());
}


// round double to unsigned char
unsigned char d2c(double d)
{
  return d<0?(unsigned char)(d-.5):(unsigned char)(d+.5);
}


// look for programmer
int search_brenner8(void)
{
	struct usb_bus *bus;
	struct usb_device *dev;
	struct usb_interface_descriptor *iface;
	usb_dev_handle *udev;
	int mode, usbmode, ep_in, ep_out;

	usb_find_busses();
	usb_find_devices();

	for (bus = usb_busses; bus; bus = bus->next) {
		for (dev = bus->devices; dev; dev = dev->next) {
			udev = usb_open(dev);

			if (udev) {
				if (dev->descriptor.idVendor == SPRUT_VID &&
				    dev->descriptor.idProduct == SPRUT_PID &&
				    dev->descriptor.bNumConfigurations == 1 &&
				    dev->config[0].bNumInterfaces == 1 &&
				    dev->config[0].interface[0].num_altsetting == 1 &&
				    dev->config[0].interface[0].altsetting[0].bNumEndpoints==2
				    ){
					iface = &dev->config[0].interface[0].altsetting[0];
					mode = MODE_NORMAL;
					usbmode = 0;
					ep_in = 0xFF;
					ep_out = 0xFF;

					// feststellen ob bul oder interrupt benutzt vwerden muss
					if ((iface->endpoint[0].bmAttributes&USB_ENDPOINT_TYPE_MASK) 
						== USB_ENDPOINT_TYPE_INTERRUPT &&
					    (iface->endpoint[1].bmAttributes&USB_ENDPOINT_TYPE_MASK) 
						== USB_ENDPOINT_TYPE_INTERRUPT) {
						
						// normal mode 
						usbmode = MODE_INT;
					}
					if ((iface->endpoint[0].bmAttributes&USB_ENDPOINT_TYPE_MASK) 
						== USB_ENDPOINT_TYPE_BULK &&
					    (iface->endpoint[1].bmAttributes&USB_ENDPOINT_TYPE_MASK) 
						== USB_ENDPOINT_TYPE_BULK) {
						
						// boot loader mode 
						usbmode = MODE_BULK;
						if (f_i) fprintf(stdout, "seems to be in BULK mode\n");
					}

					
					if (usbmode == MODE_INT || usbmode == MODE_BULK) {
						if (iface->endpoint[0].bEndpointAddress & 
							USB_ENDPOINT_DIR_MASK) {
							ep_in = iface->endpoint[0].bEndpointAddress;
						} else {
							ep_out = iface->endpoint[0].bEndpointAddress;
						}
					
						if (iface->endpoint[1].bEndpointAddress & 
							USB_ENDPOINT_DIR_MASK) {
							ep_in = iface->endpoint[1].bEndpointAddress;
						} else {
							ep_out = iface->endpoint[1].bEndpointAddress;
						}
					
						if (ep_in != 0xFF && ep_out != 0xFF) {
							prog.dev = udev;
							prog.ep_in = ep_in & USB_ENDPOINT_ADDRESS_MASK ;
							prog.ep_out = ep_out & USB_ENDPOINT_ADDRESS_MASK ;
							prog.interface = iface->bInterfaceNumber;
							prog.usbmode = usbmode;
							
							/* try to get fw version and programmer type */
							if (!usb_claim_interface(udev, prog.interface)) {
								int rc;
								
								if (f_i) fprintf(stdout, "interface claimed\n");							
								rc = prog_get_version();
								
								if (rc >= 0) {
									if (f_i) fprintf(stdout, "READ_VERSION %d \n", rc);
									prog.fw = (unsigned char) rc;
									
									usb_get_string_simple(prog.dev, 
										dev->descriptor.iProduct, 
										prog.usb_name, sizeof(prog.usb_name));
									
									return 0;
								}
								
								fprintf(stderr, "unexpected answer to READ_VERSION %d \n", rc);
								
								usb_release_interface(udev, prog.interface);
							} else {
								perror("problem claiming interface");
                                                                if (errno = EPERM) fprintf(stderr, "You don't have sufficient rights (try sudo)\n");
 								return -1;
							}
						}
					}
					
				}
				usb_close(udev);
			}
		}
    }
	return -ENODEV;
}


// universal routine to communicate with programmer
// data_in  - pointer to input-Daten
// dataz    - zahl der Input-Bytes
// data_out - pointer zu output daten
// rc       - zahl der output-byte
int programmer_command(unsigned char *data_in, int datasz, unsigned char *data_out)
{
	int rc;
	
#ifdef DEBUG
	int i;
	
	fprintf(stderr, "=>");
	for (i=0; i<datasz; i++) fprintf(stderr, " %02X", data_in[i]);
	fprintf(stderr, "\n");
#endif

	if (prog.usbmode == MODE_INT) {
		rc = usb_interrupt_write(prog.dev, prog.ep_out, (char*)data_in, datasz, TIMEOUT_WRITE);
	} else {
		rc = usb_bulk_write(prog.dev, prog.ep_out, (char*)data_in, datasz, TIMEOUT_WRITE);
	}

	if (rc < 0)		// Fehler
		return rc;
	
	if ((data_in[0] == CMD_RESET) || (data_in[0] == BOOT_RESET)) 
		return 0;
	
	if (rc != datasz) 
		return -EFAULT;
		
	if (prog.usbmode == MODE_INT) {
		rc = usb_interrupt_read(prog.dev, prog.ep_in, (char*)data_out, 
				USB_BLOCKSIZE, TIMEOUT_READ);
	} else {
		rc = usb_bulk_read(prog.dev, prog.ep_in, (char*)data_out, 
				USB_BLOCKSIZE, TIMEOUT_READ);
	}

#ifdef DEBUG
	fprintf(stderr, "<=");
	for (i=0; i<rc; i++) fprintf(stderr, " %02X", data_out[i]);
	fprintf(stderr, "\n");
#endif

	return rc;		
}



// identify sprut-device and
// read version of firmware
// after call in buf:
//	buf[0]	0x00
//	buf[1]	nonsense
//	buf[2]	version (e.g. firmwareversion)
//	buf[3]	device: 0-Brenner8; 1=Bootloader 2=USB4A 3=Brenner9
int prog_get_version(void)
{
	int rc;
	unsigned char cmd[] = { CMD_READ_VERSION };
	unsigned char buf[USB_BLOCKSIZE];
	rc = programmer_command(cmd, sizeof(cmd), buf);
	//fprintf(stdout, "rc %d bu0 %d bu1 %d bu2 %d bu3 %d \n", rc, buf[0], buf[1], buf[2], buf[3]);
	if (rc < 0)	return rc;				//Fehler
	if (rc != 4) return -EFAULT;			//falsche Bytezahl
	if (memcmp(buf, cmd, 1)) return -EFAULT;	// erstes Byte komt nicht zurueck

	prog.fw     = buf[2]; 
	prog.device = buf[3];
	switch (buf[3])
	{
		case 0x00: prog.mode = MODE_NORMAL; fprintf(stdout, " Brenner8 ");  break;	// Brenner8
		case 0x01: prog.mode = MODE_BOOT;   fprintf(stdout, " Bootloader ");break; 	// bootloader
		case 0x03: prog.mode = MODE_NORMAL; fprintf(stdout, " Brenner9 ")  ;break;	// Brenner9
		defautlt:  prog.mode = MODE_NORMAL; return(-1); break; // falsches device
	}
	return (int)buf[2];
}
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

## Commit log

2019-03-13 PCB added for v0.2
2019-03-13 PCB files for 0.2
    [picasso.brd]
2019-03-13 0.5 files added
    [picasso.brd]
2019-03-13 PCB added for 0.5
2019-03-13 Remove pin img
2019-03-13 PCB files added for v1.0
    [picasso.brd]
2019-03-13 US-Burn linux files added
    [calibration.c, programmer_usb.c, test.c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]
2019-03-13 Drivers added

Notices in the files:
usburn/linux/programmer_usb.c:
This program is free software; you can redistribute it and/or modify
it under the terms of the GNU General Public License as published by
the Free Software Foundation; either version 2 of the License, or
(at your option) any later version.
